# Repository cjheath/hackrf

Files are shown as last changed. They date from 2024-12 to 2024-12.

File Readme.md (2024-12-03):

# HackRF

This repository contains hardware designs and software for HackRF,
a low cost, open source Software Defined Radio platform.

HackRF One

(photo by fd0 from https://github.com/fd0/hackrf-one-pictures)

principal author: Michael Ossmann <mike@ossmann.com>

Information on HackRF and purchasing HackRF: https://greatscottgadgets.com/hackrf/

--------------------

# Documentation

Documentation for HackRF can be viewed on [Read the Docs](https://hackrf.readthedocs.io/en/latest/). The raw documentation files for HackRF are in the [docs folder](https://github.com/mossmann/hackrf/tree/master/docs) in this repository and can be built locally by installing [Sphinx Docs](https://www.sphinx-doc.org/en/master/usage/installation.html) and running `make html`. Documentation changes can be submitted through pull request and suggestions can be made as GitHub issues. 

To create a PDF of the HackRF documentation from the HackRF repository while on Ubuntu:
* run `sudo apt install latexmk texlive-latex-extra`
* navigate to hackrf/docs on command line
* run the command `make latex`
* run the command `make latexpdf`

--------------------

# Getting Help

Before asking for help with HackRF, check to see if your question is listed in the [FAQ](https://hackrf.readthedocs.io/en/latest/faq.html).

For assistance with HackRF general use or development, please look at the [issues on the GitHub project](https://github.com/greatscottgadgets/hackrf/issues). This is the preferred place to ask questions so that others may locate the answer to your question in the future.

We invite you to join our community discussions on [Discord](https://discord.gg/rsfMw3rsU8). Note that while technical support requests are welcome here, we do not have support staff on duty at all times. Be sure to also submit an issue on GitHub if you've found a bug or if you want to ensure that your request will be tracked and not overlooked.

If you wish to see past discussions and questions about HackRF, you may also view the [mailing list archives](https://pairlist9.pair.net/pipermail/hackrf-dev/).

GitHub issues on this repository that are labelled "technical support" by Great Scott Gadgets employees can expect a response time of two weeks. We currently do not have expected response times for other GitHub issues or pull requests for this repository.

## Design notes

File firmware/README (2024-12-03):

The primary firmware source code for USB HackRF devices is hackrf_usb.  Most of
the other directories contain firmware source code for test and development.
The common directory contains source code shared by multiple HackRF firmware
projects.  The cpld directory contains HDL source for the CPLD.

The firmware is set up for compilation with the GCC toolchain available here:

https://developer.arm.com/open-source/gnu-toolchain/gnu-rm/downloads

Required dependency:

https://github.com/mossmann/libopencm3

If you are using git, the preferred way to install libopencm3 is to use the
submodule:

$ cd ..
$ git submodule init
$ git submodule update

To build and install a standard firmware image for HackRF One:

$ cd hackrf_usb
$ mkdir build
$ cd build
$ cmake ..
$ make
$ hackrf_spiflash -w hackrf_usb.bin

If you have a Jawbreaker, add -DBOARD=JAWBREAKER to the cmake command.
If you have a rad1o, use -DBOARD=RAD1O instead.

If you get the "`arm-none-eabi-gcc` is not a full path and was not found in the PATH"
error during `cmake ..`, install the
[ARM GNU toolchain](https://developer.arm.com/Tools%20and%20Software/GNU%20Toolchain).
This toolchain is pre-packaged on many platforms and distributions, e.g. on Debian/Ubuntu
you can run `sudo apt-get install gcc-arm-none-eabi` to install it.

If you get the "ModuleNotFoundError: No module named 'yaml'" error during `make`,
run `pip install pyyaml` to install the Python yaml pip package.

It is possible to use a USB Device Firmware Upgrade (DFU) method to load
firmware into RAM.  This is normally only required to recover a device that has
had faulty firmware loaded, but it can also be useful for firmware developers.

For loading firmware into RAM with DFU you will need:

http://dfu-util.sourceforge.net/

To start up HackRF One in DFU mode, hold down the DFU button while powering it
on or while pressing and releasing the RESET button.  Release the DFU button
after the 3V3 LED illuminates.

A .dfu file is built by default when building firmware.  Alternatively you can
use a known good .dfu file from a release package.  Load the firmware into RAM
with:

$ dfu-util --device 1fc9:000c --alt 0 --download hackrf_usb.dfu

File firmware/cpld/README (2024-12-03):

The primary CPLD image is: sgpio_if/default.xsvf

This is a binary file built from HDL source in sgpio_if.  You do not need
Xilinx tools unless you want to make your own modifications.

CPLD images are automatically included in HackRF firmware.  You do not normally
need to update the bitstream stored in the CPLD's flash memory as it is
superseded by the image loaded into SRAM by the firmware.

If you want to update the bitstream in CPLD flash for some reason, first update
the firmware, libhackrf, and hackrf-tools.
Then:

$ hackrf_cpldjtag -x sgpio_if/default.xsvf

After a few seconds, three LEDs should start blinking.  This indicates that the
CPLD has been programmed successfully.  Reset the HackRF device by pressing the
RESET button or by unplugging it and plugging it back in.

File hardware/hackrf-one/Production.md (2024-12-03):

## Making files for production of HackRF One

### Check everything

In eeschema, run Inspect->Electrical Rules Checker

### BOM

In eeschema (schematic editor), select "Tools->Generate Bill of Materials".
Click Export. This creates the file doc/hardware/hackrf-one-gerbers/hackrf-one-bom.csv

### Assembly silk with references

In pcbnew (the PCB editor) select File->Plot....
* Ensure F.SilkS (front silk) layer is selected.
* Select "Use drill/place file origin".
* Deselect "Use Protel filename extensions".
* De-select "Generate Gerber job file".
* Select "Plot reference designators"
* Click "Plot". This puts files into doc/hardware/hackrf-one-gerbers.
* Rename doc/hardware/hackrf-one-gerbers/hackrf-one-F_Silkscreen.gto to doc/hardware/hackrf-one-gerbers/hackrf-one-Placement.gbr

### Gerber files

In pcbnew (the PCB editor) select "Plot...".
* Ensure all required layers are selected: C1F, C2, C3, C4B, F.Paste, F.SilkS, F.Mask, B.Mask, Edge.Cuts
* De-select "Plot references designators"
* Click "Plot".

This puts files into doc/hardware/hackrf-one-gerbers. Change to that directory.

### Drill file

From pcbnew->Plot, select "Generate Drill Files".
* Select "Excellon".
* Tick "Minimal header"
* Tick "PTH and NPTH in single file"
* Select Drill Origin "Drill/place file origin"
* Select Drill Units "Inches"
* Select Zeros Format "Suppress trailing zeros"
* Click "Generate Drill File"

This creates the file "doc/hardware/hackrf-one-gerbers/hackrf-one.drl"

* Click "Generate Map File"
* Click "Generate Report File" and Save

### Placement file

In pcbnew, select File->Fabrication Outputs->Component Placement (.pos) File
Select CSV, Inches, Single file per board.
Click "Generate Position File"
This makes the file doc/hardware/hackrf-one-gerbers/hackrf-one-all-pos.csv

Check the rotation of U3, the low-pass filter. Its footprint is 180 from how they come off the reel.

### Zip it up

cd into doc/hardware/hackrf-one-gerbers
zip -j ../hackrf-one-fabrication-draft-YYYY-NN-DD.zip ../README.production *

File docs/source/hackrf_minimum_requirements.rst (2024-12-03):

============================================
Minimum Host System Requirements for HackRF
============================================

HackRF requires you to supply 500 mA at 5 V DC to your HackRF via the USB port. If your host computer has difficulty meeting this requirement, you may need to use a powered USB hub.

There is no specific minimum CPU requirement for the host computer when using a HackRF, but SDR is generally a CPU-intensive application. If you have a slower CPU, you may be unable to run certain SDR software or you may only be able to operate at lower sample rates.

Most users will want to stream data to or from the HackRF at high speeds. This requires that the host computer supports Hi-Speed USB. Some Hi-Speed USB hosts are better than others, and you may have multiple host controllers on your computer. If you have difficulty operating your HackRF at high sample rates (10 Msps to 20 Msps), try using a different USB port on your computer. If possible, arrange things so that the HackRF is the only device on the bus.

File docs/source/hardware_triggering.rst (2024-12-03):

===================
Hardware Triggering
===================

HackRF One transmit and receive operations can be synchronized with another HackRF One or with other external equipment by using the trigger input and output on pin header P28. Triggering provides time synchronization with error of less than one sample period.

Clock Synchronization
~~~~~~~~~~~~~~~~~~~~~

When triggering one HackRF One from another, it is often desirable to first ensure that the two devices share a common frequency reference. This has an added benefit of grounding the HackRFs to each other, eliminating one of the wires required for triggering. See :ref:`External Clock Interface <external_clock_interface>` for instructions.

Either HackRF One may serve as the clock source for the other regardless of which is providing the trigger output.

Requirements
~~~~~~~~~~~~

To connect two HackRF Ones for triggering you will need:

    * a male-to-male jumper wire for 0.1" pin headers
    * an SMA cable for clock synchronization or a second jumper wire

.. _open_your_hackrf_one:

Open Your HackRF One
~~~~~~~~~~~~~~~~~~~~

If your HackRF Ones are not bare boards, you will need to open up their cases to access the pin headers on the HackRF Ones. Each HackRF One case has small plastic clips holding it together. These clips may be damaged when the case is opened, but typically the case can still be used after such damage. Please follow the instructions in `this video <https://www.youtube.com/watch?v=zuXJtpTSEJM>`__ by `Jared Boone <https://twitter.com/sharebrained>`__ to open your HackRF One cases.

Identify the Trigger Pins
~~~~~~~~~~~~~~~~~~~~~~~~~

HackRF One has four normally-populated pin headers, three of which are arranged in a 'C' shape. On the circuit board these are marked P28, P22, and P20. P28 is the header nearest to the center of the board. Locate pins 15 (trigger output) and 16 (trigger input) on header P28.

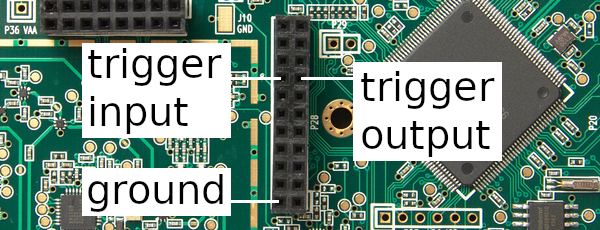
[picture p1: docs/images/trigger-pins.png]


Connect the Trigger Output to the Trigger Input
~~~~~~~~~~~~~~~~~~~~~~~~~~~~~~~~~~~~~~~~~~~~~~~

First ensure that the two devices share a common ground. This may be accomplished by connecting one's CLKIN to the other's CLKOUT as recommended above. Alternatively, connect a jumper wire from P28 pin 2 on one HackRF One to P28 pin 2 on the other HackRF One.

Next use a jumper wire to connect P28 pin 15 (trigger output) on one HackRF One to P28 pin 16 (trigger input) on the other HackRF One.

Usage
~~~~~

Use ``hackrf_info`` to discover the serial numbers of both HackRF Ones. Using the serial number of the HackRF One to be triggered, use ``hackrf_transfer -H`` to set up a triggered operation. For example:

* ``hackrf_transfer -H -d <serial number> -a 0 -l 32 -g 32 -r rx1.cs8``

The command will print "Waiting for trigger..." until a trigger signal is detected on the device's trigger input.

In another terminal, use the serial number of the triggering HackRF One to initiate an operation to take place at the same time as the triggered operation. For example:

* ``hackrf_transfer -d <serial number> -a 0 -l 32 -g 32 -r rx2.cs8``

Note that no special argument is required to activate the trigger output.

Both ``hackrf_transfer`` commands will start sampling RF signals at the same time, accurate to less than one sample period.

Additional Devices
~~~~~~~~~~~~~~~~~~

Multiple HackRF Ones may be triggered by a single HackRF One. Ensure that all the devices share a common ground and then connect one device's trigger output to the trigger inputs of the other devices (with jumpers connected via a breadboard, for example).

Equipment other than a HackRF One may be connected to a HackRF One's trigger input or output. The trigger signal is a 3.3 V pulse that triggers on the rising edge.

References
~~~~~~~~~~

HackRF's trigger mechanism was contributed by the authors of `Synchronisation of Low-Cost Open Source SDRs for Navigation Applications <http://spcomnav.uab.es/docs/conferences/Bartolucci_NAVITEC_2016.pdf>`__ which provides details about the implementation and background.

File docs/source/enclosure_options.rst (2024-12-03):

Enclosure Options
~~~~~~~~~~~~~~~~~

The commercial version of HackRF One from Great Scott Gadgets ships with an injection molded plastic enclosure, but it is designed to fit two optional enclosures:

    * Hammond 1455J1201: HackRF One fits this extruded aluminum enclosure and other similar models from Hammond Manufacturing. In order to use the enclosure's end plates, you will have to drill them. An end plate template can be found in the HackRF One KiCad layout.

    * Acrylic sandwich: You can also use a laser cut acrylic enclosure with HackRF One. This is a good option for access to the expansion headers. A design can be found in the HackRF One hardware directory. Use any laser cutting service or purchase from a `reseller <https://greatscottgadgets.com/hackrf/acrylic-case/>`__.

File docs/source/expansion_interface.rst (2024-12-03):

Expansion Interface
~~~~~~~~~~~~~~~~~~~

The HackRF One expansion interface consists of headers P9, P20, P22, and P28. These four headers are installed on the commercial HackRF One from Great Scott Gadgets.

P9 Baseband 
^^^^^^^^^^^

A direct analog interface to the high speed dual ADC and dual DAC.

.. list-table :: 
  :header-rows: 1
  :widths: 1 1 

  * - Pin
    - Function
  * - 1     
    - GND
  * - 2   
    - GND
  * - 3
    - GND
  * - 4   
    - RXBBQ-
  * - 5   
    - RXBBI-
  * - 6   
    - RXBBQ+
  * - 7   
    - RXBBI+
  * - 8   
    - GND
  * - 9   
    - GND
  * - 10  
    - TXBBI-
  * - 11  
    - TXBBQ+
  * - 12  
    - TXBBI+
  * - 13  
    - TXBBQ-
  * - 14  
    - GND
  * - 15  
    - GND
  * - 16  
    - GND

P20 GPIO
^^^^^^^^

Providing access to GPIO, ADC, RTC, and power.

.. list-table :: 
  :header-rows: 1
  :widths: 1 1 

  * - Pin 
    - Function
  * - 1   
    - VBAT
  * - 2   
    - RTC_ALARM
  * - 3   
    - VCC
  * - 4   
    - WAKEUP
  * - 5   
    - GPIO3_8
  * - 6   
    - GPIO3_0
  * - 7   
    - GPIO3_10
  * - 8   
    - GPIO3_11
  * - 9   
    - GPIO3_12
  * - 10  
    - GPIO3_13
  * - 11  
    - GPIO3_14
  * - 12  
    - GPIO3_15
  * - 13  
    - GND
  * - 14  
    - ADC0_6
  * - 15  
    - GND
  * - 16  
    - ADC0_2
  * - 17  
    - VBUSCTRL
  * - 18  
    - ADC0_5
  * - 19  
    - GND
  * - 20  
    - ADC0_0
  * - 21  
    - VBUS
  * - 22  
    - VIN

P22 I2S
^^^^^^^

I2S, SPI, I2C, UART, GPIO, and clocks.

.. list-table :: 
  :header-rows: 1
  :widths: 1 1 

  * - Pin     
    - Function
  * - 1   
    - CLKOUT
  * - 2   
    - CLKIN
  * - 3   
    - RESET
  * - 4   
    - GND
  * - 5   
    - I2C1_SCL
  * - 6   
    - I2C1_SDA
  * - 7   
    - SPIFI_MISO
  * - 8   
    - SPIFI_SCK
  * - 9   
    - SPIFI_MOSI
  * - 10  
    - GND
  * - 11  
    - VCC
  * - 12  
    - I2S0_RX_SCK
  * - 13  
    - I2S_RX_SDA
  * - 14  
    - I2S0_RX_MCLK
  * - 15  
    - I2S0_RX_WS
  * - 16  
    - I2S0_TX_SCK
  * - 17  
    - I2S0_TX_MCLK
  * - 18  
    - GND
  * - 19  
    - U0_RXD
  * - 20  
    - U0_TXD
  * - 21  
    - P2_9
  * - 22  
    - P2_13
  * - 23  
    - P2_8
  * - 24  
    - SDA
  * - 25  
    - CLK6
  * - 26  
    - SCL

P28 SD
^^^^^^

SDIO, GPIO, clocks, and CPLD.

.. list-table :: 
  :header-rows: 1
  :widths: 1 1 

  * - Pin     
    - Function
  * - 1   
    - VCC
  * - 2   
    - GND
  * - 3   
    - SD_CD
  * - 4   
    - SD_DAT3
  * - 5   
    - SD_DAT2
  * - 6   
    - SD_DAT1
  * - 7   
    - SD_DAT0
  * - 8   
    - SD_VOLT0
  * - 9   
    - SD_CMD
  * - 10  
    - SD_POW
  * - 11  
    - SD_CLK
  * - 12  
    - GND
  * - 13  
    - GCK2
  * - 14  
    - GCK1
  * - 15  
    - B1AUX14 (trigger output)
  * - 16  
    - B1AUX13 (trigger input)
  * - 17  
    - CPLD_TCK
  * - 18  
    - BANK2F3M2
  * - 19  
    - CPLD_TDI
  * - 20  
    - BANK2F3M6
  * - 21  
    - BANK2F3M12
  * - 22  
    - BANK2F3M4

Additional unpopulated headers and test points are available for test and development, but they may be incompatible with some enclosure or expansion options.

Refer to the schematics and component documentation for more information.

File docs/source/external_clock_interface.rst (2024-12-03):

===========================================
External Clock Interface (CLKIN and CLKOUT)
===========================================

.. _external_clock_interface:

HackRF One produces a 10 MHz clock signal on CLKOUT. The signal is a 3.3 V, 10 MHz square wave intended for a high impedance load.

The CLKIN port on HackRF One is a high impedance input that expects 3.3 V square wave at 10 MHz. Do not exceed 3.3 V or drop below 0 V on this input. Do not connect a clock signal at a frequency other than 10 MHz (unless you modify the firmware to support this). You may directly connect the CLKOUT port of one HackRF One to the CLKIN port of another HackRF One.

HackRF One uses CLKIN instead of the internal crystal when a clock signal is detected on CLKIN. The switch to or from CLKIN only happens when a transmit or receive operation begins.

To verify that a signal has been detected on CLKIN, use ``hackrf_clock -i``. The expected output with a clock detected is `CLKIN status: clock signal detected`. The expected output with no clock detected is `CLKIN status: no clock signal detected`.

To activate CLKOUT, use ``hackrf_clock -o 1``. To switch it off, use ``hackrf_clock -o 0``.

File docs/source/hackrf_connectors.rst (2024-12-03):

==========
Connectors
==========

The connectors on HackRF One are SMA. 

**Note:** SMA connectors and RP-SMA connectors are visually very similar. If you connect an RP-SMA antenna to HackRF One, it will seem to connect snugly but won't function at all because neither the male nor female side has a center pin. RP-SMA connectors are most common on 2.4 GHz antennas and are popular on Wi-Fi equipment. Adapters are available.

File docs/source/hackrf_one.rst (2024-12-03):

================================================
HackRF One
================================================

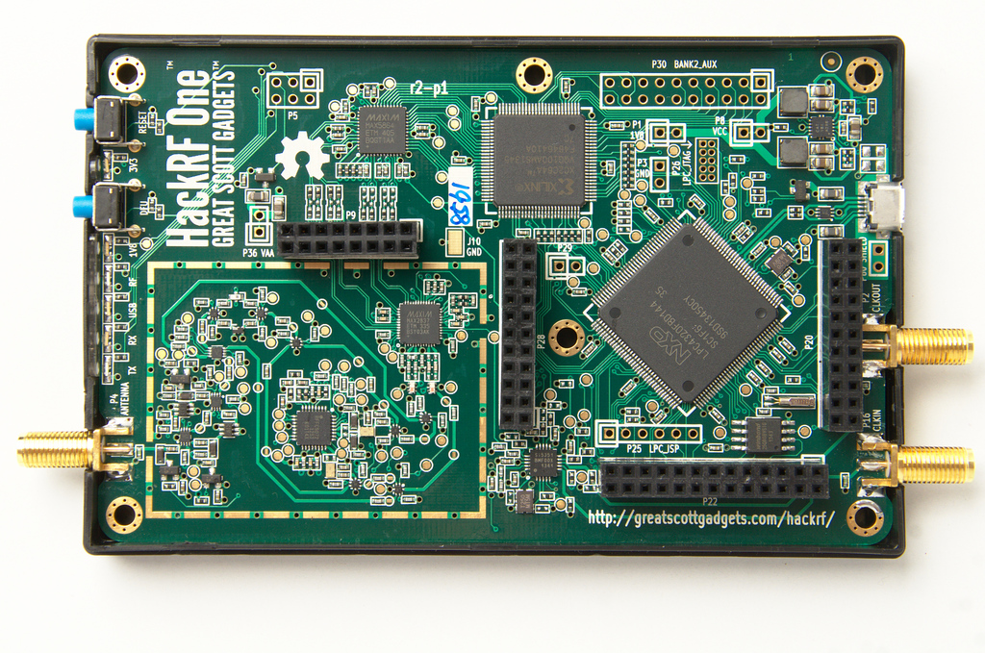
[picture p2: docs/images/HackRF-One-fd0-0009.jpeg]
HackRF One


HackRF One is the current hardware platform for the HackRF project. It is a Software Defined Radio peripheral capable of transmission or reception of radio signals from 1 MHz to 6 GHz. Designed to enable test and development of modern and next generation radio technologies, HackRF One is an open source hardware platform that can be used as a USB peripheral or programmed for stand-alone operation.

Features
~~~~~~~~

    * half-duplex transceiver
    * operating freq: 1 MHz to 6 GHz
    * supported sample rates: 2 Msps to 20 Msps (quadrature)
    * resolution: 8 bits
    * interface: High Speed USB (with USB Micro-B connector)
    * power supply: USB bus power
    * software-controlled antenna port power (max 50 mA at 3.0 to 3.3 V)
    * SMA female antenna connector (50 ohms)
    * SMA female clock input and output for synchronization
    * convenient buttons for programming
    * pin headers for expansion
    * portable
    * open source

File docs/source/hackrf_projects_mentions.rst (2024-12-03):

================================================
HackRF Community Projects and Mentions
================================================

Have you done something cool with HackRF or mentioned HackRF in one of your presentations? Let us know and we might post a link here!

* `HackRF vs. Tesla Model S <https://www.youtube.com/watch?v=575TcQJJWok>`__ (Sam Edwards)
* `Jawbreaker/VFD spectrum analyzer <http://www.sharebrained.com/2013/05/21/maker-faire-radio-spectrum-analyzer/>`__ (Jared Boone)
* `LEGO car <http://ossmann.blogspot.com/2013/06/hackrf-lego-car.html>`__ (Michael Ossmann)
* `wireless microphones <http://www.sharebrained.com/2013/06/15/wireless-microphones-and-hackrf/>`__ (Jared Boone)
* `Tesla Charging Port Opener <https://github.com/rgerganov/tesla-opener>`__ (Radoslav Gerganov)
* `Hacking my smart tooth brush <https://kuenzi.dev/toothbrush/>`__ (Cyrill Künzi)

Retired Projects
~~~~~~~~~~~~~~~~

* Automotive Remote Keyless Entry Systems (Mike Kershaw)
* Decoding Pocsag Pagers With The HackRF (BinaryRF)
* Sniffing GSM with HackRF (BinaryRF)

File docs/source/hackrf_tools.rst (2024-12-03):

============
HackRF Tools
============

Great Scott Gadgets provides some commandline tools for interacting with HackRF. 
    * **hackrf_info** Read device information from HackRF such as serial number and firmware version.

    * **hackrf_transfer** Send and receive signals using HackRF. Input/output files are 8-bit signed quadrature samples.

    * **hackrf_sweep**, a command-line spectrum analyzer.

    * **hackrf_clock** Read and write clock input and output configuration.

    * **hackrf_operacake** Configure Opera Cake antenna switch connected to HackRF.

    * **hackrf_spiflash** A tool to write new firmware to HackRF. See: :ref:`Updating Firmware <updating_firmware>`.

    * **hackrf_debug** Read and write registers and other low-level configuration for debugging.

hackrf_sweep
~~~~~~~~~~~~

Usage
^^^^^

.. code-block:: sh 

    [-h] # this help
    [-d serial_number] # Serial number of desired HackRF
    [-a amp_enable] # RX RF amplifier 1=Enable, 0=Disable
    [-f freq_min:freq_max] # minimum and maximum frequencies in MHz
    [-p antenna_enable] # Antenna port power, 1=Enable, 0=Disable
    [-l gain_db] # RX LNA (IF) gain, 0-40dB, 8dB steps
    [-g gain_db] # RX VGA (baseband) gain, 0-62dB, 2dB steps
    [-w bin_width] # FFT bin width (frequency resolution) in Hz, 2445-5000000
    [-1] # one shot mode
    [-N num_sweeps] # Number of sweeps to perform
    [-B] # binary output
    [-I] # binary inverse FFT output
    -r filename # output file

Output fields
^^^^^^^^^^^^^

``date, time, hz_low, hz_high, hz_bin_width, num_samples, dB, dB, ...``

Running ``hackrf_sweep -f 2400:2490`` gives the following example results:

.. list-table :: 
  :header-rows: 1
  :widths: 1 1 1 1 1 1 1 1 1 1 1

  * - Date  
    - Time  
    - Hz Low    
    - Hz High   
    - Hz bin width  
    - Num Samples   
    - dB    
    - dB    
    - dB    
    - dB    
    - dB
  * - 2019-01-03    
    - 11:57:34.967805   
    - 2400000000    
    - 2405000000    
    - 1000000.00    
    - 20    
    - -64.72    
    - -63.36    
    - -60.91    
    - -61.74    
    - -58.58
  * - 2019-01-03    
    - 11:57:34.967805   
    - 2410000000    
    - 2415000000    
    - 1000000.00    
    - 20    
    - -69.22    
    - -60.67    
    - -59.50    
    - -61.81    
    - -58.16
  * - 2019-01-03    
    - 11:57:34.967805   
    - 2405000000    
    - 2410000000    
    - 1000000.00    
    - 20    
    - -61.19    
    - -70.14    
    - -60.10    
    - -57.91    
    - -61.97
  * - 2019-01-03    
    - 11:57:34.967805   
    - 2415000000    
    - 2420000000    
    - 1000000.00    
    - 20    
    - -72.93    
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

Each sweep across the entire specified frequency range is given a single time stamp.

The fifth column tells you the width in Hz (1 MHz in this case) of each frequency bin, which you can set with ``-w``. The sixth column is the number of samples analyzed to produce that row of data.

Each of the remaining columns shows the power detected in each of several frequency bins. In this case there are five bins, the first from 2400 to 2401 MHz, the second from 2401 to 2402 MHz, and so forth.

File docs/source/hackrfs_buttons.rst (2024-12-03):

=======
Buttons
=======

The **RESET button** resets the microcontroller. This is a reboot that should result in a USB re-enumeration.

The **DFU button** invokes a USB DFU bootloader located in the microcontroller's ROM. This bootloader makes it possible to unbrick a HackRF One with damaged firmware because the ROM cannot be overwritten.

The DFU button only invokes the bootloader during reset. This means that it can be used for other functions by custom firmware.

To invoke DFU mode: Press and hold the DFU button. While holding the DFU button, reset the HackRF One either by pressing and releasing the RESET button or by powering on the HackRF One. Release the DFU button.

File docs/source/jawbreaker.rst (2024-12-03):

==========
Jawbreaker
==========

HackRF Jawbreaker is the beta test hardware platform for the HackRF project.

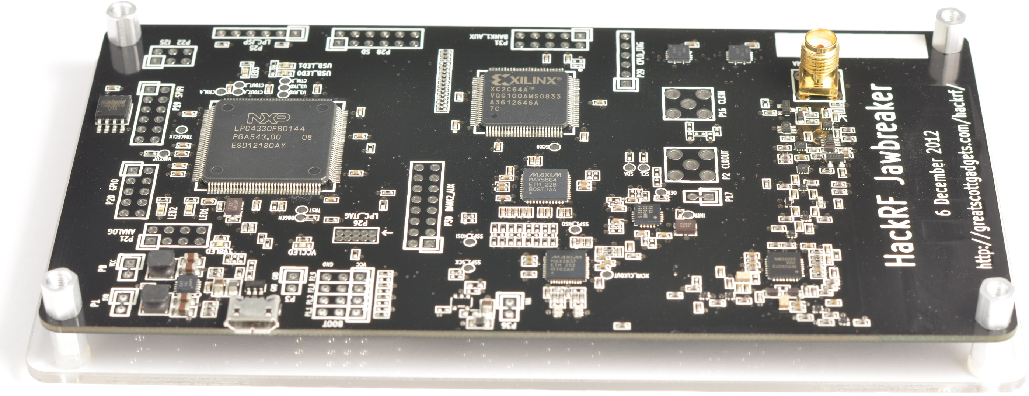
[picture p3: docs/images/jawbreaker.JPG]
Jawbreaker


(Jawbreaker picture provided by `fd0 <https://github.com/fd0>`__ with Creative Commons License CC BY 3.0.)

Features
~~~~~~~~

    * half-duplex transceiver
    * operating freq: 30 MHz to 6 GHz
    * supported sample rates: 8 Msps to 20 Msps (quadrature)
    * resolution: 8 bits
    * interface: High Speed USB (with USB Micro-B connector)
    * power supply: USB bus power
    * portable
    * open source

Hardware Documentation
~~~~~~~~~~~~~~~~~~~~~~

Schematic diagram, assembly diagram, and bill of materials can be found at `https://github.com/greatscottgadgets/hackrf/tree/master/hardware <https://github.com/greatscottgadgets/hackrf/tree/master/hardware>`__

Transmit Power
~~~~~~~~~~~~~~

The maximum TX power for Jawbreaker varies by operating frequency:

    * 30 MHz to 100 MHz: 5 dBm to 15 dBm, increasing as frequency decreases
    * 100 MHz to 2300 MHz: 0 dBm to 10 dBm, increasing as frequency decreases
    * 2170 MHz to 2740 MHz: 10 dBm to 15 dBm
    * 2700 MHz to 4000 MHz: -5 dBm to 5 dBm, increasing as frequency decreases
    * 4000 MHz to 6000 MHz: -15 dBm to 0 dBm, increasing as frequency decreases

Overall, the output power is enough to perform over-the-air experiments at close range or to drive an external amplifier. If you connect an external amplifier, you should also use an external bandpass filter for your operating frequency.

Before you transmit, know the laws for the region you are transmitting in. Jawbreaker has not been tested for compliance with regulations governing transmission of radio signals. You are responsible for using your Jawbreaker legally.

SMA, not RP-SMA
~~~~~~~~~~~~~~~

The connectors on Jawbreaker are SMA, not RP-SMA. SMA connectors and RP-SMA connectors look extremely similar, the difference is that SMA connectors have a center pin. RP-SMA connectors are common on 2.4 GHz antennas and are popular on Wi-Fi equipment. If you connect an RP-SMA antenna to Jawbreaker, it will seem to connect snugly but won't function at all because neither the male nor female side has a center pin. 

Recommended PCB and Antenna Changes
~~~~~~~~~~~~~~~~~~~~~~~~~~~~~~~~~~~

Jawbreaker has an SMA antenna connector and it also includes a built-in PCB antenna intended for operation near 900 MHz. The built-in PCB antenna isn't a very good antenna. A paperclip stuck into the SMA connector of the Jawbreaker is likely to be better. We recommend that you free your Jawbreaker to operate with better antennas by cutting the PCB trace to the PCB antenna with a knife. This enables the SMA connector to be used without interference from the PCB antenna.

The trace to be cut is between the two solder pads inside a box labeled R44. There is an arrow printed on the board that points to the R44 box. A video that demonstrates the antenna modification is on YouTube: `HackRF Antenna Modification <http://youtu.be/B2gwgNoqMxI>`__.

Due to a manufacturing error, there is solder on the pads in box R44 that you should try to remove before you cut the trace. R44 may appear as a single solder blob. If you have a soldering iron and solder wick/braid, use a soldering iron and fine solder wick to remove as much solder as you can from the two R44 pads. Then, use a pen knife to gently cut away the area between the two R44 pads. Make multiple, gentle cuts, instead of one or two forceful cuts. As you cut, you'll break through the black solder mask, then the copper trace between the pads, and stop when you reach fiberglass. Remove the copper trace completely, so just the two R44 pads remain. Use a multimeter or continuity tester to verify that the two R44 pads are no longer connected. If you don't have a soldering iron, you can cut through the copper trace and the solder blob all at once, but it requires a bit more effort. The only reason not to cut the PCB trace is if you want to try Jawbreaker but don't have any antenna with an SMA connector (or adapter).

If you want to restore the PCB antenna for some reason, you can install a 10 nF capacitor or a 0 ohm resistor on the R44 pads or you may be able to simply create a solder bridge.

Expansion Interface
~~~~~~~~~~~~~~~~~~~

LPC
^^^
Boot config
+++++++++++

Default boot configuration is SPIFI. Install headers and jumpers (and optionally resistors) to reconfigure.

.. list-table :: 
  :header-rows: 1
  :widths: 1 1 1 1 1

  * - Pin 	
    - P43 	
    - P32 	
    - P42 	
    - P27
  * - 1 	
    - VCC 	
    - VCC 	
    - VCC 	
    - VCC
  * - 2 	
    - P2_9 	
    - P2_8 	
    - P1_2 	
    - P1_1
  * - 3 	
    - GND 	
    - GND 	
    - GND 	
    - GND

The table below shows which pins to short per header for a given selection.

.. list-table :: 
  :header-rows: 1
  :widths: 1 1 1 1 1

  * - Selection 	
    - P43 	
    - P32 	
    - P42 	
    - P27
  * - USART0 	
    - 2-3 	
    - 2-3 	
    - 2-3 	
    - 2-3
  * - SPIFI 	
    - 2-3 	
    - 2-3 	
    - 2-3 	
    - 1-2
  * - USB0 	
    - 2-3 	
    - 1-2 	
    - 2-3 	
    - 1-2
  * - USSP0 	
    - 2-3 	
    - 1-2 	
    - 1-2 	
    - 1-2
  * - USART3 	
    - 1-2 	
    - 2-3 	
    - 2-3 	
    - 2-3

P19 SPIFI Intercept header
++++++++++++++++++++++++++

Traces may be cut to install header and jumpers or use off-board SPI flash.

.. list-table :: 
  :header-rows: 1
  :widths: 1 1

  * - Pin 	
    - Function
  * - 1 	
    - Flash DO
  * - 2 	
    - SPIFI_MISO
  * - 3 	
    - Flash DI
  * - 4 	
    - SPIFI_MOSI
  * - 5 	
    - Flash CLK
  * - 6 	
    - SPIFI_SCK
  * - 7 	
    - Flash CS
  * - 8 	
    - SPIFI_CS
  * - 9 	
    - Flash Hold
  * - 10 	
    - SPIFI_SIO3
  * - 11 	
    - Flash WP
  * - 12 	
    - SPIFI_SIO2

P20 GPIO
++++++++

.. list-table :: 
  :header-rows: 1
  :widths: 1 1

  * - Pin 	
    - Function
  * - 1 	
    - GPIO3_8
  * - 2 	
    - GPIO3_9
  * - 3 	
    - GPIO3_10
  * - 4 	
    - GPIO3_11
  * - 5 	
    - GPIO3_12
  * - 6 	
    - GPIO3_13
  * - 7 	
    - GPIO3_14
  * - 8 	
    - GPIO3_15
  * - 9 	
    - GND
  * - 10 	
    - GND

P21 Analog
++++++++++

.. list-table :: 
  :header-rows: 1
  :widths: 1 1

  * - Pin 	
    - Function
  * - 1 	
    - GND
  * - 2 	
    - ADC0_6
  * - 3 	
    - GND
  * - 4 	
    - ADC0_2
  * - 5 	
    - GND
  * - 6 	
    - ADC0_5
  * - 7 	
    - GND
  * - 8 	
    - ADC0_0

P22 I2S
+++++++

.. list-table :: 
  :header-rows: 1
  :widths: 1 1

  * - Pin 	
    - Function
  * - 1 	
    - VCC
  * - 2 	
    - I2S0_TX_SDA
  * - 3 	
    - I2S0_TX_WS
  * - 4 	
    - I2S0_TX_SCK
  * - 5 	
    - I2S0_TX_MCLK
  * - 6 	
    - GND

P25 LPC_ISP
+++++++++++

.. list-table :: 
  :header-rows: 1
  :widths: 1 1

  * - Pin 	
    - Function
  * - 1 	
    - GND
  * - 2 	
    - ISP
  * - 3 	
    - NC
  * - 4 	
    - U0_RXD
  * - 5 	
    - U0_TXD
  * - 6 	
    - RESET

P26 LPC_JTAG
++++++++++++

.. list-table :: 
  :header-rows: 1
  :widths: 1 1

  * - Pin 	
    - Function
  * - 1 	
    - VCC
  * - 2 	
    - TMS
  * - 3 	
    - GND
  * - 4 	
    - TCK
  * - 5 	
    - GND
  * - 6 	
    - TDO
  * - 7 	
    - NC
  * - 8 	
    - TDI
  * - 9 	
    - GND
  * - 10 	
    - RESET

P28 SD
++++++

.. list-table :: 
  :header-rows: 1
  :widths: 1 1

  * - Pin 	
    - Function
  * - 1 	
    - GND
  * - 2 	
    - VCC
  * - 3 	
    - SD_CD
  * - 4 	
    - SD_DAT3
  * - 5 	
    - SD_DAT2
  * - 6 	
    - SD_DAT1
  * - 7 	
    - SD_DAT0
  * - 8 	
    - SD_VOLT0
  * - 9 	
    - SD_CMD
  * - 10 	
    - SD_POW
  * - 11 	
    - SD_CLK
  * - 12 	
    - NC

CPLD
^^^^

P29 CPLD_JTAG
+++++++++++++

.. list-table :: 
  :header-rows: 1
  :widths: 1 1

  * - Pin 	
    - Function
  * - 1 	
    - CPLD_TMS
  * - 2 	
    - CPLD_TDI
  * - 3 	
    - CPLD_TDO
  * - 4 	
    - CPLD_TCK
  * - 5 	
    - GND
  * - 6 	
    - NCC

P30 BANK2_AUX
+++++++++++++

.. list-table :: 
  :header-rows: 1
  :widths: 1 1

  * - Pin 	
    - Function
  * - 1 	
    - B2AUX1
  * - 2 	
    - B2AUX2
  * - 3 	
    - B2AUX3
  * - 4 	
    - B2AUX4
  * - 5 	
    - B2AUX5
  * - 6 	
    - B2AUX6
  * - 7 	
    - B2AUX7
  * - 8 	
    - B2AUX8
  * - 9 	
    - B2AUX9
  * - 10 	
    - B2AUX10
  * - 11 	
    - B2AUX11
  * - 12 	
    - B2AUX12
  * - 13 	
    - B2AUX13
  * - 14 	
    - B2AUX14
  * - 15 	
    - B2AUX15
  * - 16 	
    - B2AUX16

P31 BANK1_AUX
+++++++++++++

.. list-table :: 
  :header-rows: 1
  :widths: 1 1

  * - Pin 	
    - Function
  * - 1 	
    - B1AUX9
  * - 2 	
    - B1AUX10
  * - 3 	
    - B1AUX11
  * - 4 	
    - B1AUX12
  * - 5 	
    - B1AUX13
  * - 6 	
    - B1AUX14
  * - 7 	
    - B1AUX15    
  * - 8 	
    - B1AUX16
  * - 9 	
    - GND
  * - 10 	
    - GND

External clock
^^^^^^^^^^^^^^

P2 CLKOUT
+++++++++

Install C165 and R92 as necessary to match output. For CMOS output, install 0 ohm resistor in place of C165; do not install R92.

.. list-table :: 
  :header-rows: 1
  :widths: 1 1

  * - Pin 	
    - Function
  * - 1 	
    - CLKOUT
  * - 2 	
    - GND
  * - 3 	
    - GND
  * - 4 	
    - GND
  * - 5 	
    - GND

P16 CLKIN
+++++++++

Install C118, C164, R45, R84 and R85 as necessary to match input.

For CMOS input, install 0 ohm resistors in place of C118 and C164; do not install R45, R84, or R85.

.. list-table :: 
  :header-rows: 1
  :widths: 1 1

  * - Pin 	
    - Function
  * - 1 	
    - CLKIN
  * - 2 	
    - GND
  * - 3 	
    - GND
  * - 4 	
    - GND
  * - 5 	
    - GND

P17 CLKIN_JMP
+++++++++++++

Cut P17 short (trace) to enable external clock input. If short is cut, a jumper should be used on P17 at all times when an external clock is not connected to P16.

.. list-table :: 
  :header-rows: 1
  :widths: 1 1

  * - Pin 	
    - Function
  * - 1 	
    - GND
  * - 2 	
    - CLKIN

More
^^^^

Additional headers are available. See the `board files <https://github.com/greatscottgadgets/hackrf/tree/master/hardware/jawbreaker>`__ for additional details.

Differences between Jawbreaker and HackRF One
~~~~~~~~~~~~~~~~~~~~~~~~~~~~~~~~~~~~~~~~~~~~~

Jawbreaker was the beta platform that preceded HackRF One. HackRF One incorporates the following changes and enhancements (at minimum):

    * Antenna port: No modification is necessary to use the SMA antenna port on HackRF One.
    * PCB antenna: Removed.
    * Size: HackRF One is smaller at 120 mm x 75 mm (PCB size).
    * Enclosure: The commercial version of HackRF One from Great Scott Gadgets ships with an injection molded plastic enclosure. HackRF One is also designed to fit other enclosure options.
    * Buttons: HackRF One has a RESET button and a DFU button for easy programming.
    * Clock input and output: Installed and functional without modification.
    * USB connector: HackRF One features a new USB connector and improved USB layout.
    * Expansion interface: More pins are available for expansion, and pin headers are installed on HackRF One.
    * Real-Time Clock: An RTC is installed on HackRF One.
    * LPC4320 microcontroller: Jawbreaker had an LPC4330.
    * RF shield footprint: An optional shield may be installed over HackRF One's RF section.
    * Antenna port power: HackRF One can supply up to 50 mA at 3.0 to 3.3 V DC on the antenna port for compatibility with powered antennas and other low power amplifiers.
    * Enhanced frequency range: The RF performance of HackRF One is better than Jawbreaker, particularly at the high and low ends of the operating frequency range. HackRF One can operate at 1 MHz or even lower.

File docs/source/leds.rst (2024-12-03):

====
LEDs
====

When HackRF One is plugged in to a USB host, four LEDs should turn on: 3V3, 1V8, RF, and USB. The 3V3 LED indicates that the primary internal power supply is working properly. The 1V8 and RF LEDs indicate that firmware is running and has switched on additional internal power supplies. The USB LED indicates that the HackRF One is communicating with the host over USB.

The RX and TX LEDs indicate that a receive or transmit operation is currently in progress.

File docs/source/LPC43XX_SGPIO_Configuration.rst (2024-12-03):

================================================
LPC43xx SGPIO Configuration
================================================

The LPC43xx SGPIO peripheral is used to move samples between USB and the ADC/DAC chip (MAX5864). The SGPIO is a peripheral that has a bunch of 32-bit shift registers. These shift registers can be configured to act as a parallel interface of different widths. For HackRF, we configure the SGPIO to transfer eight bits at a time. The SGPIO interface can also accept an external clock, which we use to synchronize transfers with the sample clock.

In the current HackRF design, there is a CPLD which manages the interface between the MAX5864 and the SGPIO interface. There are four SGPIO signals that control the SGPIO data transfer:

    * Clock: Determines when a value on the SGPIO data bus is transferred.
    * Direction: Determines whether the MAX5864 DA (ADC) data is driven onto the SGPIO lines, or if the SGPIO lines drive the data bus with data for the MAX5864 DD (DAC) signals.
    * Data Valid: Indicates a sample on the SGPIO data bus is valid data.
    * Transfer Enable: Allows SGPIO to synchronize with the I/Q data stream. The MAX5864 produces/consumes two values (quadrature/complex value) per sample period -- an I value and a Q value. These two values are multiplexed on the SGPIO lines. This signal suspends data valid until the I value should be transferred.

Why not use GPDMA to transfer samples through SGPIO?
~~~~~~~~~~~~~~~~~~~~~~~~~~~~~~~~~~~~~~~~~~~~~~~~~~~~

It would be great if we could, as that would free up lots of processor time. Unfortunately, the GPDMA scheme in the LPC43xx does not seem to support peripheral-to-memory and memory-to-peripheral transfers with the SGPIO peripheral.

You might observe that the SGPIO peripheral can generate requests from SGPIO14 and SGPIO15, using an arbitrary bit pattern in the slice shift register. The pattern in the slice determines the request interval. That's a good start. However, how do you specify which SGPIO shadow registers are read/written at each request, and in which order those registers are transferred with memory? It turns out you can't. In fact, it appears that an SGPIO request doesn't cause any transfer at all, if your source or destination is "peripheral". Instead, the SGPIO request is intended to perform a memory-to-memory transfer synchronized with SGPIO. But you're on your own as far as getting data to/from the SGPIO shadow registers. I believe this is why the SGPIO camera example in the user manual describes an SGPIO interrupt doing the SGPIO shadow register transfer, and the GPDMA doing moves from one block of RAM to another.

Perhaps if we transfer only one SGPIO shadow register, using memory-to-memory? Then we don't have to worry about the order of SGPIO registers, or which ones need to be transferred. It turns out that when you switch over to memory-to-memory transfers, you lose peripheral request generation. So the GPDMA will transfer as fast as possible -- far faster than words are produced/consumed by SGPIO.

I'd really love to be wrong about all this, but all my testing has indicated there's no workable solution to using GPDMA that's any better than using SGPIO interrupts to transfer samples. If you want some sample GPDMA code to experiment with, please contact Jared (sharebrained on #hackrf in Discord or IRC).

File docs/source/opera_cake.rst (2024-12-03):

==========
Opera Cake
==========

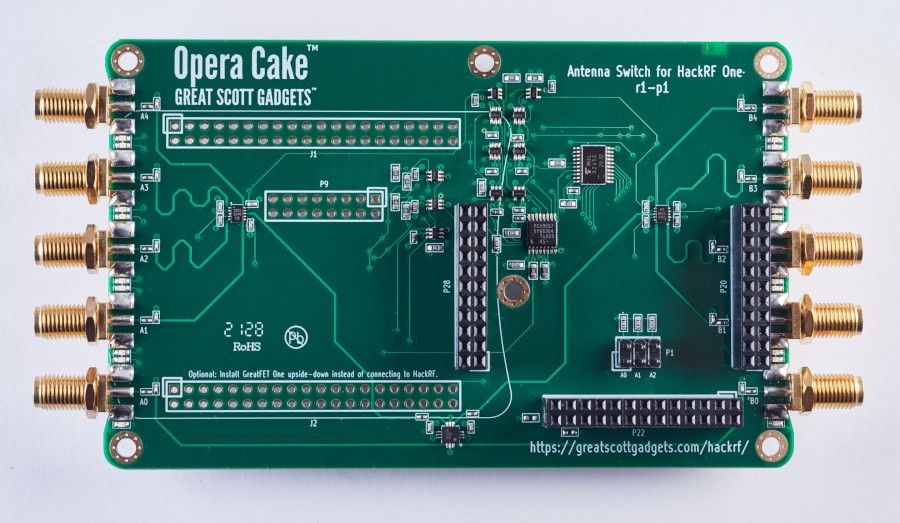
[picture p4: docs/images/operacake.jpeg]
Opera Cake


Opera Cake is an antenna switching add-on board for HackRF One. Consisting of two 1x4 switches, Opera Cake also has a cross-over switch that permits operation as a 1x8 switch. Up to eight Opera Cakes may be stacked onto a single HackRF One provided that each Opera Cake is configured with a different board address.

Opera Cake can be used as a 1x8 switch to connect your HackRF One to a variety of antennas at once, such as a long wire antenna for HF bands, a discone for VHF and UHF, a dipole for 2.4 GHz, and a dish for a satellite band. Once connected to your Opera Cake you can switch between all of your antennas in software instead of making physical hardware swaps.

When set up as a pair of 1x4 switches you could use Opera Cake as a switched filter bank. To do this, connect port A1 to B1, A2 to B2, A3 to B3, and A4 to B4 through physical SMA filters and cables of your choosing. This setup allows you to change your transmit or receive to be through the filter of your choosing without having to reconnect hardware every time you would like to use a different filter.

Opera Cake is configured with the ``hackrf_operacake`` command-line tool.

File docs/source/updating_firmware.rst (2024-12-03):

.. _updating_firmware:

================================================
Updating Firmware
================================================

HackRF devices ship with firmware on the SPI flash memory. The firmware can be updated with a USB cable and host computer.

These instructions allow you to upgrade the firmware in order to take advantage of new features or bug fixes.

Updating the SPI Flash Firmware
~~~~~~~~~~~~~~~~~~~~~~~~~~~~~~~

To update the firmware on a working HackRF One, use the hackrf_spiflash program:

.. code-block :: sh

	hackrf_spiflash -w hackrf_one_usb.bin

You can find the firmware binary (hackrf_one_usb.bin) in the firmware-bin directory of the latest `release package <https://github.com/greatscottgadgets/hackrf/releases/latest>`__ or you can compile your own from the `source <https://github.com/greatscottgadgets/hackrf/tree/master/firmware>`__. For Jawbreaker, use hackrf_jawbreaker_usb.bin. If you compile from source, the file will be called hackrf_usb.bin.

The hackrf_spiflash program is part of hackrf-tools.

When writing a firmware image to SPI flash, be sure to select firmware with a filename ending in ".bin".

After writing the firmware to SPI flash, you may need to reset the HackRF device by pressing the RESET button or by unplugging it and plugging it back in.

If you get an error that mentions HACKRF_ERROR_NOT_FOUND, it is often a permissions problem on your OS.

Only if Necessary: Recovering the SPI Flash Firmware
~~~~~~~~~~~~~~~~~~~~~~~~~~~~~~~~~~~~~~~~~~~~~~~~~~~~

If the firmware installed in SPI flash has been damaged or if you are programming a home-made HackRF for the first time, you will not be able to immediately use the hackrf_spiflash program as listed in the above procedure. Follow these steps instead:

    #. Follow the DFU Boot instructions to start the HackRF in DFU boot mode.
    #. Type ``dfu-util --device 1fc9:000c --alt 0 --download hackrf_one_usb.dfu`` to load firmware from a release package into RAM. If you have a Jawbreaker, use hackrf_jawbreaker_usb.dfu instead. Alternatively, use ``make -e BOARD=HACKRF_ONE RUN_FROM=RAM program`` to load the firmware into RAM and start it.
    #. Follow the SPI flash firmware update procedure above to write the ".bin" firmware image to SPI flash. 

Only if Necessary: DFU Boot
~~~~~~~~~~~~~~~~~~~~~~~~~~~

DFU boot mode is normally only needed if the firmware is not working properly or has never been installed.

The LPC4330 microcontroller on HackRF is capable of booting from several different code sources. By default, HackRF boots from SPI flash memory (SPIFI). It can also boot HackRF in DFU (USB) boot mode. In DFU boot mode, HackRF will enumerate over USB, wait for code to be delivered using the DFU (Device Firmware Update) standard over USB, and then execute that code from RAM. The SPIFI is normally unused and unaltered in DFU mode.

To start up HackRF One in DFU mode, hold down the DFU button while powering it on or while pressing and releasing the RESET button. Release the DFU button after the 3V3 LED illuminates. The 1V8 LED should remain off. At this point HackRF One is ready to receive firmware over USB.

To start up Jawbreaker in DFU mode, short two pins on one of the "BOOT" headers while power is first supplied. The pins that must be shorted are pins 1 and 2 of header P32 on Jawbreaker. Header P32 is labeled "P2_8" on most Jawbreakers but may be labeled "2" on prototype units. Pin 1 is labeled "VCC". Pin 2 is the center pin. After DFU boot, you should see VCCLED illuminate and note that 1V8LED does not illuminate. At this point Jawbreaker is ready to receive firmware over USB.

You should only use a firmware image with a filename ending in ".dfu" over DFU, not firmware ending in ".bin".

Obtaining DFU-Util
~~~~~~~~~~~~~~~~~~

On fresh installs of your OS, you may need obtain a copy of DFU-Util. For most Linux distributions it should be available as a package, for example on Debian/Ubuntu

.. code-block :: sh

	sudo apt-get install dfu-util

If you are using a platform without a dfu-util package, build instruction can be found `here on the dfu-util source forge build page <http://dfu-util.sourceforge.net/build.html>`__.

.. code-block :: sh

	cd ~
	sudo apt-get build-dep dfu-util
	sudo apt-get install libusb-1.0-0-dev
	git clone git://git.code.sf.net/p/dfu-util/dfu-util
	cd dfu-util
	./autogen.sh
	./configure
	make
	sudo make install

Now you will have the current version of DFU Util installed on your system.

Updating the CPLD
~~~~~~~~~~~~~~~~~

Older versions of HackRF firmware (prior to release 2021.03.1) require an additional step to program a bitstream into the CPLD.

To update the CPLD image, first update the SPI flash firmware, libhackrf, and hackrf-tools to the version you are installing. Then:

.. code-block :: sh

	hackrf_cpldjtag -x firmware/cpld/sgpio_if/default.xsvf

After a few seconds, three LEDs should start blinking. This indicates that the CPLD has been programmed successfully. Reset the HackRF device by pressing the RESET button or by unplugging it and plugging it back in.

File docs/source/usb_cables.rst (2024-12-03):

==========
USB Cables
==========

The USB cable you choose can make a big difference in what you see when using your HackRF and especially when using it around between 120 and 480 MHz where USB is doing all its work.

    #. Use a shielded USB cable. The best way to guarantee RF interference from USB is to use an unshielded cable. You can test that your cable is shielded by using a continuity tester to verify that the shield on one connector has continuity to the shield on the connector at the other end of the cable.

    #. Use a short USB cable. Trying anything larger than a 6ft cable may yield poor results. The longer the cable, the more loss you can expect and when making this post a 15ft cable was tried and the result was the HackRF would only power up half way.

    #. For best results, select a cable with a ferrite core. These cables are usually advertised to be noise reducing and are recognizable from the plastic block towards one end.

Screenshot before and after changing to a noise reducing cable (`view full size image <http://i.imgur.com/e64LASK.jpg>`__): 

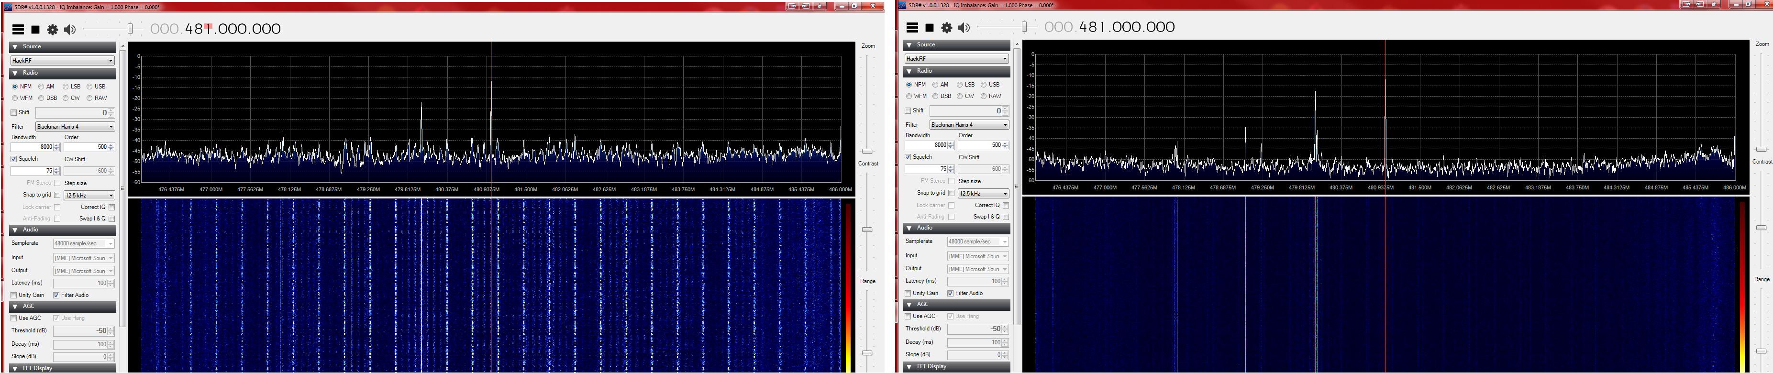
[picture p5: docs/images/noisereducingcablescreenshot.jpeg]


A shielded cable with ferrite core was used in the right-hand image.

The before and after images were both taken with the preamp on and the LNA and VGA both set to 24db.

Why isn't my HackRF One detectable after I plug it into my computer?
~~~~~~~~~~~~~~~~~~~~~~~~~~~~~~~~~~~~~~~~~~~~~~~~~~~~~~~~~~~~~~~~~~~~

If your HackRF One isn't immediately detectable it is very possible that your Micro USB cable is not meeting HackRF One's requirements. HackRF One requires quite a bit of supply current and solid USB 2.0 high speed communications to operate. It is common for HackRF One to reveal cables with deficiencies such as carrying power but not data, carrying data but not enough power, etc. Please try multiple cables to resolve this issue. More than once people have gotten their HackRF One to work after trying their fifth cable.

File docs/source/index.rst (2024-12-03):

==================================
Welcome to HackRF's documentation!
==================================

.. toctree::
   :maxdepth: 2
   :caption: User Documentation

   getting_help
   faq
   hackrf_projects_mentions

.. toctree::
   :maxdepth: 2
   :caption: HackRF One Hardware

   hackrf_one 
   hackrf_minimum_requirements
   list_of_hardware_revisions
   hardware_components 
   leds 
   hackrfs_buttons
   hackrf_connectors
   external_clock_interface
   expansion_interface
   hardware_triggering
   enclosure_options    
   usb_cables
   rf_shield_installation   

.. toctree::
   :maxdepth: 2
   :caption: Jawbreaker Hardware

   jawbreaker 

.. toctree::
   :maxdepth: 2
   :caption: Firmware

   updating_firmware
   firmware_development_setup
   LPC43XX_Debugging
   LPC43XX_SGPIO_Configuration

.. toctree::
   :maxdepth: 2
   :caption: Software

   installing_hackrf_software
   hackrf_tools
   software_support
   sampling_rate
   setting_gain
   virtual_machines

.. toctree::
   :maxdepth: 2
   :caption: Opera Cake Documentation

   opera_cake
   opera_cake_faq
   opera_cake_hardware
   opera_cake_board_addressing
   opera_cake_port_configuration
   opera_cake_modes_of_operation

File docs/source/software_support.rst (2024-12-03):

===========================================
Third-Party Software Compatible With HackRF
===========================================

Software That Has Direct Support For HackRF
~~~~~~~~~~~~~~~~~~~~~~~~~~~~~~~~~~~~~~~~~~~

* GQRX

    * `http://gqrx.dk/ <http://gqrx.dk/>`__

* GNU Radio

    * https://www.gnuradio.org/

* GNU Radio Mode-S/ADS-B

    * `https://github.com/bistromath/gr-air-modes <https://github.com/bistromath/gr-air-modes>`__

* QSpectrumAnalyzer

    * `https://github.com/xmikos/qspectrumanalyzer <https://github.com/xmikos/qspectrumanalyzer>`__

* SDR# 

    * `https://airspy.com/download/ <https://airspy.com/download/>`__
    * Windows OS only
    * Only nightly builds currently support HackRF One  

* SDR Console

    * https://www.sdr-radio.com/Console

* Spectrum Analyzer GUI for hackrf_sweep for Windows 

    * `https://github.com/pavsa/hackrf-spectrum-analyzer <https://github.com/pavsa/hackrf-spectrum-analyzer>`__

* Universal Radio Hacker (Windows/Linux) 

    * `https://github.com/jopohl/urh <https://github.com/jopohl/urh>`__

* Web-based APRS tracker 

    * `https://xakcop.com/aprs-sdr <https://xakcop.com/aprs-sdr/>`__

Software That Can Use Data From HackRF
~~~~~~~~~~~~~~~~~~~~~~~~~~~~~~~~~~~~~~
* Baudline 

    * `http://www.baudline.com/ <http://www.baudline.com/>`__ 
    * Can view/process HackRF data, e.g. hackrf_transfer

* Inspectrum 

    * `https://github.com/miek/inspectrum <https://github.com/miek/inspectrum>`__
    * Capture analysis tool with advanced features

* Matlab

    .. code-block :: sh

        fid = open('samples.bin',  'r');
        len = 1000; % 1000 samples
        y = fread(fid, 2*len, 'int8');
        y = y(1:2:end) + 1j*y(2:2:end);
        fclose(fid)

Troubleshooting Recommendations
~~~~~~~~~~~~~~~~~~~~~~~~~~~~~~~

Many of these tools require libhackrf and at times HackRF Tools. It may help you to have updated libhackrf and HackRF Tools when troubleshooting these applications. 

It is also strongly suggested, and usually required, that your HackRF Tools and HackRF firmware match.

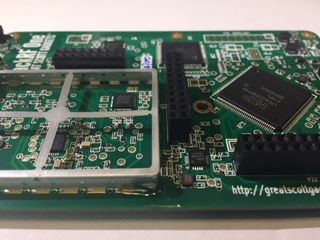
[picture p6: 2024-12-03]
docs/images/rf_shield_4.jpg

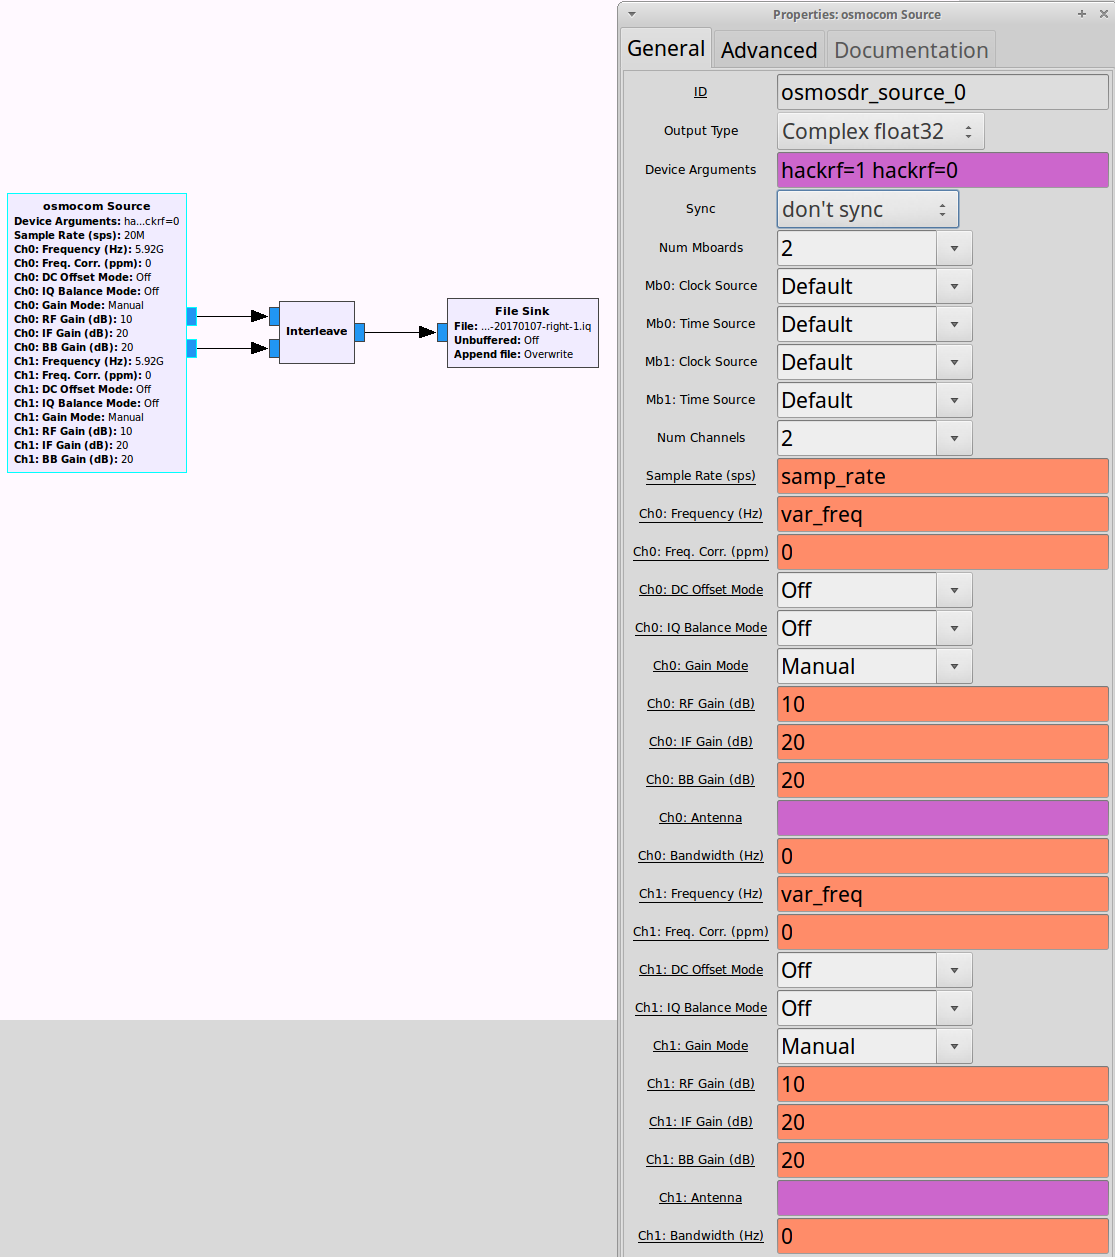
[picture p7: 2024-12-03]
docs/images/grc-hw-sync-streaming.png

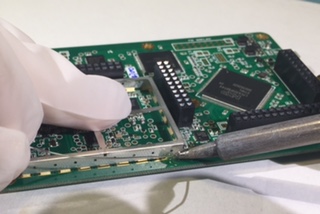
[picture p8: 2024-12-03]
docs/images/rf_shield_3.jpg

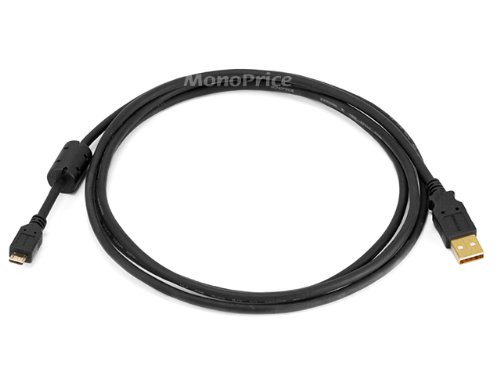
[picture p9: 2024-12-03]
docs/images/noisereducingcable.jpeg

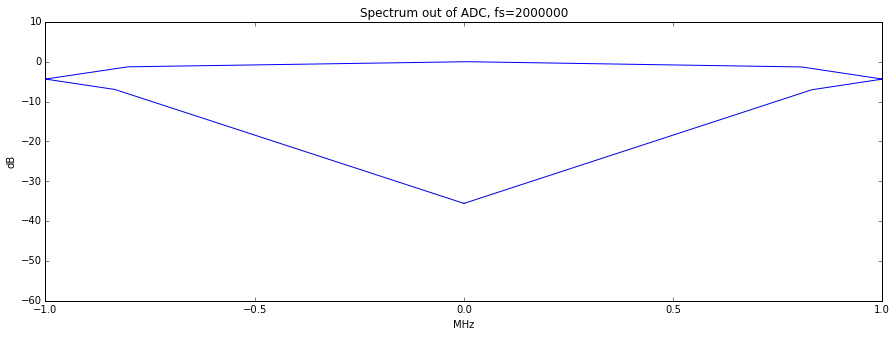
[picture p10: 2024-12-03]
docs/images/max2837-1m75bw-at-2m.png

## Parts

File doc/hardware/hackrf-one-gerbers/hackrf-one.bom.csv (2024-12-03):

DNP | Comment | Designator | Footprint | Qty | Description
 | 8p2 | C14 | hackrf:GSG-0402 | 1 | CAP CER 8.2PF 50V NP0 0402
 | 3.3nF | C114 | hackrf:GSG-0402 | 1 | CAP CER 3300PF 50V 10% X7R 0402
DNP | 47pF | C156 | hackrf:GSG-0402 | 1 | CAP CER 47PF 50V 5% NP0 0402
 | 1pF | C173 | hackrf:GSG-0402 | 1 | CAP CER 1PF 50V 5% NP0 0402
 | 33pF | C1,C3,C5,C7,C10,C16,C22,C24,C29,C30,C33,C34,C35,C36,C37,C38,C39,C40,C45,C47,C54,C55,C56,C57,C60,C63,C65,C66,C67,C115,C125 | hackrf:GSG-0402 | 31 | CAP CER 33PF 50V 5% NP0 0402
 | 3pF | C104,C111 | hackrf:GSG-0402 | 2 | CAP CER 3PF 50V NP0 0402
 | 10uF | C105,C126,C127,C143,C145,C146 | hackrf:GSG-0805 | 6 | CAP CER 10UF 10V 10% X5R 0805
 | 18pF | C118,C157,C158,C164 | hackrf:GSG-0402 | 4 | CAP CER 18PF 50V 5% NP0 0402
 | 330pF | C12,C13 | hackrf:GSG-0402 | 2 | CAP CER 330PF 50V 10% X7R 0402
 | 180pF | C15,C112 | hackrf:GSG-0402 | 2 | CAP CER 180PF 50V 5% NP0 0402
 | 1.8pF | C169,C170 | hackrf:GSG-0402 | 2 | CAP CER 1.8PF 25V C0G/NP0 0402
 | 10nF | C2,C4,C6,C87,C88,C89,C92,C93,C162,C163 | hackrf:GSG-0402 | 10 | CAP CER 10000PF 16V 10% X7R 0402
 | 47pF | C26,C27,C116 | hackrf:GSG-0402 | 3 | CAP CER 47PF 50V 5% NP0 0402
 | 100pF | C41,C42,C52,C70,C90,C160 | hackrf:GSG-0402 | 6 | CAP CER 100PF 50V 5% NP0 0402
 | 1uF | C53,C106,C161,C171 | hackrf:GSG-0402 | 4 | CAP CER 1UF 10V 10% X5R 0402
DNP | 100pF | C68,C69,C159,C165,C168 | hackrf:GSG-0402 | 5 | CAP CER 100PF 50V 5% NP0 0402
 | 2.2uF | C72,C74,C76,C78,C80,C82,C124 | hackrf:GSG-0402 | 7 | CAP CER 2.2UF 10V 20% X5R 0402
 | 22pF | C8,C21,C32,C43,C48,C51,C84,C85,C86,C94,C99,C102 | hackrf:GSG-0402 | 12 | CAP CER 22PF 50V 5% NP0 0402
 | 100nF | C9,C17,C18,C20,C23,C25,C28,C31,C44,C46,C49,C50,C58,C59,C61,C62,C64,C71,C73,C75,C77,C79,C81,C83,C91,C113,C117,C119,C120,C121,C122,C123,C128,C129,C130,C131,C132,C133,C134,C135,C136,C137,C138,C139,C140,C141,C142,C144,C147,C148,C149,C150,C151,C152,C153,C154,C166,C167,C172 | hackrf:GSG-0402 | 59 | CAP CER 0.1UF 10V 10% X5R 0402
DNP | 22pF | C95,C96,C101,C103,C107,C108,C109,C110 | hackrf:GSG-0402 | 8 | CAP CER 22PF 50V 5% NP0 0402
 | 330nF | C97,C98,C100 | hackrf:GSG-0402 | 3 | CAP CER 0.33UF 10V 10% X5R 0402
 | VAALED | D2 | gsg-modules:LTST-S220 | 1 | LED SUPR RED CLR RT ANG 0805
 | USBLED | D4 | gsg-modules:LTST-S220 | 1 | LED GREEN CLEAR RT ANG 0805
 | RXLED | D5 | gsg-modules:LTST-S220 | 1 | LED YELLOW CLEAR RT ANG 0805
 | TXLED | D6 | gsg-modules:LTST-S220 | 1 | LED SUPR RED CLR RT ANG 0805
 | VCCLED | D7 | gsg-modules:LTST-S220 | 1 | LED GREEN CLEAR RT ANG 0805
 | 1V8LED | D8 | gsg-modules:LTST-S220 | 1 | LED YELLOW CLEAR RT ANG 0805
 | D_Schottky | D10 | gsg-modules:DSN1006-2 | 1 | DIODE SCHOTTKY 40V 1A DSN1006-2
 | BAS70-04 | D1,D3 | Package_TO_SOT_SMD:SOT-23 | 2
 | CLA4611-085LF | D11,D12,D13 | gsg-modules:SkyworksLimiterDiode | 3 | Limiter Diode
 | FILTER | FB2 | hackrf:GSG-0805 | 1 | FERRITE CHIP 220 OHM 2000MA 0805
DNP | RF-SHIELD-FRAME | J2 | hackrf:GSG-SHIELD-BMI-S-230 | 1 | BOARD SHIELD 2INX1.5IN FRAME
DNP | RF-SHIELD-COVER | J3 | hackrf:GSG-NULL-MODULE | 1 | BOARD SHIELD 2INX1.5IN COVER
DNP | GND_CLIP | J10 | hackrf:GSG-TEST-POINT-S1751-46R | 1 | PC TEST POINT TIN SMD
 | Connector_USB_C_Receptacle_USB2.0 | J11 | gsg-modules:USB-C_SMD-TYPE-C-31-M-12 | 1
DNP | MOUNTING_HOLE | J4,J5,J6,J7,J8,J9 | hackrf:GSG-HOLE126MIL-COPPER | 6
 | 6.2nH | L7 | hackrf:GSG-0402 | 1 | INDUCTOR HIFREQ 6.2+/-0.3NH 0402
 | 0.56uH | L13 | hackrf:GSG-0603 | 1 | INDUCTOR 560nH ±5% 70mA 8.1Ω 0603
 | 3.3uH | L14 | hackrf:GSG-0603 | 1 | INDUCTR 3.3UH 290MA 20% 0603 SMD
 | ECMF02-4CMX8 | L15 | gsg-modules:QFN-8_L2.5-W1.2-P0.50-BL | 1
DNP | DNP | L1,L4,L6,L8,L9 | hackrf:GSG-0402 | 5
 | 4u7 | L10,L11 | hackrf:GSG-NRG4026 | 2 | INDUCTOR 4.7UH 1.6A 20% SMD
 | 10uH | L2,L3,L5,L12 | hackrf:GSG-0603 | 4 | INDUCTR 10UH 220MA 20% 0603 SMD
DNP | 1V8 | P1 | hackrf:GSG-HEADER-1x2 | 1
DNP | CLKOUT | P2 | gsg-modules:SMA-73251-2120 | 1 | CONN SMA JACK 50 OHM EDGE MNT W/JAM NUT & LOCK WASHER
 | ANTENNA | P4 | gsg-modules:SMA-73251-2120 | 1 | CONN SMA JACK 50 OHM EDGE MNT W/JAM NUT & LOCK WASHER
DNP | LEDS | P5 | hackrf:GSG-HEADER-2x3 | 1
DNP | GPO4 | P6 | hackrf:GSG-TESTPOINT-50MIL | 1
DNP | GPO2 | P7 | hackrf:GSG-TESTPOINT-50MIL | 1
DNP | VCC | P8 | hackrf:GSG-HEADER-1x2 | 1
 | BASEBAND | P9 | hackrf:GSG-HEADER-2x8 | 1 | CONN HEADER FMAL 16PS.1" DL GOLD
DNP | GPO1 | P13 | hackrf:GSG-TESTPOINT-50MIL | 1
DNP | XCVR_CLKOUT | P14 | hackrf:GSG-TESTPOINT-50MIL | 1
DNP | INTR | P15 | hackrf:GSG-TESTPOINT-50MIL | 1
DNP | CLKIN | P16 | gsg-modules:SMA-73251-2120 | 1 | CONN SMA JACK 50 OHM EDGE MNT W/JAM NUT & LOCK WASHER
DNP | GPO6 | P17 | hackrf:GSG-TESTPOINT-50MIL | 1
DNP | OEB | P18 | hackrf:GSG-TESTPOINT-50MIL | 1
DNP | GPO3 | P19 | hackrf:GSG-TESTPOINT-50MIL | 1
 | GPIO | P20 | hackrf:GSG-HEADER-2x11 | 1 | CONN HEADER FMAL 22PS.1" DL GOLD
DNP | REF_IN | P21 | hackrf:GSG-TESTPOINT-50MIL | 1
 | I2S | P22 | hackrf:GSG-HEADER-2x13 | 1 | CONN HEADER FMAL 26PS.1" DL GOLD
DNP | DBGEN | P23 | hackrf:GSG-TESTPOINT-50MIL | 1
DNP | TRST | P24 | hackrf:GSG-TESTPOINT-50MIL | 1
DNP | LPC_ISP | P25 | hackrf:GSG-HEADER-1x6 | 1
DNP | LPC_JTAG | P26 | hackrf:GSG-50MIL-HEADER-2x5-TH | 1 | CONN HEADER .050" 10PS DL PCB AU
DNP | MIXER_SDATA | P27 | hackrf:GSG-TESTPOINT-50MIL | 1
 | SD | P28 | hackrf:GSG-HEADER-2x11 | 1 | CONN HEADER FMAL 22PS.1" DL GOLD
DNP | CPLD_JTAG | P29 | hackrf:GSG-HEADER-1x2 | 1
DNP | BANK2_AUX | P30 | hackrf:GSG-HEADER-2x10 | 1
DNP | MIXER_SCLK | P31 | hackrf:GSG-TESTPOINT-50MIL | 1
DNP | MIXER_ENX | P32 | hackrf:GSG-TESTPOINT-50MIL | 1
DNP | MIXER_RESETX | P33 | hackrf:GSG-TESTPOINT-50MIL | 1
DNP | MIX_BYPASS | P34 | hackrf:GSG-TESTPOINT-50MIL | 1
DNP | !MIX_BYPASS | P35 | hackrf:GSG-TESTPOINT-50MIL | 1
DNP | VAA | P36 | hackrf:GSG-HEADER-1x2 | 1
DNP | SCL | P37 | hackrf:GSG-TESTPOINT-50MIL | 1
DNP | SDA | P38 | hackrf:GSG-TESTPOINT-50MIL | 1
DNP | SSP1_SCK | P39 | hackrf:GSG-TESTPOINT-50MIL | 1
DNP | SSP1_MOSI | P40 | hackrf:GSG-TESTPOINT-50MIL | 1
DNP | SSP1_MISO | P41 | hackrf:GSG-TESTPOINT-50MIL | 1
DNP | RX | P43 | hackrf:GSG-TESTPOINT-50MIL | 1
DNP | HP | P44 | hackrf:GSG-TESTPOINT-50MIL | 1
DNP | LP | P45 | hackrf:GSG-TESTPOINT-50MIL | 1
DNP | TX_MIX_BP | P46 | hackrf:GSG-TESTPOINT-50MIL | 1
DNP | RX_MIX_BP | P47 | hackrf:GSG-TESTPOINT-50MIL | 1
DNP | TX_AMP | P48 | hackrf:GSG-TESTPOINT-50MIL | 1
DNP | RX_AMP | P49 | hackrf:GSG-TESTPOINT-50MIL | 1
DNP | AMP_BYPASS | P50 | hackrf:GSG-TESTPOINT-50MIL | 1
DNP | !TX_AMP_PWR | P51 | hackrf:GSG-TESTPOINT-50MIL | 1
DNP | !RX_AMP_PWR | P52 | hackrf:GSG-TESTPOINT-50MIL | 1
DNP | CS_XCVR | P53 | hackrf:GSG-TESTPOINT-50MIL | 1
DNP | CS_AD | P54 | hackrf:GSG-TESTPOINT-50MIL | 1
DNP | TXENABLE | P55 | hackrf:GSG-TESTPOINT-50MIL | 1
DNP | RXENABLE | P56 | hackrf:GSG-TESTPOINT-50MIL | 1
DNP | XTAL2 | P57 | hackrf:GSG-TESTPOINT-50MIL | 1
DNP | GCK1 | P58 | hackrf:GSG-TESTPOINT-50MIL | 1
DNP | GCK2 | P59 | hackrf:GSG-TESTPOINT-50MIL | 1
DNP | SGPIO_CLK | P60 | hackrf:GSG-TESTPOINT-50MIL | 1
DNP | DA0 | P61 | hackrf:GSG-TESTPOINT-50MIL | 1
DNP | DA7 | P62 | hackrf:GSG-TESTPOINT-50MIL | 1
DNP | DD0 | P63 | hackrf:GSG-TESTPOINT-50MIL | 1
DNP | DD9 | P64 | hackrf:GSG-TESTPOINT-50MIL | 1
DNP | DA4 | P65 | hackrf:GSG-TESTPOINT-50MIL | 1
DNP | DD5 | P66 | hackrf:GSG-TESTPOINT-50MIL | 1
DNP | RSSI | P67 | hackrf:GSG-TESTPOINT-50MIL | 1
DNP | SPIFI_CS | P68 | hackrf:GSG-TESTPOINT-50MIL | 1
DNP | VREGMODE | P69 | hackrf:GSG-TESTPOINT-50MIL | 1
DNP | EN_1V8 | P70 | hackrf:GSG-TESTPOINT-50MIL | 1
DNP | P1_2 | P73 | hackrf:GSG-TESTPOINT-50MIL | 1
DNP | P1_1 | P74 | hackrf:GSG-TESTPOINT-50MIL | 1
DNP | SHIELD | P80 | hackrf:GSG-HEADER-NOMARK-1x2 | 1
DNP | SPIFI_SIO2 | P81 | hackrf:GSG-TESTPOINT-50MIL | 1
DNP | SPIFI_SIO3 | P82 | hackrf:GSG-TESTPOINT-50MIL | 1
DNP | GND | P3,P83,P84,P85,P86,P87,P88,P89,P90,P91,P92 | -- mixed values -- | 11
DNP | GP_CLKIN | P72,P75,P76,P77,P78,P79 | hackrf:GSG-TESTPOINT-50MIL | 6
 | AO3407A | Q3,Q4,Q5 | gsg-modules:SOT23GDS | 3 | MOSFET P-CH -30V -4.3A SOT23
 | 22k | R3 | hackrf:GSG-0402 | 1 | RES 22K OHM 1/10W 5% 0402 SMD
 | 51k | R4 | hackrf:GSG-0402 | 1 | RES TF 51K OHM 1% 0.0625W 0402
 | 100k | R12 | hackrf:GSG-0402 | 1 | RES 15.4K OHM 1% 1/16W 0402
 | 220k | R35 | hackrf:GSG-0402 | 1 | RES TF 1/16W 330K OHM 1% 0402
 | 6.8k | R45 | hackrf:GSG-0402 | 1 | RES 15.4K OHM 1% 1/16W 0402
 | 330k | R47 | hackrf:GSG-0402 | 1 | RES TF 1/16W 330K OHM 1% 0402
 | 715k | R56 | hackrf:GSG-0402 | 1 | RES TF 1/16W 715K OHM 1% 0402
 | 12k | R69 | hackrf:GSG-0402 | 1 | RES 12.0K OHM 1/16W 1% 0402 SMD
 | 470 | R1,R2,R72,R75 | hackrf:GSG-0402 | 4 | RES TF 1/16W 470 OHM 5% 0402
 | 4k7 | R14,R15,R16,R17 | hackrf:GSG-0402 | 4 | RES 4.7K OHM 1/16W 1% 0402
 | 1k8 | R18,R27,R28,R74 | hackrf:GSG-0402 | 4 | RES TF 1.8K OHM 5% 1/16W 0402
 | 39 | R19,R30,R31,R32,R33,R34,R77,R78,R79,R80,R81,R86,R87,R88,R89,R90,R91,R94,R96,R98,R99,R100 | hackrf:GSG-0402 | 22 | RES 39 OHM 1/16W 5% 0402 SMD
 | 0 | R20,R21,R22,R23,R57,R58,R62 | hackrf:GSG-0402 | 7 | RES 0.0 OHM 1/16W 0402 SMD
 | 5k1 | R24,R29 | hackrf:GSG-0402 | 2 | Resistor
 | 475 | R25,R26 | hackrf:GSG-0402 | 2 | RES TF 1/16W 470 OHM 5% 0402
 | 1.5k | R42,R43,R44 | hackrf:GSG-0402 | 3 | RES 1.5K OHM 1/10W 5% 0402 SMD
 | 162k | R46,R55 | hackrf:GSG-0402 | 2 | RES TF 1/16W 162K OHM 1% 0402
 | 10k | R5,R6,R7,R11,R36,R37,R39,R40,R41,R48,R49,R51,R52,R54,R59,R63,R64,R65,R66,R67,R68,R85,R93,R104,R105 | hackrf:GSG-0402 | 25 | RES 10K OHM 1/16W 5% 0402 SMD
 | 1k | R8,R9,R10,R13,R38,R73,R76 | hackrf:GSG-0402 | 7 | -- mixed values --
 | DFU | SW1 | hackrf:GSG-SWITCH-FSMRA | 1 | SWITCH TACTILE SPST-NO 0.05A 12V
 | RESET | SW2 | hackrf:GSG-SWITCH-FSMRA | 1 | SWITCH TACTILE SPST-NO 0.05A 12V
 | MIX_IN_BALUN | T1 | hackrf:GSG-B0310J50100AHF | 1 | Ultra Low Profile 0805 Balun 50 to 100 ohm Balanced
 | MIX_OUT_BALUN | T2 | hackrf:GSG-B0310J50100AHF | 1 | Ultra Low Profile 0805 Balun 50 to 100 ohm Balanced
 | RX_BALUN | T3 | hackrf:GSG-2500BL14M100 | 1 | BALUN CERAMIC CHIP WIMAX 2.5GHZ
Alternative part: Murata LDB182G4510G-120 | TX_BALUN | T4 | hackrf:GSG-2500BL14M100 | 1 | BALUN CERAMIC CHIP WIMAX 2.5GHZ
 | RX_LOWPASS_FILTER | U3 | hackrf:GSG-LP0603 | 1 | FILTER LOW PASS 1880MHZ 0603 SMD
 | RFFC5072 | U4 | hackrf:GSG-QFN32 | 1 | WIDEBAND SYNTHESIZER/VCO WITH INTEGRATED 6GHz MIXER
 | RX_HIGHPASS_FILTER | U8 | hackrf:GSG-HP-DEA | 1 | FILTER HIGHPASS WLAN&BLUETOOTH
 | MAX2837 | U17 | hackrf:GSG-QFN48-6 | 1 | IC TXRX 2.3GHZ-2.7GHZ 48TQFN
 | MAX5864 | U18 | hackrf:GSG-QFN48-7 | 1 | IC ANLG FRONT END 22MSPS 48-TQFN
 | SI5351C | U19 | hackrf:GSG-QFN20-4 | 1 | IC CLK GENERATOR 160MHZ 20QFN
 | W25Q80 | U20 | hackrf:GSG-SOIC8-208 | 1 | IC FLASH 8MBIT 8SOIC
 | TPS62410 | U21 | hackrf:GSG-S-PVSON-N10 | 1 | IC BUCK SYNC DUAL ADJ 0.8A 10SON
 | LPC4320FBD144 | U23 | hackrf:GSG-LQFP144 | 1 | IC MCU 32BIT 144LQFP
 | GSG-XC2C64A-7VQG100C | U24 | hackrf:GSG-VQ100 | 1 | IC CR-II CPLD 64MCELL 100-VQFP
 | SKY13453 | U1,U2,U5,U6,U7,U10,U11 | gsg-modules:SKY13453-385LF | 7
 | TRF37B73 | U13,U25 | Package_SON:WSON-8-1EP_2x2mm_P0.5mm_EP0.9x1.6mm | 2
 | SKY13317 | U9,U12,U14 | hackrf:GSG-SKY13317-373LF | 3 | 20 MHz-6.0 GHz pHEMT GaAs SP3T Switch
 | GSG-XTAL4PIN | X1 | hackrf:GSG-XTAL3.2x2.5mm | 1 | CRYSTAL 25.0000MHZ 10PF SMD
 | MCU_XTAL | X2 | hackrf:GSG-XTAL3.2x2.5mm | 1 | CRYSTAL 12.000 MHZ 12PF SMD
 | RTC_XTAL | X3 | hackrf:GSG-XTAL-AB26TRQ | 1 | CRYSTAL 32.768KHZ 12.5PF SMD

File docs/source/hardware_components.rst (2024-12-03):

================================================
Hardware Components
================================================

Major parts used in HackRF One:

* `MAX2837 2.3 to 2.7 GHz transceiver <https://www.analog.com/en/products/max2837.html>`__
    * `Datasheet <https://www.analog.com/media/en/technical-documentation/data-sheets/max2837.pdf>`__
* `MAX2839 2.3 to 2.7 GHz transceiver <https://www.analog.com/en/products/max2839.html>`__
    * `Datasheet <https://www.analog.com/media/en/technical-documentation/data-sheets/max2839.pdf>`__
    * substitution for MAX2837.
* `MAX5864 ADC/DAC <https://www.analog.com/en/products/max5864.html>`__
    * `Datasheet <https://www.analog.com/media/en/technical-documentation/data-sheets/MAX5864.pdf>`__
* `Si5351 clock generator <http://www.silabs.com/products/clocksoscillators/clock-generator/Pages/lvcmos-clocks-5-outputs.aspx>`__
    * `AN619: Manually Generating an Si5351 Register Map <http://www.silabs.com/Support%20Documents/TechnicalDocs/AN619.pdf>`__
    * `Datasheet <http://www.silabs.com/Support%20Documents/TechnicalDocs/Si5351.pdf>`__ - see AN619 for the complete register map.
    * `Other Documentation <http://www.silabs.com/products/clocksoscillators/clock-generators-and-buffers/Pages/clock+vcxo.aspx>`__ - includes application notes, user guides, and white papers.
* CoolRunner-II CPLD
* `LPC43xx ARM Cortex-M4 microcontroller <http://www.nxp.com/products/microcontrollers-and-processors/arm-processors/lpc-arm-cortex-m-mcus/lpc-dual-core-cortex-m0-m4f/lpc4300:MC_1403790133078>`__
    * `User Manual <http://www.nxp.com/documents/user_manual/UM10503.pdf>`__
    * `Datasheet <http://www.nxp.com/documents/data_sheet/LPC4350_30_20_10.pdf>`__
    * `Other Documentation (LPC4330FBD144) <http://www.nxp.com/products/microcontrollers/cortex_m4/lpc4300/LPC4330FBD144.html#documentation>`__ - includes errata and application notes.
    * `ARM-standard JTAG/SWD connector pinout <http://www.keil.com/support/man/docs/ulink2/ulink2_hw_connectors.htm>`__
    * `BSDL file for the LPC43xx (For boundary scan) <http://www.lpcware.com/system/files/LPC18xx_43xx%20BSDL%20files%2020121127_0.zip>`__
* `RFFC5072 mixer/synthesizer <http://www.rfmd.com/store/rffc5072-1.html>`__
    * `Datasheet <http://www.rfmd.com/CS/Documents/RFFC5071_2DS.pdf>`__
    * `Other Documentation <http://www.rfmd.com/store/rffc5072-1.html>`__ ; click "Technical Documents" - includes programming guides and application notes.
* `W25Q80BV 8M-bit Flash <https://www.winbond.com/resource-files/w25q80bv%20revk%2020151203.pdf>`__

Block Diagrams
~~~~~~~~~~~~~~

HackRF One r1-r8 Block Diagram
^^^^^^^^^^^^^^^^^^^^^^^^^^^^^^

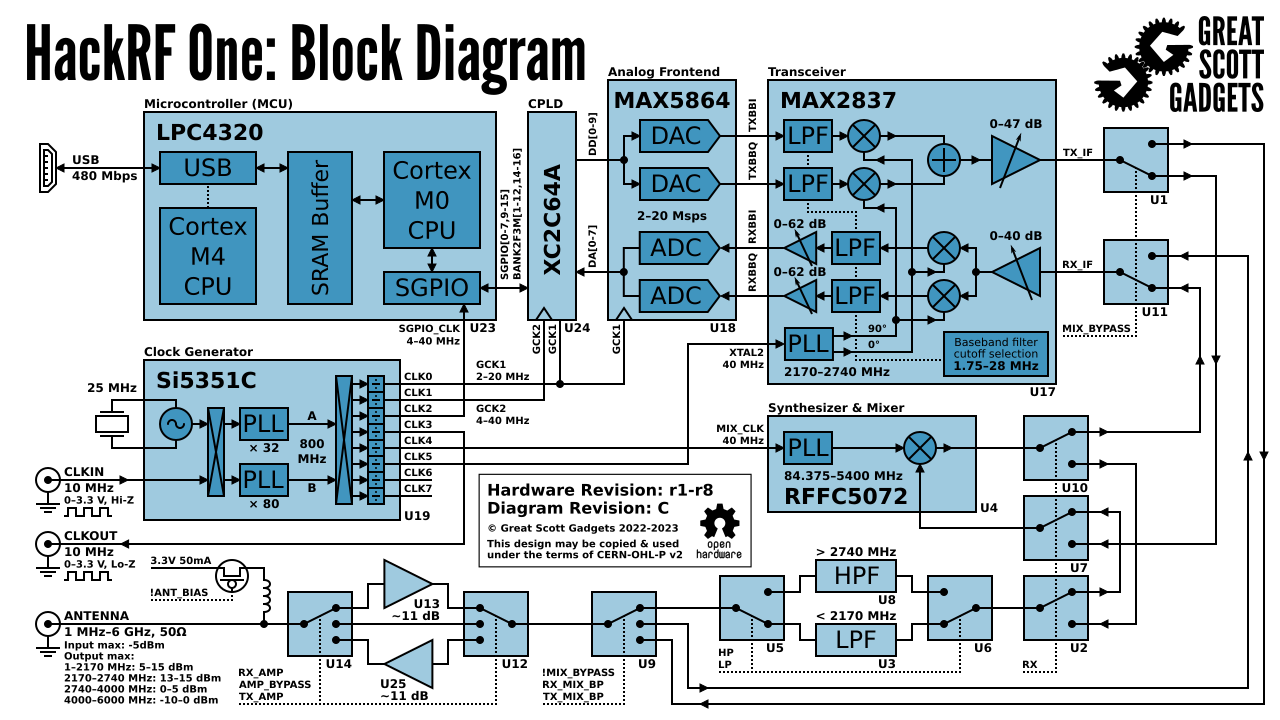
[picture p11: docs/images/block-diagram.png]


|

HackRF One r9 Block Diagram
^^^^^^^^^^^^^^^^^^^^^^^^^^^

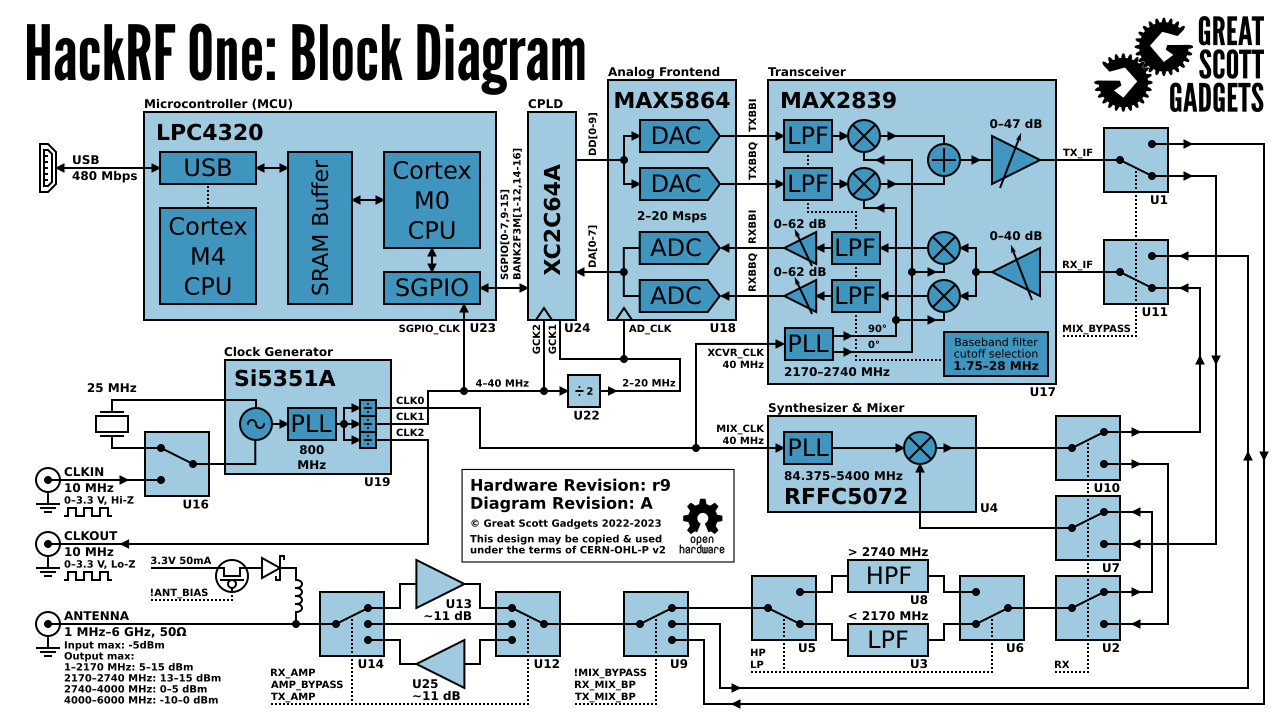
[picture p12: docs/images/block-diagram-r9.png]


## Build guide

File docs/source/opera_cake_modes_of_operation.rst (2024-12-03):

==================
Modes of Operation
==================

Opera Cake supports three modes of operation: ``manual``, ``frequency``, and ``time``. The operating mode can be set with the ``--mode`` or ``-m`` option, and the active operating mode is displayed with the ``--list`` or ``-l`` option.

Manual Mode
~~~~~~~~~~~

The default mode of operation is ``manual``. In manual mode, fixed port connections are configured with the ``-a`` and ``-b`` options as in the :ref:`port configuration examples <portconfiguration>`. If the operating mode has been changed, it can be changed back to manual mode with:

.. code-block:: sh

	hackrf_operacake -m manual

Frequency Mode
~~~~~~~~~~~~~~

In frequency mode, the A0 port connection switches automatically whenever the HackRF is tuned to a different frequency. This is useful when antennas for different frequency bands are connected to various ports.

The bands are specified in priority order. The final band specified will be used for frequencies not covered by the other bands specified.

To assign frequency bands to ports you must use the ``-f <port:min:max>`` option for each band, with the minimum and maximum frequencies specified in MHz. For example, to use port A1 for 100 MHz to 600 MHz, A3 for 600 MHz to 1200 MHz, and B2 for 0 MHz to 4 GHz:

.. code-block:: sh

	hackrf_operacake -m frequency -f A1:100:600 -f A3:600:1200 -f B2:0:4000

If tuning to precisely 600 MHz, A1 will be used as it is listed first. Tuning to any frequency over 4 GHz will use B2 as it is the last listed and therefore the default port.

Only the A0 port connection is specified in frequency mode. Whenever the A0 connection is switched, the B0 connection is also switched to the secondary port mirroring A0's secondary port. For example, when A0 switches to B2, B0 is switched to A2.

Once configured, an Opera Cake will remain in frequency mode until the mode is reconfigured or until the HackRF One is reset. You can pre-configure the Opera Cake in frequency mode, and the automatic switching will continue to work while using other software.

Although multiple Opera Cakes on a single HackRF One may be set to frequency mode at the same time, they share a single switching plan. This can be useful, for example, for a filter bank consisting of eight filters.

Time Mode
~~~~~~~~~

In time mode, the A0 port connection switches automatically over time, counted in units of the sample period. This is useful for experimentation with pseudo-doppler direction finding.

To cycle through four ports, one port every 1000 samples:

.. code-block:: none

	hackrf_operacake -m time -t A1:1000 -t A2:1000 -t A3:1000 -t A4:1000

When the duration on multiple ports is the same, the ``-w`` option can be used to set the default dwell time:

.. code-block:: none

	hackrf_operacake --mode time -w 1000 -t A1 -t A2 -t A3 -t A4

Only the A0 port connection is specified in time mode. Whenever the A0 connection is switched, the B0 connection is switched to the secondary port mirroring A0's secondary port. For example, when A0 switches to B2, B0 is switched to A2.

Once configured, an Opera Cake will remain in time mode until the mode is reconfigured or until the HackRF One is reset. You can pre-configure the Opera Cake in time mode, and the automatic switching will continue to work while using other software.

Although multiple Opera Cakes on a single HackRF One may be set to time mode at the same time, they share a single switching plan.

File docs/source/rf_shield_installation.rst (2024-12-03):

===============================================
RF Shield Installation Instructions
===============================================

Official Great Scott Gadgets HackRF Ones do not come from the factory with an RF shield installed around the radio section of the PCB. They do, however, have pads in place so that one may be installed if a user has a reason and an inclination to do so. The reason that they do not come preinstalled is that early testing revealed that the RF shield did little to improve the performance of the HackRF One. The recommended RF shield is the BMI-S-230-F-R (frame) with the BMI-S-230-C (shield). A two part RF shield is recommended because the shield section can be removed to allow access to the RF section of the HackRF One. This can be important if it becomes necessary to probe any part of the RF section, or to replace any parts of the RF section. However, even with a two part RF shield, it can be difficult to access the RF section of the HackRF One in certain situations. The following steps are a basic set of instructions for installing a RF shield on a HackRF One.

**CAUTION: Soldering a RF shield onto a HackRF One comes with a certain amount of risk. Beyond the inherent risks of soldering itself, this process may damage the HackRF One and no warranty is available to cover damage incurred from this process. If you do choose to install a RF shield on your HackRF One please proceed with caution.**

1. Remove the HackRF One from the injection molded plastic case. 

  **BE WARNED: Opening the plastic case of your HackRF One will most likely destroy the tabs that hold it together.**  

  Instructions for removing a HackRF One from its case can be found :ref:`here <open_your_hackrf_one>`.

2. Prepare the HackRF One PCB for soldering on the shield frame, by adding flux to the RF shield pads around the radio section on the PCB.

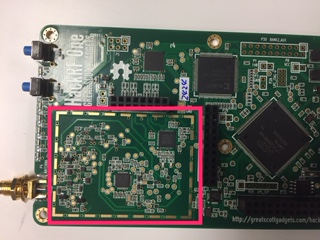
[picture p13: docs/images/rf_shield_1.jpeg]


3. Place the RF shield frame on the HackRF One, aligning it so that it makes contact with all of the pads around the RF section of the board.

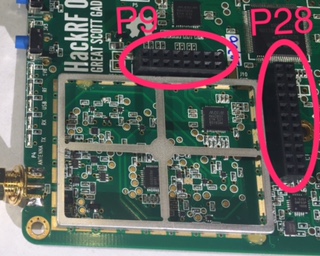
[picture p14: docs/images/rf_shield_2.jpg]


4. Solder the shield to one pad to anchor it to the H1. Visually inspect the frame to assure that it is still aligned properly.

+---------------------------------------+---------------------------------------+
| 
+---------------------------------------+---------------------------------------+

5. Connect the frame to another pad on the opposite side from the first connection. Again, check that the frame is still aligned properly.

+---------------------------------------+---------------------------------------+
| 
+---------------------------------------+---------------------------------------+

6. Connect at least one more pad, and then remove the pick and place bridge from the frame. *Removing the pick and place bridge is optional, but it is recommended.*

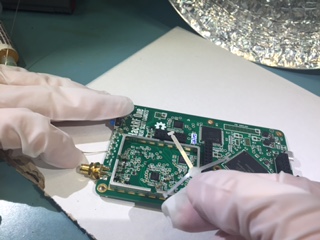
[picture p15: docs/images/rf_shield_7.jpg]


7. Continue soldering the rest of the pads to the frame.

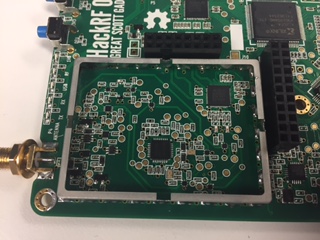
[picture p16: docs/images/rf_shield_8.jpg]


8. Clean the flux and soldering residue with the appropriate solvent for the type of flux used. Be sure to let the HackRF One dry completely before plugging it in to a power source.

9. Place the RF shield onto the frame and snap it into place.

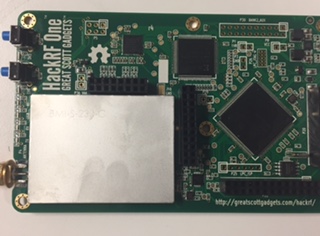
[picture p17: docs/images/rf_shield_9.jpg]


10. If desired, put the HackRF One back into the plastic case, if it is still able to click together.

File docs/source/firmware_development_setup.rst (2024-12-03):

================================================
Firmware Development Setup
================================================

Firmware build instructions are included in the repository under firmware/README:

`https://github.com/greatscottgadgets/hackrf/blob/master/firmware/README <https://github.com/greatscottgadgets/hackrf/blob/master/firmware/README>`__

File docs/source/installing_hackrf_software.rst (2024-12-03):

.. _operating_system_tips:

==========================
Installing HackRF Software
==========================

HackRF software includes HackRF Tools and libhackrf. HackRF Tools are the commandline utilities that let you interact with your HackRF. libhackrf is a low level library that enables software on your computer to operate with HackRF. 

Install Using Package Managers
~~~~~~~~~~~~~~~~~~~~~~~~~~~~~~

Unless developing or testing new features for HackRF, we highly recommend that most users use build systems or package managers provided for their operating system. **Our suggested operating system for use with HackRF is Ubuntu**.

FreeBSD
+++++++

You can use the binary package: ``# pkg install hackrf``

You can also build and install from ports:

.. code-block :: sh

	# cd /usr/ports/comms/hackrf
	# make install

Linux: Arch
+++++++++++

.. code-block :: sh

	pacman -S hackrf

Linux: Fedora / Red Hat
+++++++++++++++++++++++

``sudo dnf install hackrf -y``

Linux: Gentoo
+++++++++++++

.. code-block :: sh

	emerge -a net-wireless/hackrf-tools

Linux: Ubuntu / Debian
++++++++++++++++++++++

``sudo apt-get install hackrf``

OS X (10.5+): Homebrew
++++++++++++++++++++++

``brew install hackrf``

OS X (10.5+): MacPorts
++++++++++++++++++++++

``sudo port install hackrf``

Windows: Binaries
+++++++++++++++++

Binaries are provided as part of the PothosSDR project, they can be downloaded `here <http://downloads.myriadrf.org/builds/PothosSDR/?C=M;O=D>`__.

-----------

Installing From Source
~~~~~~~~~~~~~~~~~~~~~~

Linux / OS X / \*BSD: Building HackRF Software From Source
++++++++++++++++++++++++++++++++++++++++++++++++++++++++++

Acquire the source for the HackRF tools from either a `release archive <https://github.com/greatscottgadgets/hackrf/releases>`__ or git: ``git clone https://github.com/greatscottgadgets/hackrf.git``

Once you have the source downloaded, the host tools can be built as follows:

.. code-block :: sh

	cd hackrf/host
	mkdir build
	cd build
	cmake ..
	make
	sudo make install
	sudo ldconfig

If you have HackRF hardware, you may need to :ref:`update the firmware <updating_firmware>` to match the host tools versions.

Windows: Prerequisites for Cygwin, MinGW, or Visual Studio
++++++++++++++++++++++++++++++++++++++++++++++++++++++++++

    * cmake-2.8.12.1 or later from http://www.cmake.org/cmake/resources/software.html
    * libusbx-1.0.18 or later from http://sourceforge.net/projects/libusbx/files/latest/download?source=files
    * fftw-3.3.5 or later from http://www.fftw.org/install/windows.html
    * Install Windows driver for HackRF hardware or use Zadig see http://sourceforge.net/projects/libwdi/files/zadig
        * If you want to use Zadig select HackRF USB device and just install/replace it with WinUSB driver.

Note for Windows build: You shall always execute hackrf-tools from Windows command shell and not from Cygwin or MinGW shell because on Cygwin/MinGW Ctrl+C is not managed correctly and especially for hackrf_transfer the Ctrl+C (abort) will not stop correctly and will corrupt the file.

Windows: Installing HackRF Software via Cygwin
++++++++++++++++++++++++++++++++++++++++++++++

.. code-block :: sh

	mkdir host/build
	cd host/build
	cmake ../ -G "Unix Makefiles" -DCMAKE_LEGACY_CYGWIN_WIN32=1 -DLIBUSB_INCLUDE_DIR=/usr/local/include/libusb-1.0/
	make
	make install

Windows: Installing HackRF Software via MinGW
+++++++++++++++++++++++++++++++++++++++++++++

.. code-block :: sh

	mkdir host/build
	cd host/build
	cmake ../ -G "MSYS Makefiles" -DLIBUSB_INCLUDE_DIR=/usr/local/include/libusb-1.0/
	make
	make install

Windows: Installing HackRF Software via Visual Studio 2015 x64
++++++++++++++++++++++++++++++++++++++++++++++++++++++++++++++

Create library definition for MSVC to link to ``C:\fftw-3.3.5-dll64> lib /machine:x64 /def:libfftw3f-3.def``

.. code-block :: sh

	c:\hackrf\host\build> cmake ../ -G "Visual Studio 14 2015 Win64" \
	-DLIBUSB_INCLUDE_DIR=c:\libusb-1.0.21\libusb \
	-DLIBUSB_LIBRARIES=c:\libusb-1.0.21\MS64\dll\lib\libusb-1.0.lib \
	-DTHREADS_PTHREADS_INCLUDE_DIR=c:\pthreads-w32-2-9-1-release\Pre-built.2\include \
	-DTHREADS_PTHREADS_WIN32_LIBRARY=c:\pthreads-w32-2-9-1-release\Pre-built.2\lib\x64\pthreadVC2.lib \
	-DFFTW_INCLUDES=C:\fftw-3.3.5-dll64 \
	-DFFTW_LIBRARIES=C:\fftw-3.3.5-dll64\libfftw3f-3.lib

CMake will produce a solution file named ``HackRF.sln`` and a series of project files which can be built with msbuild as follows: ``c:\hackrf\host\build> msbuild HackRF.sln``

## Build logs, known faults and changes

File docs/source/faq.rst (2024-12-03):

.. _faq:

================================================
FAQ
================================================

What is the Transmit Power of HackRF?
~~~~~~~~~~~~~~~~~~~~~~~~~~~~~~~~~~~~~

HackRF One's absolute maximum TX power varies by operating frequency:

    * 1 MHz to 10 MHz: 5 dBm to 15 dBm, generally increasing as frequency increases (see this `blog post <https://greatscottgadgets.com/2015/05-15-hackrf-one-at-1-mhz/>`__)
    * 10 MHz to 2170 MHz: 5 dBm to 15 dBm, generally decreasing as frequency increases
    * 2170 MHz to 2740 MHz: 13 dBm to 15 dBm
    * 2740 MHz to 4000 MHz: 0 dBm to 5 dBm, decreasing as frequency increases
    * 4000 MHz to 6000 MHz: -10 dBm to 0 dBm, generally decreasing as frequency increases

Through most of the frequency range up to 4 GHz, the maximum TX power is between 0 and 10 dBm. The frequency range with best performance is 2170 MHz to 2740 MHz.

Overall, the output power is enough to perform over-the-air experiments at close range or to drive an external amplifier. If you connect an external amplifier, you should also use an external bandpass filter for your operating frequency.

Before you transmit, know your laws. HackRF One has not been tested for compliance with regulations governing transmission of radio signals. You are responsible for using your HackRF One legally.

----

What is the Receive Power of HackRF?
~~~~~~~~~~~~~~~~~~~~~~~~~~~~~~~~~~~~

The maximum RX power of HackRF One is -5 dBm. Exceeding -5 dBm can result in permanent damage!

In theory, HackRF One can safely accept up to 10 dBm with the front-end RX amplifier disabled. However, a simple software or user error could enable the amplifier, resulting in permanent damage. It is better to use an external attenuator than to risk damage.

----

What is the minimum signal power level that can be detected by HackRF?
~~~~~~~~~~~~~~~~~~~~~~~~~~~~~~~~~~~~~~~~~~~~~~~~~~~~~~~~~~~~~~~~~~~~~~

This isn't a question that can be answered for a general purpose SDR platform such as HackRF. Any answer would be very specific to a particular application. For example, an answerable question might be: What is the minimum power level in dBm of modulation M at frequency F that can be detected by HackRF One with software S under configuration C at a bit error rate of no more than E%? Changing any of those variables (M, F, S, C, or E) would change the answer to the question. Even a seemingly minor software update might result in a significantly different answer. To learn the exact answer for a specific application, you would have to measure it yourself.

HackRF's concrete specifications include operating frequency range, maximum sample rate, and dynamic range in bits. These specifications can be used to roughly determine the suitability of HackRF for a given application. Testing is required to finely measure performance in an application. Performance can typically be enhanced significantly by selecting an appropriate antenna, external amplifier, and/or external filter for the application.

----

Is HackRF full-duplex?
~~~~~~~~~~~~~~~~~~~~~~

HackRF One is a half-duplex transceiver. This means that it can transmit or receive but not both at the same time.

----

Why isn't HackRF One full-duplex?
~~~~~~~~~~~~~~~~~~~~~~~~~~~~~~~~~

HackRF One is designed to support the widest possible range of SDR applications in a single, low cost, portable device. Many applications do not require full-duplex operation. Full-duplex support would have made HackRF larger and more expensive, and it would have required an external power supply. Since full-duplex needs can be met by simply using a second HackRF One, it made sense to keep the device small, portable, and low cost for everyone who does not require full-duplex operation.

----

How could the HackRF One design be changed to make it full-duplex?
~~~~~~~~~~~~~~~~~~~~~~~~~~~~~~~~~~~~~~~~~~~~~~~~~~~~~~~~~~~~~~~~~~

The HackRF One hardware design is actually full-duplex (at lower sample rates) from the USB connection through the ADC/DAC. The RF section is the only part of the design that cannot support full-duplex operation. The easiest way to make HackRF One full-duplex would be to create an add-on board that duplicates the RF section and also provides an external power input (from a wall wart, for example) for the additional power required. This would also require software effort; the firmware, CPLD, libhackrf, and other host software would all need work to support full-duplex operation.

If you were to try to redesign the RF section on HackRF One to support full-duplex, the main thing to focus on would be the MAX2837 (intermediate frequency transceiver). This part is half-duplex, so you would either need two of them or you would have to redesign the RF section to use something other than the MAX2837, likely resulting in a radically different design. If you used two MAX2837s you might be able to use one RFFC5071 instead of two RFFC5072s.

----

.. _bigspike:

What is the big spike in the center of my received spectrum?
~~~~~~~~~~~~~~~~~~~~~~~~~~~~~~~~~~~~~~~~~~~~~~~~~~~~~~~~~~~~

If you see a large spike in the center of your FFT display regardless of the frequenecy you are tuned to, you are seeing a DC offset (or component or bias). The term "DC" comes from "Direct Current" in electronics. It is the unchanging aspect of a signal as opposed to the "alternating" part of the signal (AC) that changes over time. Take, for example, the signal represented by the digital sequence:

.. code-block:: sh

	-2, -1, 1, 6, 8, 9, 8, 6, 1, -1, -2, -1, 1, 6, 8, 9, 8, 6, 1, -1, -2, -1, 1, 6, 8, 9, 8, 6, 1, -1

This periodic signal contains a strong sinusoidal component spanning from -2 to 9. If you were to plot the spectrum of this signal, you would see one spike at the frequency of this sinusoid and a second spike at 0 Hz (DC). If the signal spanned from values -2 to 2 (centered around zero), there would be no DC offset. Since it is centered around 3.5 (the number midway between -2 and 9), there is a DC component.

Samples produced by HackRF are measurements of radio waveforms, but the measurement method is prone to a DC bias introduced by HackRF. It's an artifact of the measurement system, not an indication of a received radio signal. DC offset is not unique to HackRF; it is common to all quadrature sampling systems.

There was a bug in the HackRF firmware (through release 2013.06.1) that made the DC offset worse than it should have been. In the worst cases, certain Jawbreakers experienced a DC offset that drifted to a great extreme over several seconds of operation. This bug has been fixed. The fix reduces DC offset but does not do away with it entirely. It is something you have to live with when using any quadrature sampling system like HackRF.

A high DC offset is also one of a few symptoms that can be caused by a software version mismatch. A common problem is that people run an old version of gr-osmosdr with newer firmware.

----

How do I deal with the big spike in the middle of my spectrum?
~~~~~~~~~~~~~~~~~~~~~~~~~~~~~~~~~~~~~~~~~~~~~~~~~~~~~~~~~~~~~~

Start by reading :ref:`our FAQ Response on the DC Spike <bigspike>`. After that, there are a few options:

    #. Ignore it. For many applications it isn't a problem. You'll learn to ignore it.

    #. Avoid it. The best way to handle DC offset for most applications is to use offset tuning; instead of tuning to your exact frequency of interest, tune to a nearby frequency so that the entire signal you are interested in is shifted away from 0 Hz but still within the received bandwidth. If your algorithm works best with your signal centered at 0 Hz (many do), you can shift the frequency in the digital domain, moving your signal of interest to 0 Hz and your DC offset away from 0 Hz. HackRF's high maximum sampling rate can be a big help as it allows you to use offset tuning even for relatively wideband signals.

    #. Correct it. There are various ways of removing the DC offset in software. However, these techniques may degrade parts of the signal that are close to 0 Hz. It may look better, but that doesn't necessarily mean that it is better from the standpoint of a demodulator algorithm, for example. Still, correcting the DC offset is often a good choice.

---

What gain controls are provided by HackRF?
~~~~~~~~~~~~~~~~~~~~~~~~~~~~~~~~~~~~~~~~~~

HackRF (both Jawbreaker and One) provides three different analog gain controls on RX and two on TX.

The three RX gain controls are at these stages:

- RF ("amp", 0 or ~11 dB)
- IF ("lna", 0 to 40 dB in 8 dB steps)
- baseband ("vga", 0 to 62 dB in 2 dB steps)
 
The two TX gain controls are at these stages:

- RF (0 or ~11 dB)
- IF (0 to 47 dB in 1 dB steps)

Note: in some documents, the RF gain was erroneously quoted to be 14 dB. The confusion was based on the fact that the MGA-81563 amplifier is advertised as a "14 dBm" amplifier, but that specifies its output power, not its amplification. See `Martin Ling's comment on issue #1059 <https://github.com/greatscottgadgets/hackrf/issues/1059#issuecomment-1060038293>`__ for some details!

----

Why is the RF gain setting restricted to two values?
~~~~~~~~~~~~~~~~~~~~~~~~~~~~~~~~~~~~~~~~~~~~~~~~~~~~

HackRF has two RF amplifiers close to the antenna port, one for TX and one for RX. These amplifiers have two settings: on or off. In the off state, the amps are completely bypassed. They nominally provide around 11 dB of gain when on, but the actual amount of gain varies by frequency. In general, expect less gain at higher frequencies. For fine control of gain, use the IF and/or baseband gain options.

----

Why are the LEDs on HackRF different colours?
~~~~~~~~~~~~~~~~~~~~~~~~~~~~~~~~~~~~~~~~~~~~~

Each LED is a single color. There are no multi-colored LEDs on HackRF One. Adjacent LEDs are different colors in order to make them easier to distinguish from one another. The colors do not mean anything.

----

Where can I purchase HackRF?
~~~~~~~~~~~~~~~~~~~~~~~~~~~~

HackRF is designed and manufactured by Great Scott Gadgets. We do not sell low volumes of HackRFs to people individually; instead we have agreements with specific resellers. Please see our reseller list on the Great Scott Gadgets website for availability: `http://greatscottgadgets.com/hackrf/ <http://greatscottgadgets.com/hackrf/>`__. 

HackRF is open source hardware, so you can also build your own.

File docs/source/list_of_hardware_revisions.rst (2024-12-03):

================================================
Hardware Revisions
================================================

HackRF One hardware revisions exist mainly to deal with changes in component availability. Each of the revisions meet the same performance specifications that are measured in the factory. 

List of Hardware Revisions
~~~~~~~~~~~~~~~~~~~~~~~~~~

HackRF One r1–r4
^^^^^^^^^^^^^^^^

The first revision of HackRF One shipped by Great Scott Gadgets starting in 2014 was labeled r1. Subsequent manufacturing runs incremented the revision number up to r4 without modification to the hardware design. Manufacturing years: 2014–2020

HackRF One r5
^^^^^^^^^^^^^

This experimental revision has not been manufactured.

HackRF One r6
^^^^^^^^^^^^^

SKY13350 RF switches were replaced by SKY13453. Although the SKY13453 uses simplified control logic, it did not require a firmware modification. Hardware revision detection pin straps were added. Manufacturing year: 2020

HackRF One r7
^^^^^^^^^^^^^

SKY13453 RF switches were reverted to SKY13350. USB VBUS detection resistor values were updated. Manufacturing year: 2021

HackRF One r8
^^^^^^^^^^^^^

SKY13350 RF switches were replaced by SKY13453. Manufacturing years: 2021–2022

HackRF One r9
^^^^^^^^^^^^^

MAX2837 was replaced by MAX2839. Si5351C was replaced by Si5351A with additional clock distribution. A series diode was added to the antenna port power supply. Manufacturing year: 2023

HackRF One r10
^^^^^^^^^^^^^^

This revision is based on r8, reverting most of the changes made in r9. A series diode was added to the antenna port power supply. Manufacturing year: 2024

Hardware Revision Identification
~~~~~~~~~~~~~~~~~~~~~~~~~~~~~~~~

HackRF Ones manufactured by Great Scott Gadgets have the revision number printed on the PCB top silkscreen layer near the MAX5864 (U18).

Starting with HackRF One r6, hardware revisions are detected by firmware and reported by ``hackrf_info``.

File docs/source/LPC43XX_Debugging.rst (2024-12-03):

================================================
LPC43xx Debugging
================================================

Various debugger options for the LPC43xx exist.

Black Magic Probe
~~~~~~~~~~~~~~~~~

`https://github.com/blacksphere/blackmagic <https://github.com/blacksphere/blackmagic>`__

An example of using gdb with the Black Magic Probe:

.. code-block :: sh

	arm-none-eabi-gdb -n blinky.elf
	target extended-remote /dev/ttyACM0
	monitor swdp_scan
	attach 1
	set {int}0x40043100 = 0x10000000
	load
	cont

It is possible to attach to the M0 instead of the M4 if you use jtag_scan instead of swdp_scan, but the Black Magic Probe had some bugs when trying to work with the M0 the last time I tried it.  

LPC-Link
~~~~~~~~

(included with LPCXpresso boards)

TitanMKD has had some success. See the tutorial in hackrf/doc/LPCXPresso_Flash_Debug_Tutorial.pdf or .odt (PDF and OpenOffice document) Doc Link [https://github.com/mossmann/hackrf/tree/master/doc)

ST-LINK/V2
~~~~~~~~~~

Hardware Configuration
^^^^^^^^^^^^^^^^^^^^^^

Start with an STM32F4-Discovery board. Remove the jumpers from CN3. Connect the target's SWD interface to CN2 "SWD" connector.

Software Configuration
^^^^^^^^^^^^^^^^^^^^^^

I'm using libusb-1.0.9.

Install OpenOCD-0.6.0 dev
+++++++++++++++++++++++++

.. code-block:: sh

	# Cloned at hash a21affa42906f55311ec047782a427fcbcb98994
	git clone git://openocd.git.sourceforge.net/gitroot/openocd/openocd
	cd openocd
	./bootstrap
	./configure --enable-stlink --enable-buspirate --enable-jlink --enable-maintainer-mode
	make
	sudo make install

OpenOCD configuration files
+++++++++++++++++++++++++++

openocd.cfg

.. code-block:: sh

	#debug_level 3
	source [find interface/stlink-v2.cfg]
	source ./lpc4350.cfg

lpc4350.cfg

.. code-block :: sh

	set _CHIPNAME lpc4350
	set _M0_CPUTAPID 0x4ba00477
	set _M4_SWDTAPID 0x2ba01477
	set _M0_TAPID 0x0BA01477
	set _TRANSPORT stlink_swd

	transport select $_TRANSPORT

	stlink newtap $_CHIPNAME m4 -expected-id $_M4_SWDTAPID
	stlink newtap $_CHIPNAME m0 -expected-id $_M0_TAPID

	target create $_CHIPNAME.m4 stm32_stlink -chain-position $_CHIPNAME.m4
	#target create $_CHIPNAME.m0 stm32_stlink -chain-position $_CHIPNAME.m0

target.xml, nabbed from an OpenOCD mailing list thread, to fix a communication problem between GDB and newer OpenOCD builds.

.. code-block:: sh

	<?xml version="1.0"?>
	<!DOCTYPE target SYSTEM "gdb-target.dtd">
	<target>
	  <feature name="org.gnu.gdb.arm.core">
	    <reg name="r0" bitsize="32" type="uint32"/>
	    <reg name="r1" bitsize="32" type="uint32"/>
	    <reg name="r2" bitsize="32" type="uint32"/>
	    <reg name="r3" bitsize="32" type="uint32"/>
	    <reg name="r4" bitsize="32" type="uint32"/>
	    <reg name="r5" bitsize="32" type="uint32"/>
	    <reg name="r6" bitsize="32" type="uint32"/>
	    <reg name="r7" bitsize="32" type="uint32"/>
	    <reg name="r8" bitsize="32" type="uint32"/>
	    <reg name="r9" bitsize="32" type="uint32"/>
	    <reg name="r10" bitsize="32" type="uint32"/>
	    <reg name="r11" bitsize="32" type="uint32"/>
	    <reg name="r12" bitsize="32" type="uint32"/>
	    <reg name="sp" bitsize="32" type="data_ptr"/>
	    <reg name="lr" bitsize="32"/>
	    <reg name="pc" bitsize="32" type="code_ptr"/>
	    <reg name="cpsr" bitsize="32" regnum="25"/>
	  </feature>
	  <feature name="org.gnu.gdb.arm.fpa">
	    <reg name="f0" bitsize="96" type="arm_fpa_ext" regnum="16"/>
	    <reg name="f1" bitsize="96" type="arm_fpa_ext"/>
	    <reg name="f2" bitsize="96" type="arm_fpa_ext"/>
	    <reg name="f3" bitsize="96" type="arm_fpa_ext"/>
	    <reg name="f4" bitsize="96" type="arm_fpa_ext"/>
	    <reg name="f5" bitsize="96" type="arm_fpa_ext"/>
	    <reg name="f6" bitsize="96" type="arm_fpa_ext"/>
	    <reg name="f7" bitsize="96" type="arm_fpa_ext"/>
	    <reg name="fps" bitsize="32"/>
	  </feature>
	</target>

Run ARM GDB
~~~~~~~~~~~

Soon, I should dump this stuff into a .gdbinit file.

.. code-block:: sh

	arm-none-eabi-gdb -n
	target extended-remote localhost:3333
	set tdesc filename target.xml
	monitor reset init
	monitor mww 0x40043100 0x10000000
	monitor mdw 0x40043100   # Verify 0x0 shadow register is set properly.
	file lpc4350-test.axf    # This is an ELF file.
	load                     # Place image into RAM.
	monitor reset init
	break main               # Set a breakpoint.
	continue                 # Run to breakpoint.
	continue                 # To continue from the breakpoint.
	step                     # Step-execute the next source line.
	stepi                    # Step-execute the next processor instruction.
	info reg                 # Show processor registers.

More GDB tips for the GDB-unfamiliar:

.. code-block:: sh

	# Write the variable "buffer" (an array) to file "buffer.u8".
	dump binary value buffer.u8 buffer

	# Display the first 32 values in buffer whenever you halt
	# execution.
	display/32xh buffer

	# Print the contents of a range of registers (in this case the
	# CGU peripheral, starting at 0x40050014, for 46 words):
	x/46 0x40050014

And still more, for debugging ARM Cortex-M4 Hard Faults:

.. code-block :: sh

	# Assuming you have a hard-fault handler wired in:
	display/8xw args

	# Examine fault-related registers:

	# Configurable Fault Status Register (CFSR) contains:
	# CFSR[15:8]: BusFault Status Register (BFSR)
	#   "Shows the status of bus errors resulting from instruction
	#   prefetches and data accesses."
	#   BFSR[7]: BFARVALID: BFSR contents valid.
	#   BFSR[5]: LSPERR: fault during FP lazy state preservation.
	#   BFSR[4]: STKERR: derived bus fault on exception entry.
	#   BFSR[3]: UNSTKERR: derived bus fault on exception return.
	#   BFSR[2]: IMPRECISERR: imprecise data access error.
	#   BFSR[1]: PRECISERR: precise data access error, faulting
	#            address in BFAR.
	#   BFSR[0]: IBUSERR: bus fault on instruction prefetch. Occurs
	#            only if instruction is issued.
	display/xw 0xE000ED28

	# BusFault Address Register (BFAR)
	# "Shows the address associated with a precise data access fault."
	# "This is the location addressed by an attempted data access that
	# was faulted. The BFSR shows the reason for the fault and whether
	# BFAR_ADDRESS is valid..."
	# "For unaligned access faults, the value returned is the address
	# requested by the instruction. This might not be the address that
	# faulted."
	display/xw 0xE000ED38

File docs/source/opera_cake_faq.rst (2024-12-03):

=====================================
Frequently Asked Questions
=====================================

Why the name 'Opera Cake'?
~~~~~~~~~~~~~~~~~~~~~~~~~~

Internally at Great Scott Gadgets, HackRF related boards are code named with a candy or confection name. The Opera Cake code name was fun enough that we didn't change from it when we released the project.

When was Opera Cake first for sale?
~~~~~~~~~~~~~~~~~~~~~~~~~~~~~~~~~~~

Great Scott Gadgets first released Opera Cake for sale in 2022. The open source project for Opera Cake has been available since 2016 from Great Scott Gadgets.

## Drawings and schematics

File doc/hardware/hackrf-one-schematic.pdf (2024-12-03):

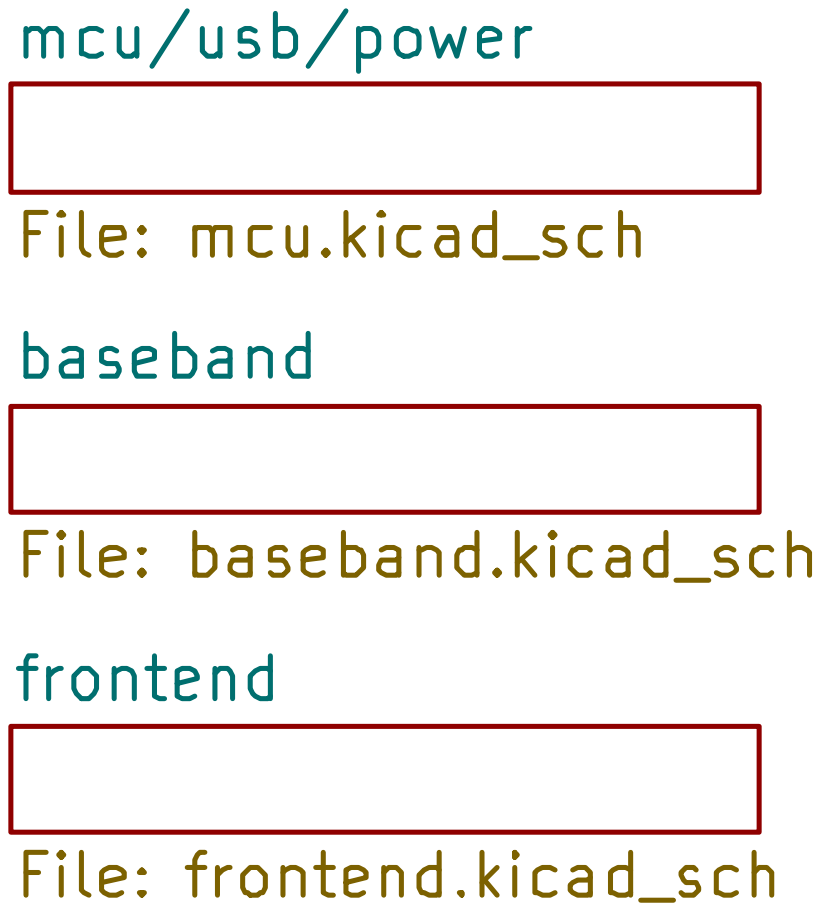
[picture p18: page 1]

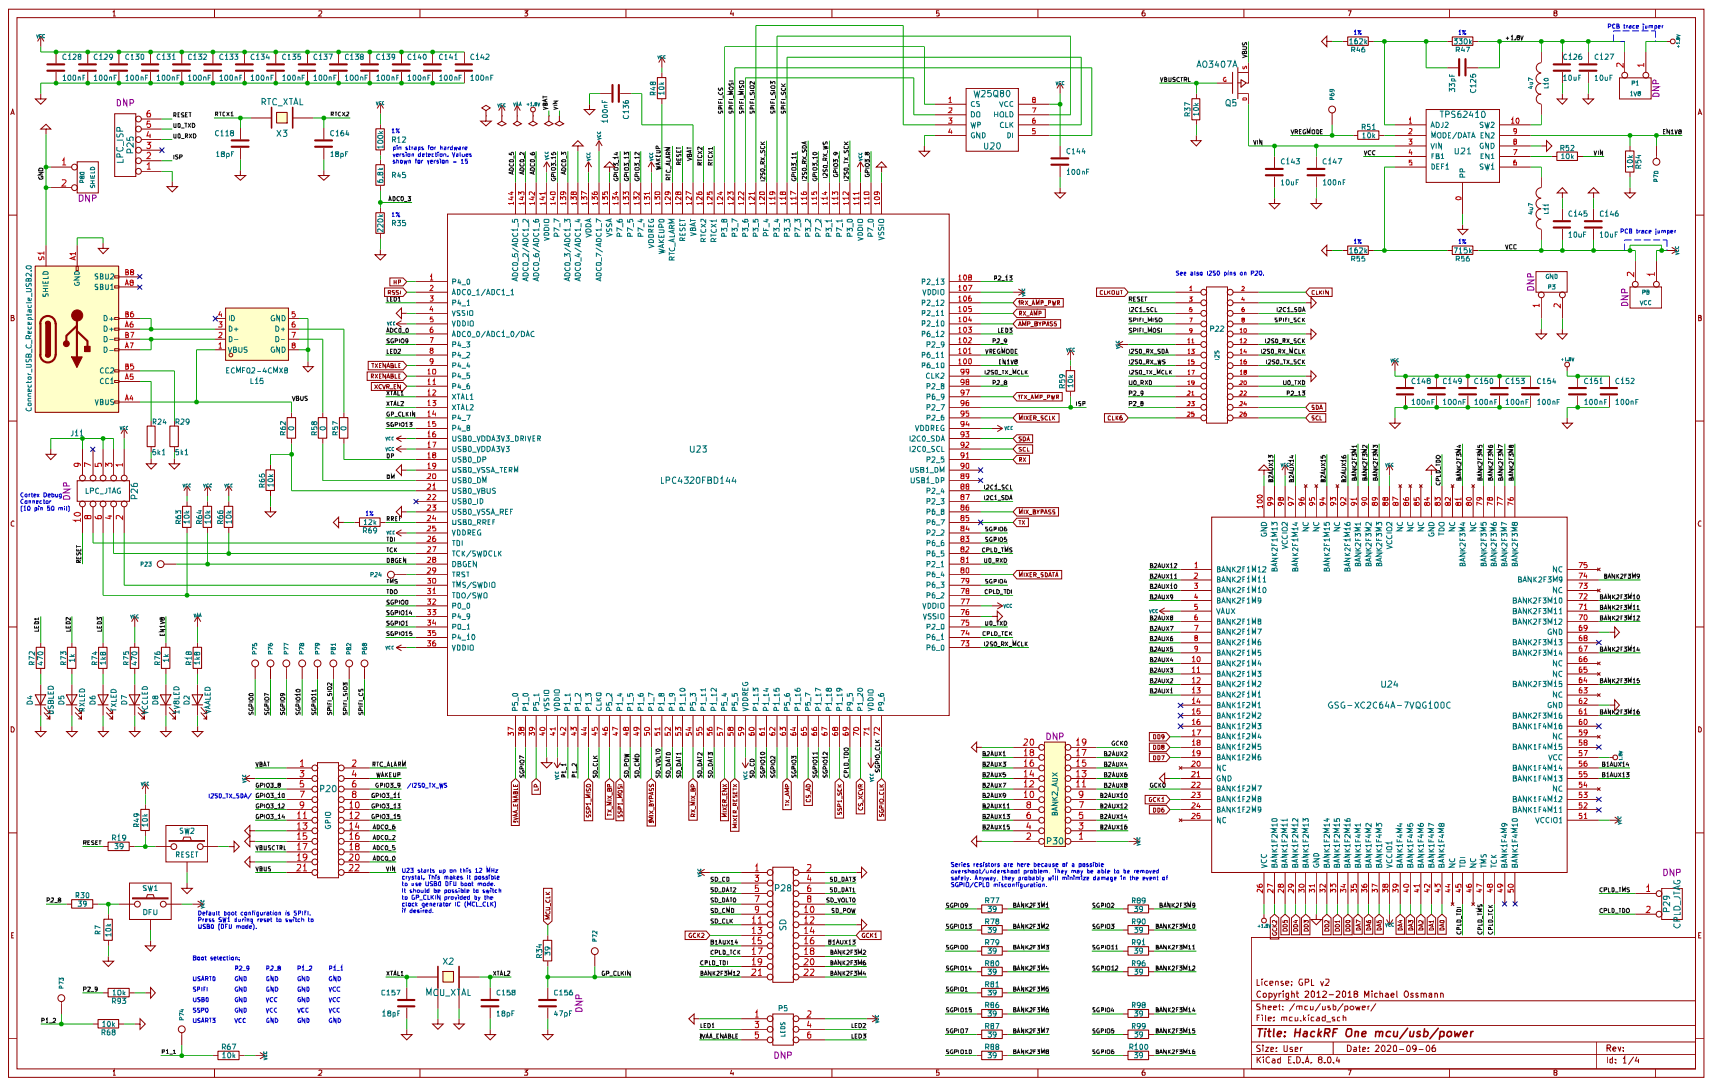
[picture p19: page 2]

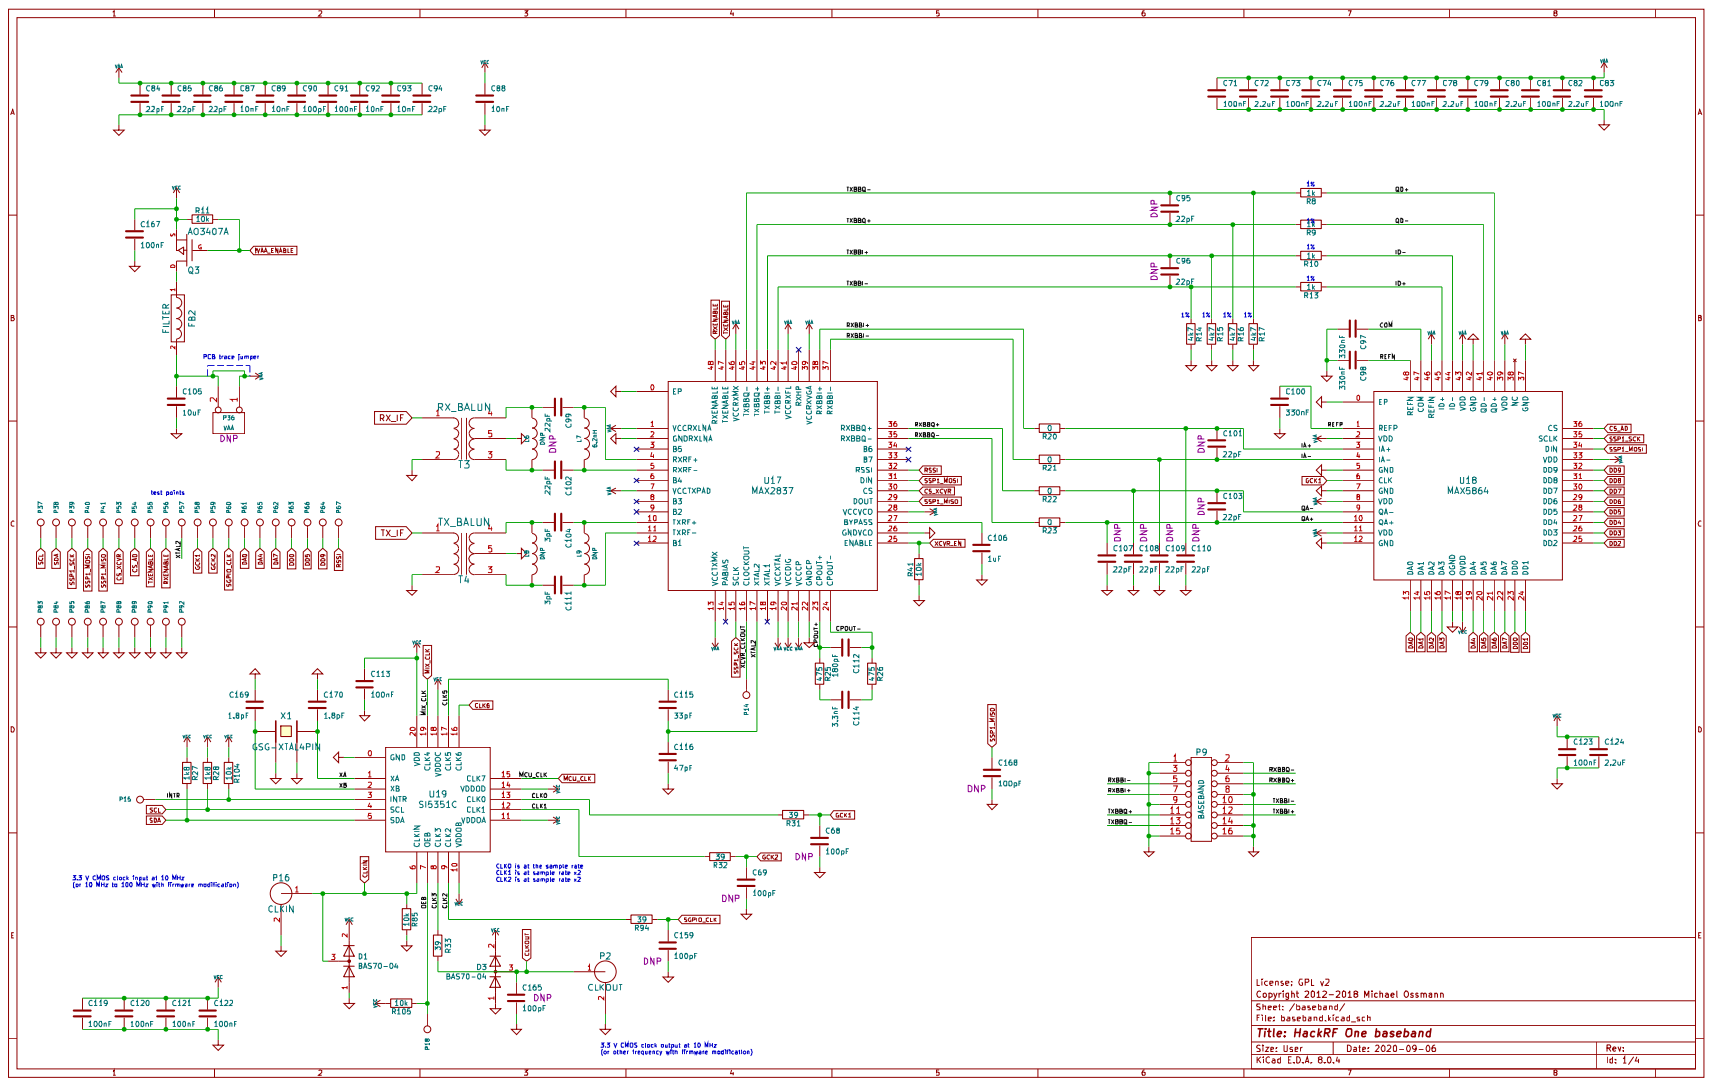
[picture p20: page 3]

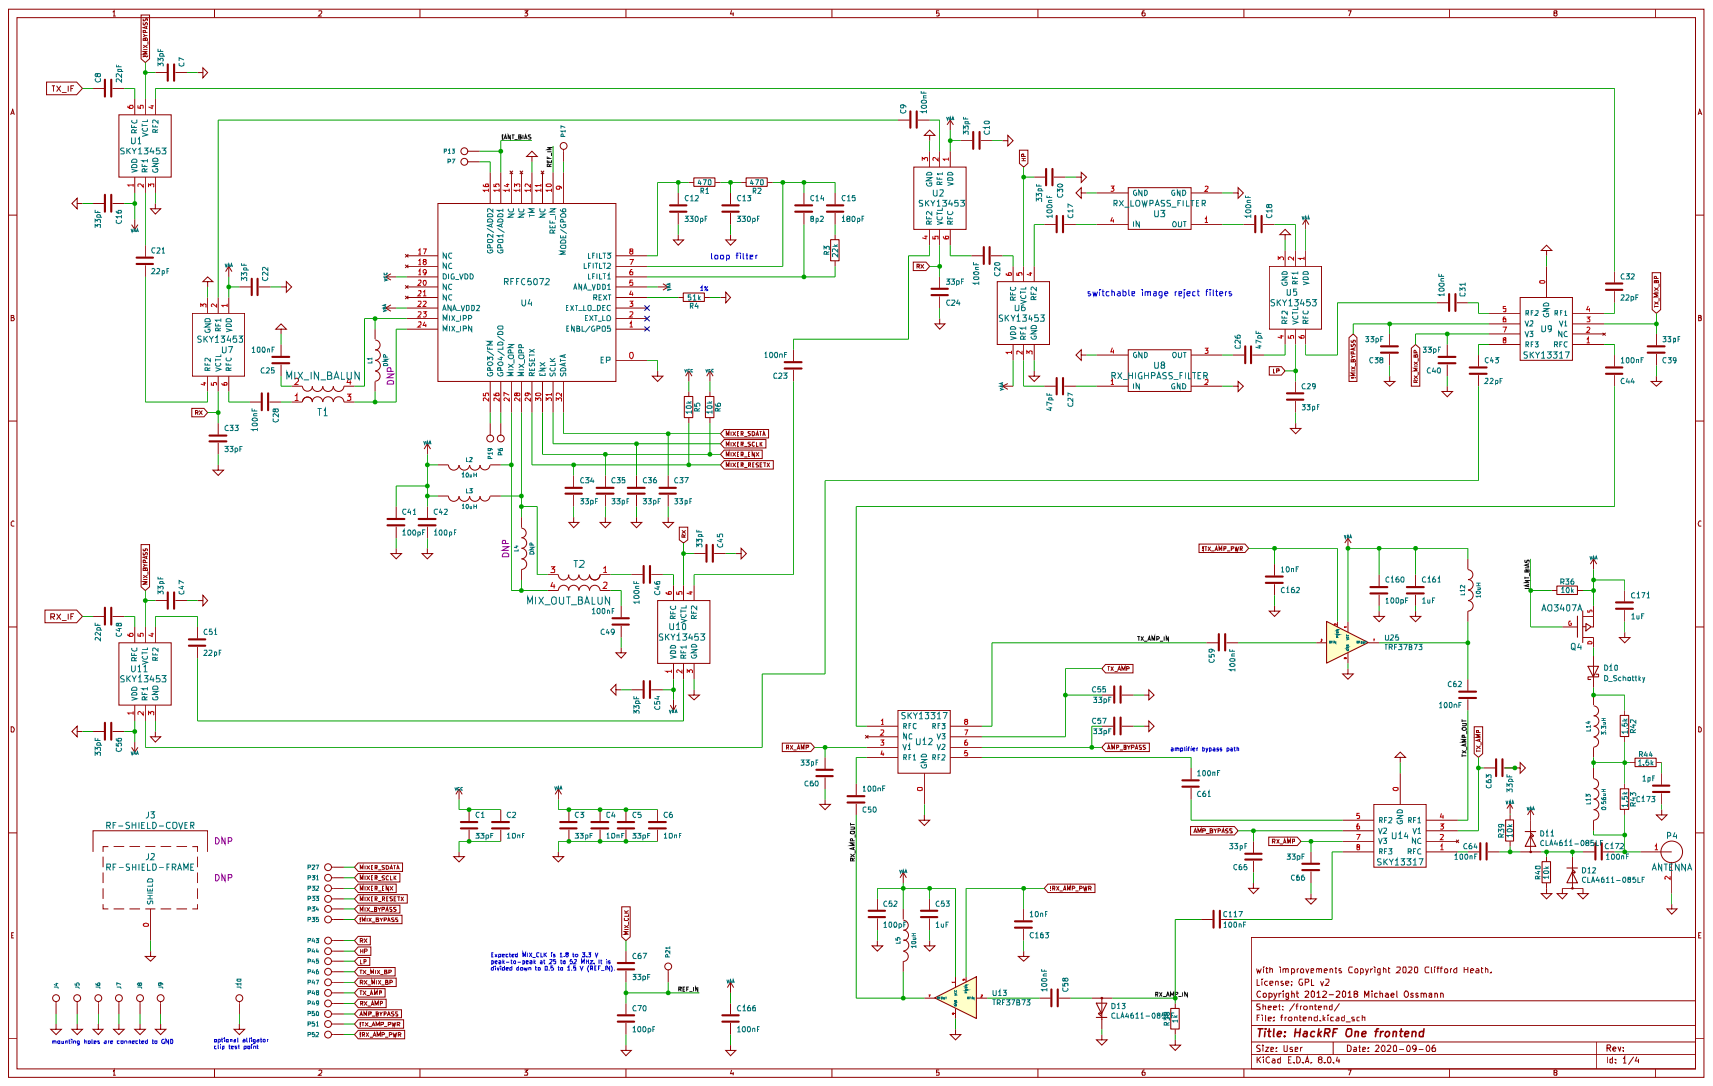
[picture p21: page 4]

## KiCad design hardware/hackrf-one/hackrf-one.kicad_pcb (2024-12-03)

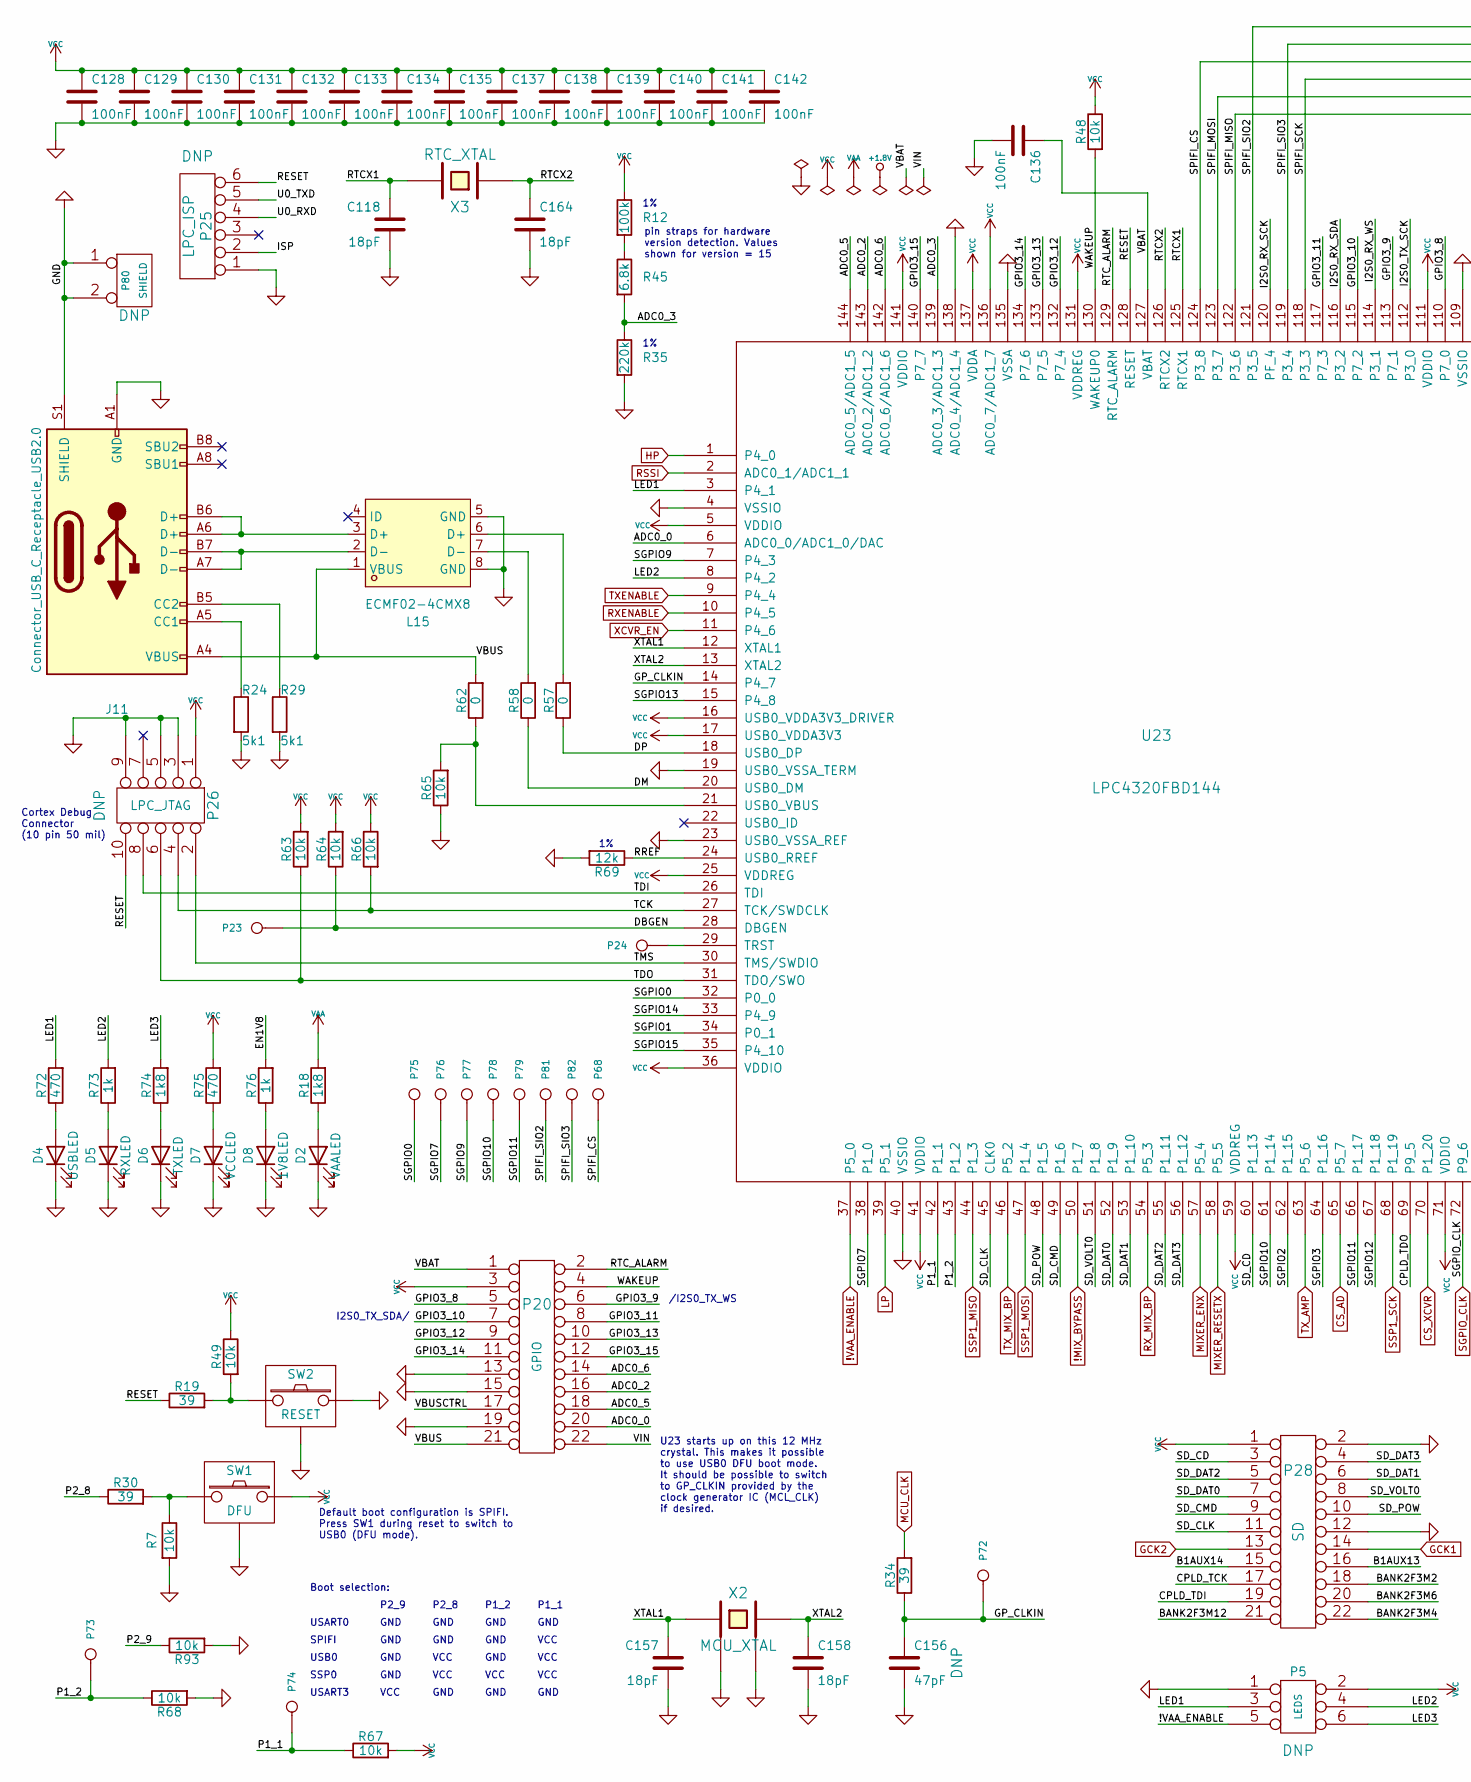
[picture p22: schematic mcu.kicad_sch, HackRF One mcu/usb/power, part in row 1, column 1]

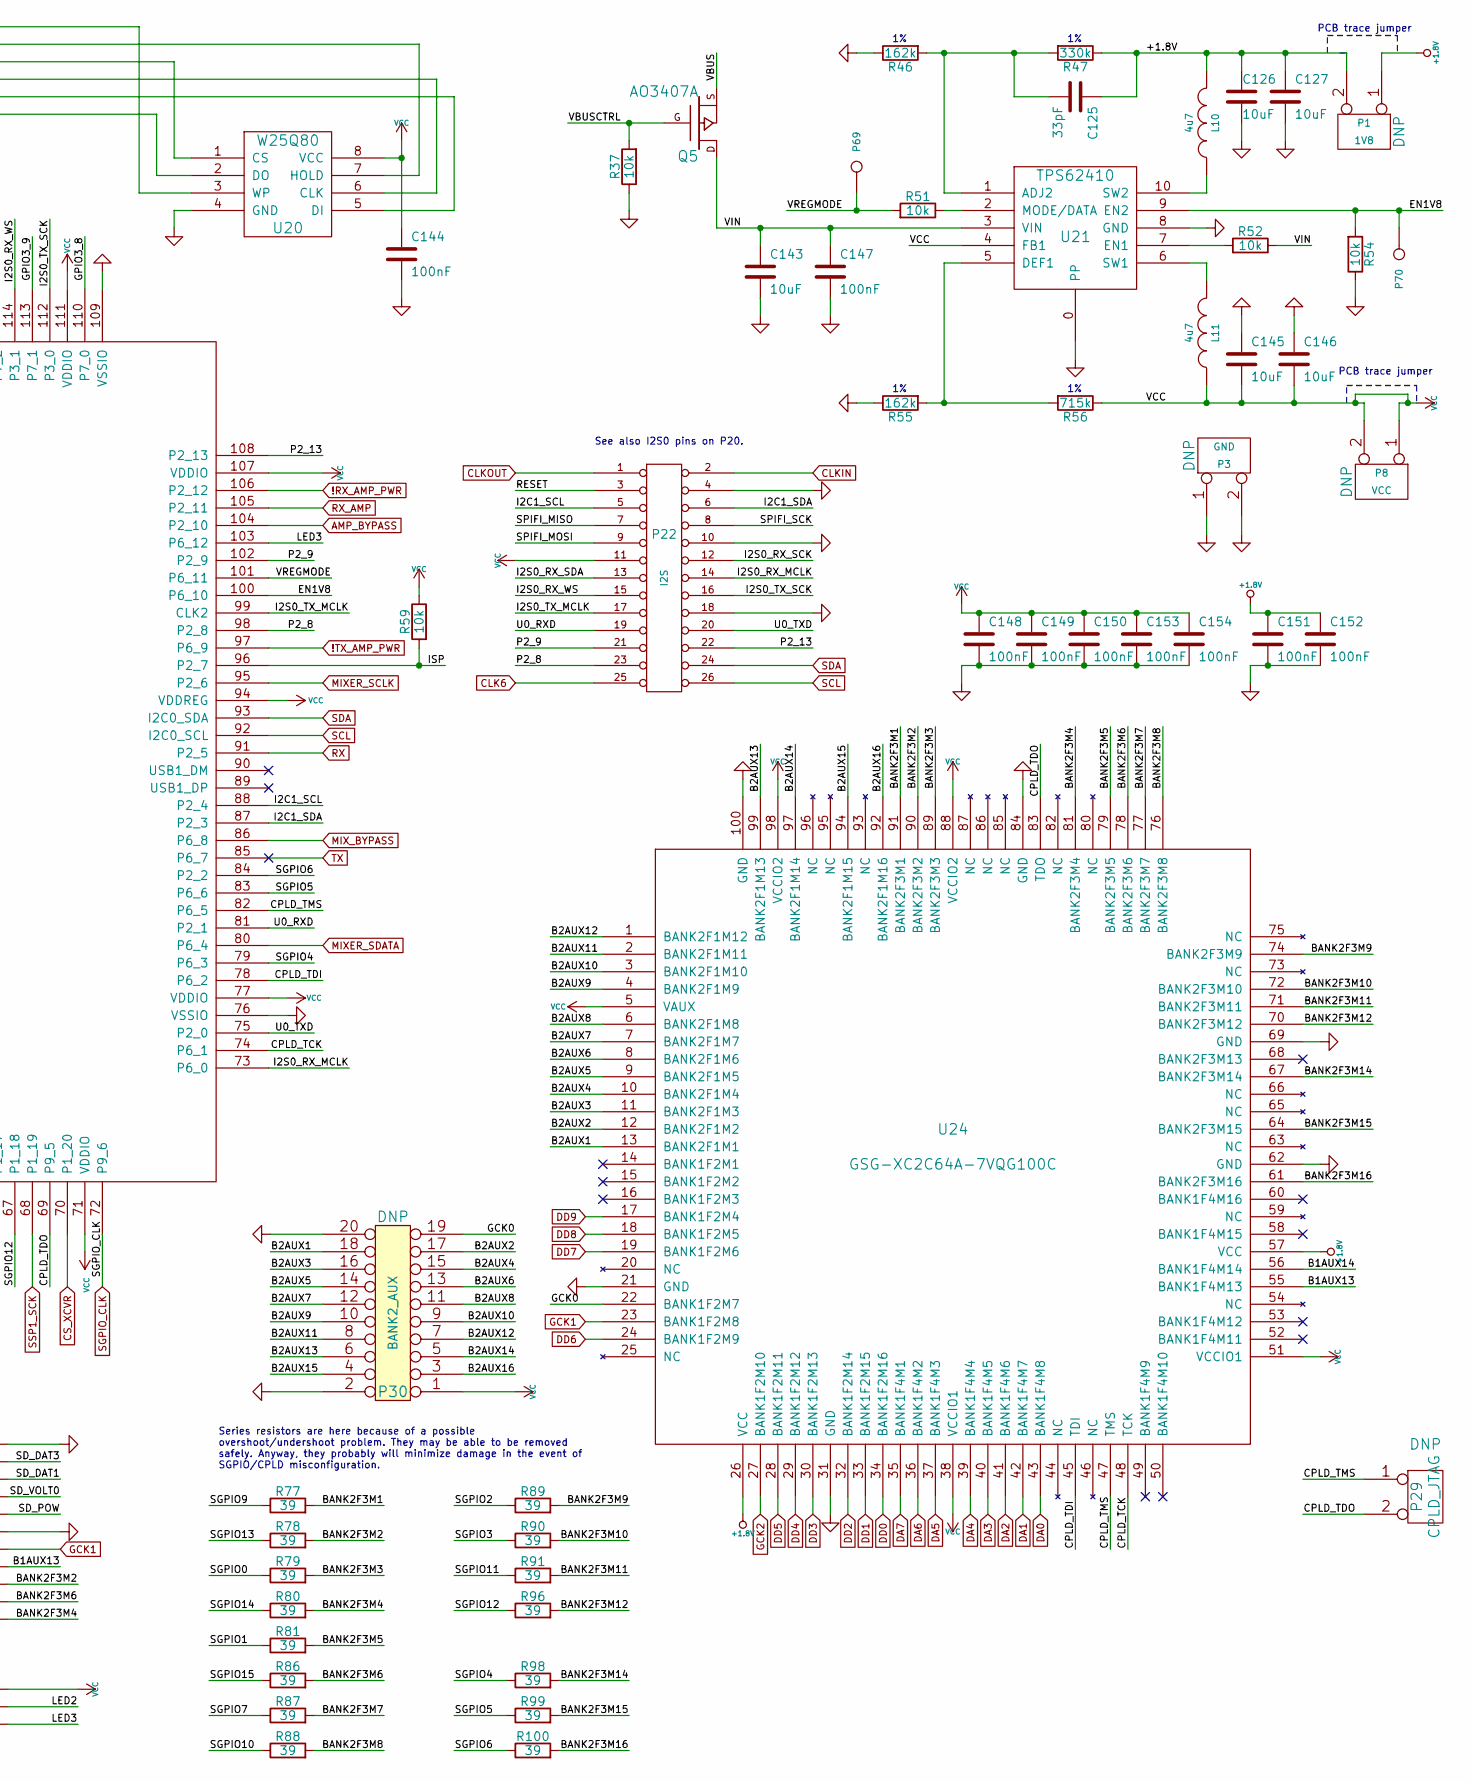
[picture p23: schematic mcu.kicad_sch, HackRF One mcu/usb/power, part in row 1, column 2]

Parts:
C118, C157, C158, C164: 18pF; GSG-0402; Part Number GRM1555C1H180JA01D
C125: 33pF; GSG-0402; Part Number GRM1555C1H330JA01D
C126, C127, C143, C145, C146: 10uF; GSG-0805; Part Number GRM21BR61A106KE19L
C128, C129, C130, C131, C132, C133, C134, C135, C136, C137, C138, C139, C140, C141, C142, C144, C147, C148, C149, C150, C151, C152, C153, C154: 100nF; GSG-0402; Part Number GRM155R61A104KA01D
C156: 47pF; GSG-0402; Part Number GRM1555C1H470JA01D
D2: VAALED; LTST-S220; Part Number LTST-S220KRKT
D4: USBLED; LTST-S220; Part Number LTST-S220KGKT
D5: RXLED; LTST-S220; Part Number LTST-S220KSKT
D6: TXLED; LTST-S220; Part Number LTST-S220KRKT
D7: VCCLED; LTST-S220; Part Number LTST-S220KGKT
D8: 1V8LED; LTST-S220; Part Number LTST-S220KSKT
J11: Connector_USB_C_Receptacle_USB2.0; USB-C_SMD-TYPE-C-31-M-12
L10, L11: 4u7; GSG-NRG4026; Part Number NRG4026T4R7M
L15: ECMF02-4CMX8; QFN-8_L2.5-W1.2-P0.50-BL; LCSC Part C717678
P1: 1V8; GSG-HEADER-1x2
P3: GND; GSG-HEADER-NOMARK-1x2
P5: LEDS; GSG-HEADER-2x3
P8: VCC; GSG-HEADER-1x2
P20: GPIO; GSG-HEADER-2x11; Part Number PPPC112LFBN-RC
P22: I2S; GSG-HEADER-2x13; Part Number PPPC132LFBN-RC
P23: DBGEN; GSG-TESTPOINT-50MIL
P24: TRST; GSG-TESTPOINT-50MIL
P25: LPC_ISP; GSG-HEADER-1x6
P26: LPC_JTAG; GSG-50MIL-HEADER-2x5-TH; Part Number GRPB052VWVN-RC
P28: SD; GSG-HEADER-2x11; Part Number PPPC112LFBN-RC
P29: CPLD_JTAG; GSG-HEADER-1x2
P30: BANK2_AUX; GSG-HEADER-2x10
P68: SPIFI_CS; GSG-TESTPOINT-50MIL
P69: VREGMODE; GSG-TESTPOINT-50MIL
P70: EN_1V8; GSG-TESTPOINT-50MIL
P72, P75, P76, P77, P78, P79: GP_CLKIN; GSG-TESTPOINT-50MIL
P73: P1_2; GSG-TESTPOINT-50MIL
P74: P1_1; GSG-TESTPOINT-50MIL
P80: SHIELD; GSG-HEADER-NOMARK-1x2
P81: SPIFI_SIO2; GSG-TESTPOINT-50MIL
P82: SPIFI_SIO3; GSG-TESTPOINT-50MIL
Q5: AO3407A; SOT23GDS; Part Number AO3407A
R7, R37, R48, R49, R51, R52, R54, R59, R63, R64, R65, R66, R67, R68, R93: 10k; GSG-0402; Part Number RMCF0402JT10K0
R12: 100k; GSG-0402; Part Number RC0402FR-0715K4L
R18, R74: 1k8; GSG-0402; Part Number RMCF0402JT1K80
R19, R30, R34, R77, R78, R79, R80, R81, R86, R87, R88, R89, R90, R91, R96, R98, R99, R100: 39; GSG-0402; Part Number RMCF0402JT39R0
R24, R29: 5k1; GSG-0402
R35: 220k; GSG-0402; Part Number RMCF0402FT330K
R45: 6.8k; GSG-0402; Part Number RC0402FR-0715K4L
R46, R55: 162k; GSG-0402; Part Number RMCF0402FT162K
R47: 330k; GSG-0402; Part Number RMCF0402FT330K
R56: 715k; GSG-0402; Part Number RMCF0402FT715K
R57, R58, R62: 0; GSG-0402; Part Number RMCF0402ZT0R00
R69: 12k; GSG-0402; Part Number MCR01MRTF1202
R72, R75: 470; GSG-0402; Part Number RMCF0402JT470R
R73, R76: 1k; GSG-0402; Part Number RMCF0402FT1K00
SW1: DFU; GSG-SWITCH-FSMRA; Part Number FSMRA3JH
SW2: RESET; GSG-SWITCH-FSMRA; Part Number FSMRA3JH
U20: W25Q80; GSG-SOIC8-208; Part Number W25Q80DVSSIG
U21: TPS62410; GSG-S-PVSON-N10; Part Number TPS62410DRCR
U23: LPC4320FBD144; GSG-LQFP144; Part Number LPC4320FBD144,551
U24: GSG-XC2C64A-7VQG100C; GSG-VQ100; Part Number XC2C64A-7VQG100C
X2: MCU_XTAL; GSG-XTAL3.2x2.5mm; Part Number 7V-12.000MAAE-T
X3: RTC_XTAL; GSG-XTAL-AB26TRQ; Part Number AB26TRQ-32.768KHZ-T

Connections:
!MIX_BYPASS: U23.50 (P1_7); also elsewhere on the board
!RX_AMP_PWR: U23.106 (P2_12); also elsewhere on the board
!TX_AMP_PWR: U23.97 (P6_9); also elsewhere on the board
!VAA_ENABLE: P5.5, U23.37 (P5_0); also elsewhere on the board
+1.8V: C125.1, C126.1, C127.1, C151.1, C152.1, L10.2, P1.1, P1.2 (PM), R47.1, U24.26 (VCC), U24.57 (VCC)
/mcu/usb/power/ADC0_0: P20.20, U23.6 (ADC0_0/ADC1_0/DAC)
/mcu/usb/power/ADC0_2: P20.16, U23.143 (ADC0_2/ADC1_2)
/mcu/usb/power/ADC0_3: R35.1, R45.2, U23.139 (ADC0_3/ADC1_3)
/mcu/usb/power/ADC0_5: P20.18, U23.144 (ADC0_5/ADC1_5)
/mcu/usb/power/ADC0_6: P20.14, U23.142 (ADC0_6/ADC1_6)
/mcu/usb/power/B1AUX13: P28.16, U24.55 (BANK1F4M13)
/mcu/usb/power/B1AUX14: P28.15, U24.56 (BANK1F4M14)
/mcu/usb/power/B2AUX1: P30.18, U24.13 (BANK2F1M1)
/mcu/usb/power/B2AUX2: P30.17, U24.12 (BANK2F1M2)
/mcu/usb/power/B2AUX3: P30.16, U24.11 (BANK2F1M3)
/mcu/usb/power/B2AUX4: P30.15, U24.10 (BANK2F1M4)
/mcu/usb/power/B2AUX5: P30.14, U24.9 (BANK2F1M5)
/mcu/usb/power/B2AUX6: P30.13, U24.8 (BANK2F1M6)
/mcu/usb/power/B2AUX7: P30.12, U24.7 (BANK2F1M7)
/mcu/usb/power/B2AUX8: P30.11, U24.6 (BANK2F1M8)
/mcu/usb/power/B2AUX9: P30.10, U24.4 (BANK2F1M9)
/mcu/usb/power/B2AUX10: P30.9, U24.3 (BANK2F1M10)
/mcu/usb/power/B2AUX11: P30.8, U24.2 (BANK2F1M11)
/mcu/usb/power/B2AUX12: P30.7, U24.1 (BANK2F1M12)
/mcu/usb/power/B2AUX13: P30.6, U24.99 (BANK2F1M13)
/mcu/usb/power/B2AUX14: P30.5, U24.97 (BANK2F1M14)
/mcu/usb/power/B2AUX15: P30.4, U24.94 (BANK2F1M15)
/mcu/usb/power/B2AUX16: P30.3, U24.92 (BANK2F1M16)
/mcu/usb/power/BANK2F3M1: R77.2, U24.91 (BANK2F3M1)
/mcu/usb/power/BANK2F3M2: P28.18, R78.2, U24.90 (BANK2F3M2)
/mcu/usb/power/BANK2F3M3: R79.2, U24.89 (BANK2F3M3)
/mcu/usb/power/BANK2F3M4: P28.22, R80.2, U24.81 (BANK2F3M4)
/mcu/usb/power/BANK2F3M5: R81.2, U24.79 (BANK2F3M5)
/mcu/usb/power/BANK2F3M6: P28.20, R86.2, U24.78 (BANK2F3M6)
/mcu/usb/power/BANK2F3M7: R87.2, U24.77 (BANK2F3M7)
/mcu/usb/power/BANK2F3M8: R88.2, U24.76 (BANK2F3M8)
/mcu/usb/power/BANK2F3M9: R89.2, U24.74 (BANK2F3M9)
/mcu/usb/power/BANK2F3M10: R90.2, U24.72 (BANK2F3M10)
/mcu/usb/power/BANK2F3M11: R91.2, U24.71 (BANK2F3M11)
/mcu/usb/power/BANK2F3M12: P28.21, R96.2, U24.70 (BANK2F3M12)
/mcu/usb/power/BANK2F3M14: R98.2, U24.67 (BANK2F3M14)
/mcu/usb/power/BANK2F3M15: R99.2, U24.64 (BANK2F3M15)
/mcu/usb/power/BANK2F3M16: R100.2, U24.61 (BANK2F3M16)
/mcu/usb/power/CPLD_TCK: P28.17, U23.74 (P6_1), U24.48 (TCK)
/mcu/usb/power/CPLD_TDI: P28.19, U23.78 (P6_2), U24.45 (TDI)
/mcu/usb/power/CPLD_TDO: P29.2 (PM), U23.69 (P9_5), U24.83 (TDO)
/mcu/usb/power/CPLD_TMS: P29.1, U23.82 (P6_5), U24.47 (TMS)
/mcu/usb/power/DBGEN: P23.1, R64.1, U23.28 (DBGEN)
/mcu/usb/power/DM: R58.1, U23.20 (USB0_DM)
/mcu/usb/power/DP: R57.1, U23.18 (USB0_DP)
/mcu/usb/power/EN1V8: P70.1, R54.2, R76.2, U21.9 (EN2), U23.100 (P6_10)
/mcu/usb/power/GCK0: P30.19, U24.22 (BANK1F2M7)
/mcu/usb/power/GPIO3_8: P20.5, U23.110 (P7_0)
/mcu/usb/power/GPIO3_9: P20.6, U23.113 (P7_1)
/mcu/usb/power/GPIO3_10: P20.7, U23.115 (P7_2)
/mcu/usb/power/GPIO3_11: P20.8, U23.117 (P7_3)
/mcu/usb/power/GPIO3_12: P20.9, U23.132 (P7_4)
/mcu/usb/power/GPIO3_13: P20.10, U23.133 (P7_5)
/mcu/usb/power/GPIO3_14: P20.11, U23.134 (P7_6)
/mcu/usb/power/GPIO3_15: P20.12, U23.140 (P7_7)
/mcu/usb/power/GP_CLKIN: C156.1, P72.1, R34.1, U23.14 (P4_7)
/mcu/usb/power/I2C1_SCL: P22.5, U23.88 (P2_4)
/mcu/usb/power/I2C1_SDA: P22.6, U23.87 (P2_3)
/mcu/usb/power/I2S0_RX_MCLK: P22.14, U23.73 (P6_0)
/mcu/usb/power/I2S0_RX_SCK: P22.12, U23.120 (PF_4)
/mcu/usb/power/I2S0_RX_SDA: P22.13, U23.116 (P3_2)
/mcu/usb/power/I2S0_RX_WS: P22.15, U23.114 (P3_1)
/mcu/usb/power/I2S0_TX_MCLK: P22.17, U23.99 (CLK2)
/mcu/usb/power/I2S0_TX_SCK: P22.16, U23.112 (P3_0)
/mcu/usb/power/ISP: P25.2, R59.2, U23.96 (P2_7)
/mcu/usb/power/LED1: P5.3, R72.2, U23.3 (P4_1)
/mcu/usb/power/LED2: P5.4, R73.2, U23.8 (P4_2)
/mcu/usb/power/LED3: P5.6, R74.2, U23.103 (P6_12)
/mcu/usb/power/P1_1: P74.1, R67.1, U23.42 (P1_1)
/mcu/usb/power/P1_2: P73.1, R68.1, U23.43 (P1_2)
/mcu/usb/power/P2_8: P22.23, R30.1, U23.98 (P2_8)
/mcu/usb/power/P2_9: P22.21, R93.1, U23.102 (P2_9)
/mcu/usb/power/P2_13: P22.22, U23.108 (P2_13)
/mcu/usb/power/RESET: P22.3, P25.6, P26.10, R19.1, U23.128 (RESET)
/mcu/usb/power/RREF: R69.1, U23.24 (USB0_RREF)
/mcu/usb/power/RTCX1: C118.1, U23.125 (RTCX1), X3.2
/mcu/usb/power/RTCX2: C164.1, U23.126 (RTCX2), X3.1
/mcu/usb/power/RTC_ALARM: P20.2, U23.129 (RTC_ALARM)
/mcu/usb/power/SD_CD: P28.3, U23.60 (P1_13)
/mcu/usb/power/SD_CLK: P28.11, U23.45 (CLK0)
/mcu/usb/power/SD_CMD: P28.9, U23.49 (P1_6)
/mcu/usb/power/SD_DAT0: P28.7, U23.52 (P1_9)
/mcu/usb/power/SD_DAT1: P28.6, U23.53 (P1_10)
/mcu/usb/power/SD_DAT2: P28.5, U23.55 (P1_11)
/mcu/usb/power/SD_DAT3: P28.4, U23.56 (P1_12)
/mcu/usb/power/SD_POW: P28.10, U23.48 (P1_5)
/mcu/usb/power/SD_VOLT0: P28.8, U23.51 (P1_8)
/mcu/usb/power/SGPIO0: P75.1, R79.1, U23.32 (P0_0)
/mcu/usb/power/SGPIO1: R81.1, U23.34 (P0_1)
/mcu/usb/power/SGPIO2: R89.1, U23.62 (P1_15)
/mcu/usb/power/SGPIO3: R90.1, U23.64 (P1_16)
/mcu/usb/power/SGPIO4: R98.1, U23.79 (P6_3)
/mcu/usb/power/SGPIO5: R99.1, U23.83 (P6_6)
/mcu/usb/power/SGPIO6: R100.1, U23.84 (P2_2)
/mcu/usb/power/SGPIO7: P76.1, R87.1, U23.38 (P1_0)
/mcu/usb/power/SGPIO9: P77.1, R77.1, U23.7 (P4_3)
/mcu/usb/power/SGPIO10: P78.1, R88.1, U23.61 (P1_14)
/mcu/usb/power/SGPIO11: P79.1, R91.1, U23.66 (P1_17)
/mcu/usb/power/SGPIO12: R96.1, U23.67 (P1_18)
/mcu/usb/power/SGPIO13: R78.1, U23.15 (P4_8)
/mcu/usb/power/SGPIO14: R80.1, U23.33 (P4_9)
/mcu/usb/power/SGPIO15: R86.1, U23.35 (P4_10)
/mcu/usb/power/SPIFI_CS: P68.1, U20.1 (CS), U23.124 (P3_8)
/mcu/usb/power/SPIFI_MISO: P22.7, U20.2 (DO), U23.122 (P3_6)
/mcu/usb/power/SPIFI_MOSI: P22.9, U20.5 (DI), U23.123 (P3_7)
/mcu/usb/power/SPIFI_SCK: P22.8, U20.6 (CLK), U23.118 (P3_3)
/mcu/usb/power/SPIFI_SIO2: P81.1, U20.3 (WP), U23.121 (P3_5)
/mcu/usb/power/SPIFI_SIO3: P82.1, U20.7 (HOLD), U23.119 (P3_4)
/mcu/usb/power/TCK: P26.4, R66.2, U23.27 (TCK/SWDCLK)
/mcu/usb/power/TDI: P26.8, U23.26 (TDI)
/mcu/usb/power/TDO: P26.6, R63.1, U23.31 (TDO/SWO)
/mcu/usb/power/TMS: P26.2, U23.30 (TMS/SWDIO)
/mcu/usb/power/U0_RXD: P22.19, P25.4, U23.81 (P2_1)
/mcu/usb/power/U0_TXD: P22.20, P25.5, U23.75 (P2_0)
/mcu/usb/power/VBAT: C136.1, P20.1, U23.127 (VBAT)
/mcu/usb/power/VBUS: J11.A4 (VBUS), J11.A9 (VBUS), J11.B4 (VBUS), J11.B9 (VBUS), L15.1 (VBUS), P20.21, Q5.S, R62.2
/mcu/usb/power/VBUSCTRL: P20.17, Q5.G, R37.2
/mcu/usb/power/VIN: C143.1, C147.1, P20.22, Q5.D, R52.1, U21.3 (VIN)
/mcu/usb/power/VREGMODE: P69.1, R51.2, U23.101 (P6_11)
/mcu/usb/power/WAKEUP: P20.4, R48.2, U23.130 (WAKEUP0)
/mcu/usb/power/XTAL1: C157.1, U23.12 (XTAL1), X2.1
/mcu/usb/power/XTAL2: C158.1, U23.13 (XTAL2), X2.3
AMP_BYPASS: U23.104 (P2_10); also elsewhere on the board
CLK6: P22.25 (P24); also elsewhere on the board
CLKIN: P22.2; also elsewhere on the board
CLKOUT: P22.1; also elsewhere on the board
CS_AD: U23.65 (P5_7); also elsewhere on the board
CS_XCVR: U23.70 (P1_20); also elsewhere on the board
DA0: U24.43 (BANK1F4M8); also elsewhere on the board
DA1: U24.42 (BANK1F4M7); also elsewhere on the board
DA2: U24.41 (BANK1F4M6); also elsewhere on the board
DA3: U24.40 (BANK1F4M5); also elsewhere on the board
DA4: U24.39 (BANK1F4M4); also elsewhere on the board
DA5: U24.37 (BANK1F4M3); also elsewhere on the board
DA6: U24.36 (BANK1F4M2); also elsewhere on the board
DA7: U24.35 (BANK1F4M1); also elsewhere on the board
DD0: U24.34 (BANK1F2M16); also elsewhere on the board
DD1: U24.33 (BANK1F2M15); also elsewhere on the board
DD2: U24.32 (BANK1F2M14); also elsewhere on the board
DD3: U24.30 (BANK1F2M13); also elsewhere on the board
DD4: U24.29 (BANK1F2M12); also elsewhere on the board
DD5: U24.28 (BANK1F2M11); also elsewhere on the board
DD6: U24.24 (BANK1F2M9); also elsewhere on the board
DD7: U24.19 (BANK1F2M6); also elsewhere on the board
DD8: U24.18 (BANK1F2M5); also elsewhere on the board
DD9: U24.17 (BANK1F2M4); also elsewhere on the board
GCK1: P28.14, U24.23 (BANK1F2M8); also elsewhere on the board
GCK2: P28.13, U24.27 (BANK1F2M10); also elsewhere on the board
GND: C118.2, C126.2, C127.2, C128.2, C129.2, C130.2, C131.2, C132.2, C133.2, C134.2, C135.2, C136.2, C137.2, C138.2, C139.2, C140.2, C141.2, C142.2, C143.2, C144.2, C145.1, C146.1, C147.2, C148.2, C149.2, C150.2, C151.2, C152.2, C153.2, C154.2, C156.2, C157.2, C158.2, C164.2, D2.1 (K), D4.1 (K), D5.1 (K), D6.1 (K), D7.1 (K), D8.1 (K), J11.A1 (GND), J11.A12 (GND), J11.B1 (GND), J11.B12 (GND), J11.S1 (SHIELD), L15.5 (GND), L15.8 (GND), P3.1, P3.2 (PM), P5.1, P20.13, P20.15, P20.19, P22.4, P22.10, P22.18, P25.1, P26.3, P26.5, P26.9, P28.2, P28.12, P30.2, P30.20, P80.1, P80.2 (PM), R7.2, R24.2, R29.2, R35.2, R37.1, R46.1, R54.1, R55.1, R65.1, R68.2, R69.2, R93.2, SW1.0 (SHIELD), SW2.0 (SHIELD), SW2.1, U20.4 (GND), U21.0 (PP), U21.8 (GND), U23.4 (VSSIO), U23.19 (USB0_VSSA_TERM), U23.23 (USB0_VSSA_REF), U23.40 (VSSIO), U23.76 (VSSIO), U23.109 (VSSIO), U23.135 (VSSA), U23.138 (ADC0_4/ADC1_4), U24.21 (GND), U24.31 (GND), U24.62 (GND), U24.69 (GND), U24.84 (GND), U24.100 (GND), X2.2, X2.4; also elsewhere on the board
HP: U23.1 (P4_0); also elsewhere on the board
LP: U23.39 (P5_1); also elsewhere on the board
MCU_CLK: R34.2; also elsewhere on the board
MIXER_ENX: U23.57 (P5_4); also elsewhere on the board
MIXER_RESETX: U23.58 (P5_5); also elsewhere on the board
MIXER_SCLK: U23.95 (P2_6); also elsewhere on the board
MIXER_SDATA: U23.80 (P6_4); also elsewhere on the board
MIX_BYPASS: U23.86 (P6_8); also elsewhere on the board
unnamed: D2.2 (A), R18.1
unnamed: D4.2 (A), R72.1
unnamed: D5.2 (A), R73.1
unnamed: D6.2 (A), R74.1
unnamed: D7.2 (A), R75.1
unnamed: D8.2 (A), R76.1
unnamed: J11.A5 (CC1), R24.1
unnamed: J11.B5 (CC2), R29.1
unnamed: J11.A6 (D+), J11.B6 (D+), L15.3 (D+)
unnamed: J11.A7 (D-), J11.B7 (D-), L15.2 (D-)
unnamed: L15.6 (D+), R57.2
unnamed: L15.7 (D-), R58.2
unnamed: R12.2, R45.1
unnamed: R19.2, R49.2, SW2.2
unnamed: R7.1, R30.2, SW1.2
unnamed: C125.2, R46.2, R47.2, U21.1 (ADJ2)
unnamed: R55.2, R56.2, U21.5 (DEF1)
unnamed: R52.2, U21.7 (EN1)
unnamed: R51.1, U21.2 (MODE/DATA)
unnamed: L11.2, U21.6 (SW1)
unnamed: L10.1, U21.10 (SW2)
unnamed: P24.1, U23.29 (TRST)
unnamed: R62.1, R65.2, U23.21 (USB0_VBUS)
RSSI: U23.2 (ADC0_1/ADC1_1); also elsewhere on the board
RX: U23.91 (P2_5); also elsewhere on the board
RXENABLE: U23.10 (P4_5); also elsewhere on the board
RX_AMP: U23.105 (P2_11); also elsewhere on the board
RX_MIX_BP: U23.54 (P5_3); also elsewhere on the board
SCL: P22.26 (P22), U23.92 (I2C0_SCL); also elsewhere on the board
SDA: P22.24 (P20), U23.93 (I2C0_SDA); also elsewhere on the board
SGPIO_CLK: U23.72 (P9_6); also elsewhere on the board
SSP1_MISO: U23.44 (P1_3); also elsewhere on the board
SSP1_MOSI: U23.47 (P1_4); also elsewhere on the board
SSP1_SCK: U23.68 (P1_19); also elsewhere on the board
TX: U23.85 (P6_7)
TXENABLE: U23.9 (P4_4); also elsewhere on the board
TX_AMP: U23.63 (P5_6); also elsewhere on the board
TX_MIX_BP: U23.46 (P5_2); also elsewhere on the board
VAA: R18.2; also elsewhere on the board
VCC: C128.1, C129.1, C130.1, C131.1, C132.1, C133.1, C134.1, C135.1, C137.1, C138.1, C139.1, C140.1, C141.1, C142.1, C144.1, C145.2, C146.2, C148.1, C149.1, C150.1, C153.1, C154.1, L11.1, P5.2, P8.1, P8.2 (PM), P20.3, P22.11, P26.1, P28.1, P30.1, R12.1, R48.1, R49.1, R56.1, R59.1, R63.2, R64.2, R66.1, R67.2, R75.2, SW1.1, U20.8 (VCC), U21.4 (FB1), U23.5 (VDDIO), U23.16 (USB0_VDDA3V3_DRIVER), U23.17 (USB0_VDDA3V3), U23.25 (VDDREG), U23.36 (VDDIO), U23.41 (VDDIO), U23.59 (VDDREG), U23.71 (VDDIO), U23.77 (VDDIO), U23.94 (VDDREG), U23.107 (VDDIO), U23.111 (VDDIO), U23.131 (VDDREG), U23.136 (ADC0_7/ADC1_7), U23.137 (VDDA), U23.141 (VDDIO), U24.5 (VAUX), U24.38 (VCCIO1), U24.51 (VCCIO1), U24.88 (VCCIO2), U24.98 (VCCIO2); also elsewhere on the board
XCVR_EN: U23.11 (P4_6); also elsewhere on the board

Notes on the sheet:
I2S0_TX_SDA/
GND
VCC
U23 starts up on this 12 MHz crystal. This makes it possible to use USB0 DFU boot mode. It should be possible to switch to GP_CLKIN provided by the clock generator IC (MCL_CLK) if desired.
See also I2S0 pins on P20.
Series resistors are here because of a possible overshoot/undershoot problem. They may be able to be removed safely. Anyway, they probably will minimize damage in the event of SGPIO/CPLD misconfiguration.
P2_9
Default boot configuration is SPIFI. Press SW1 during reset to switch to USB0 (DFU mode).
/I2S0_TX_WS
Cortex Debug Connector (10 pin 50 mil)
P1_2
PCB trace jumper
P1_1
USART0
SPIFI
pin straps for hardware version detection. Values shown for version = 15
P2_8
USB0
SSP0
USART3
Boot selection:

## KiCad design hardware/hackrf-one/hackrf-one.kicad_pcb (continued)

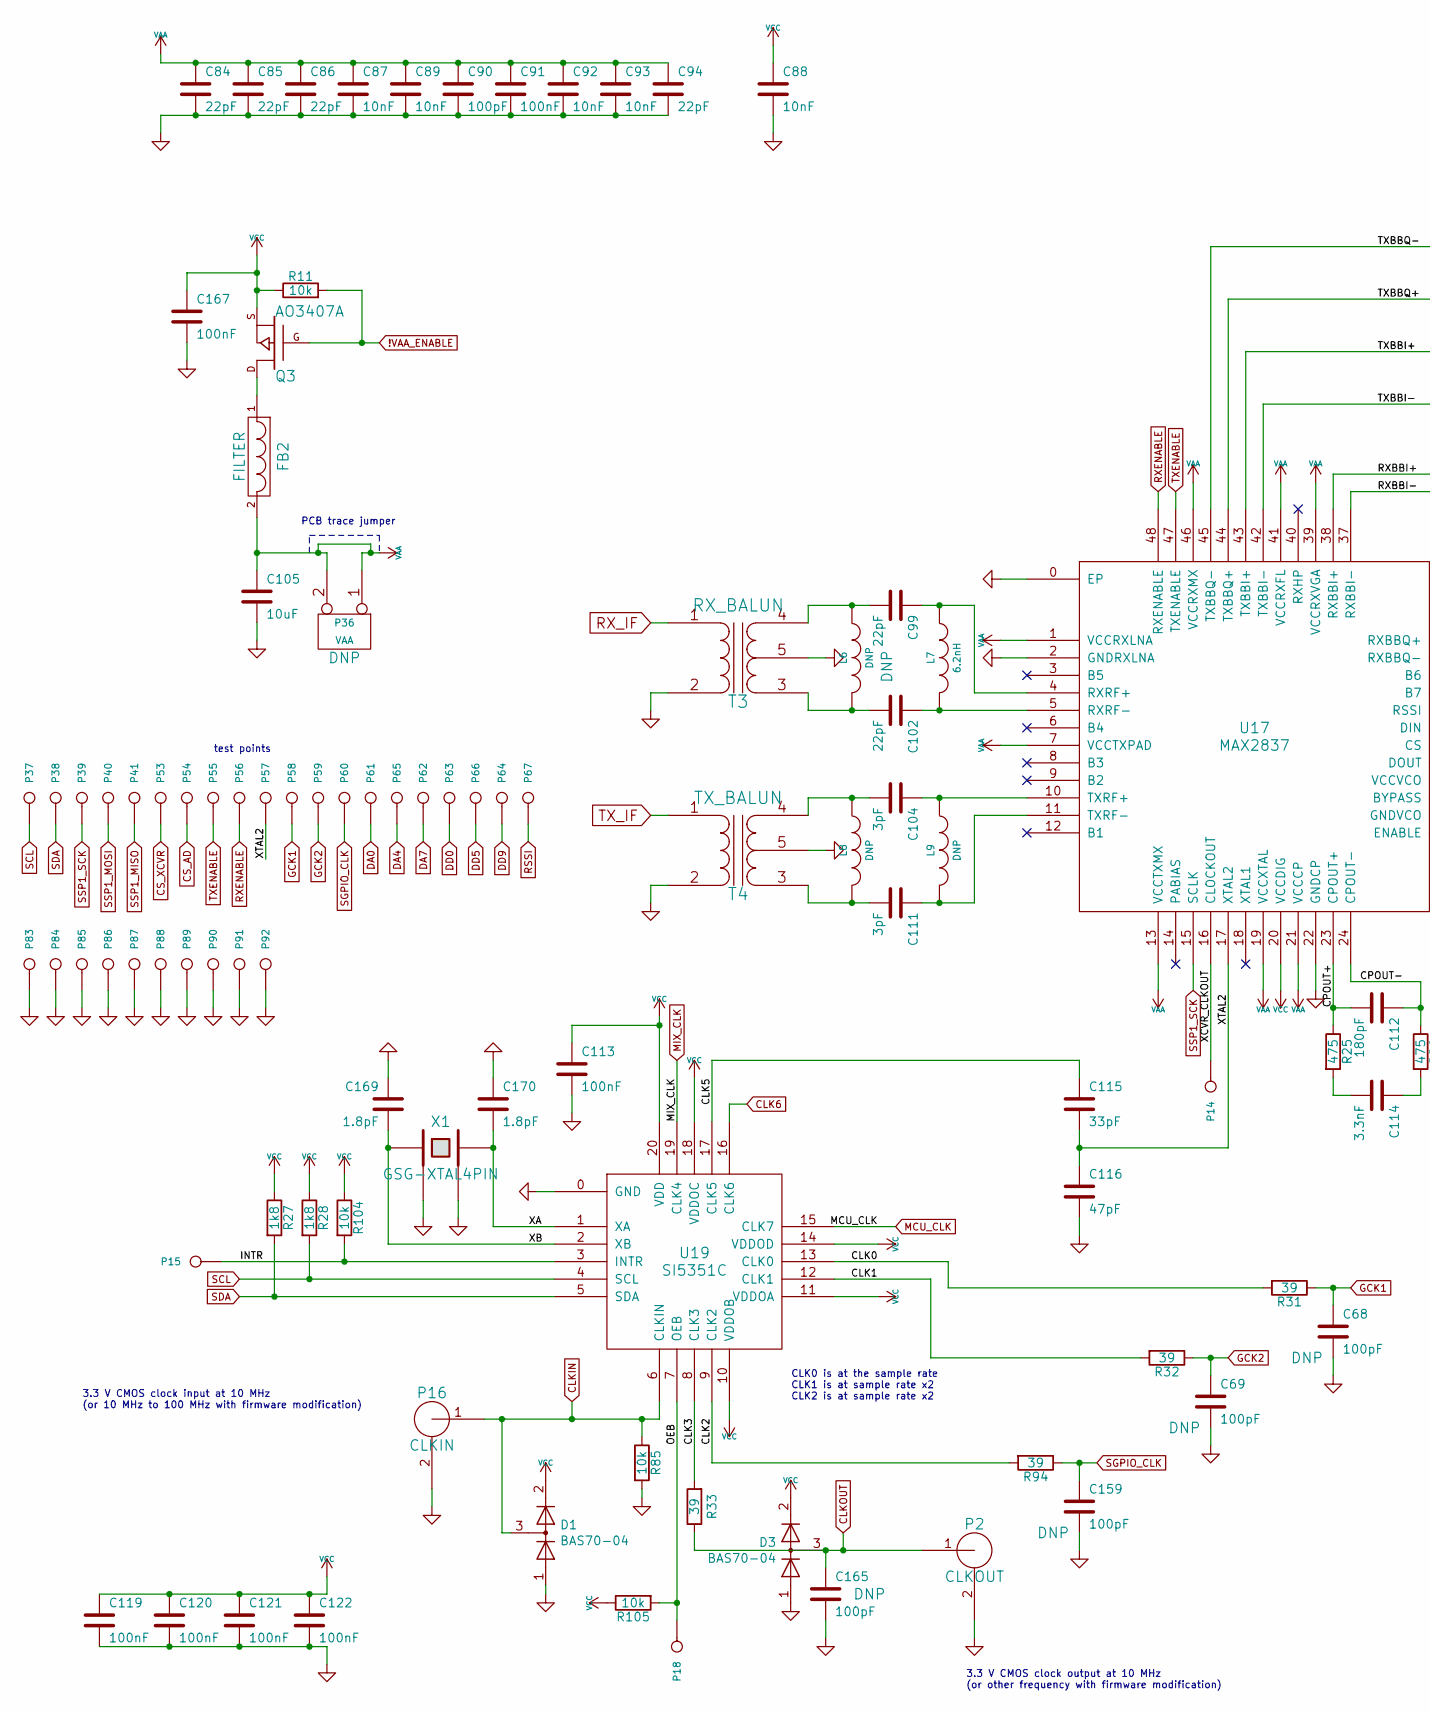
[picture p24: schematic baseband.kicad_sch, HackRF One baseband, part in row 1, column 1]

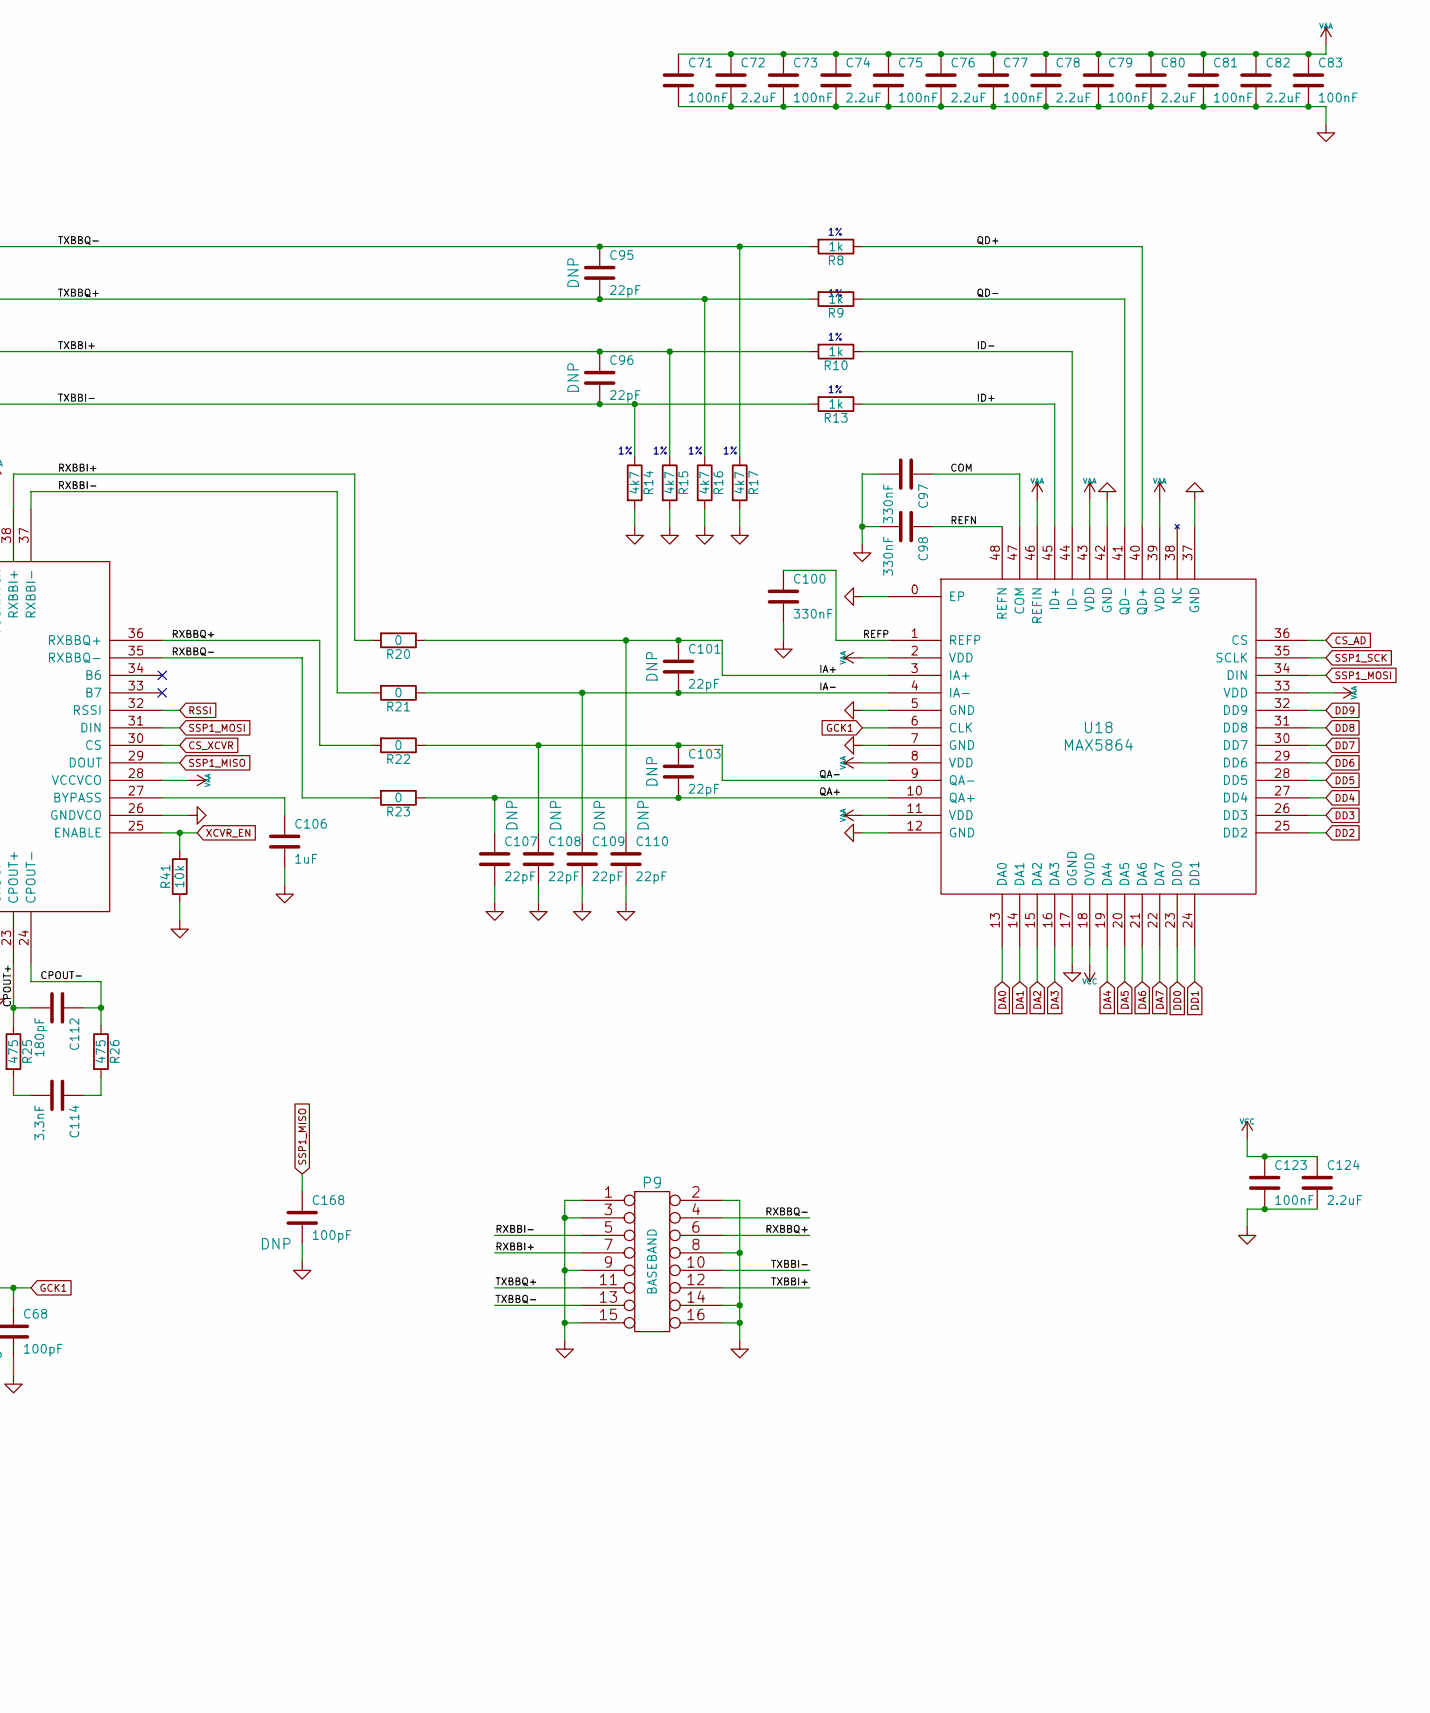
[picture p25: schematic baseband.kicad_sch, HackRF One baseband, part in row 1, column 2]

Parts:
C68, C69, C90, C159, C165, C168: 100pF; GSG-0402; Part Number GRM1555C1H101JA01D
C71, C73, C75, C77, C79, C81, C83, C91, C113, C119, C120, C121, C122, C123, C167: 100nF; GSG-0402; Part Number GRM155R61A104KA01D
C72, C74, C76, C78, C80, C82, C124: 2.2uF; GSG-0402; Part Number LMK105BJ225MV-F
C84, C85, C86, C94, C95, C96, C99, C101, C102, C103, C107, C108, C109, C110: 22pF; GSG-0402; Part Number GRM1555C1H220JA01D
C87, C88, C89, C92, C93: 10nF; GSG-0402; Part Number GRM155R71C103KA01D
C97, C98, C100: 330nF; GSG-0402; Part Number GRM155R61A334KE15D
C104, C111: 3pF; GSG-0402; Part Number GRM1555C1H3R0CA01D
C105: 10uF; GSG-0805; Part Number GRM21BR61A106KE19L
C106: 1uF; GSG-0402; Part Number LMK105BJ105KV-F
C112: 180pF; GSG-0402; Part Number GRM1555C1H181JA01D
C114: 3.3nF; GSG-0402; Part Number GRM155R71H332KA01D
C115: 33pF; GSG-0402; Part Number GRM1555C1H330JA01D
C116: 47pF; GSG-0402; Part Number GRM1555C1H470JA01D
C169, C170: 1.8pF; GSG-0402; Part Number GRM1555C1E1R8BA01D
D1, D3: BAS70-04; SOT-23
FB2: FILTER; GSG-0805; Part Number BLM21PG221SN1D
L6, L8, L9: DNP; GSG-0402
L7: 6.2nH; GSG-0402; Part Number HK10056N2S-T
P2: CLKOUT; SMA-73251-2120; Part Number 73251-2121
P9: BASEBAND; GSG-HEADER-2x8; Part Number PPPC082LFBN-RC
P14: XCVR_CLKOUT; GSG-TESTPOINT-50MIL
P15: INTR; GSG-TESTPOINT-50MIL
P16: CLKIN; SMA-73251-2120; Part Number 73251-2121
P18: OEB; GSG-TESTPOINT-50MIL
P36: VAA; GSG-HEADER-1x2
P37: SCL; GSG-TESTPOINT-50MIL
P38: SDA; GSG-TESTPOINT-50MIL
P39: SSP1_SCK; GSG-TESTPOINT-50MIL
P40: SSP1_MOSI; GSG-TESTPOINT-50MIL
P41: SSP1_MISO; GSG-TESTPOINT-50MIL
P53: CS_XCVR; GSG-TESTPOINT-50MIL
P54: CS_AD; GSG-TESTPOINT-50MIL
P55: TXENABLE; GSG-TESTPOINT-50MIL
P56: RXENABLE; GSG-TESTPOINT-50MIL
P57: XTAL2; GSG-TESTPOINT-50MIL
P58: GCK1; GSG-TESTPOINT-50MIL
P59: GCK2; GSG-TESTPOINT-50MIL
P60: SGPIO_CLK; GSG-TESTPOINT-50MIL
P61: DA0; GSG-TESTPOINT-50MIL
P62: DA7; GSG-TESTPOINT-50MIL
P63: DD0; GSG-TESTPOINT-50MIL
P64: DD9; GSG-TESTPOINT-50MIL
P65: DA4; GSG-TESTPOINT-50MIL
P66: DD5; GSG-TESTPOINT-50MIL
P67: RSSI; GSG-TESTPOINT-50MIL
P83, P84, P85, P86, P87, P88, P89, P90, P91, P92: GND; GSG-TESTPOINT-50MIL
Q3: AO3407A; SOT23GDS; Part Number AO3407A
R8, R9, R10, R13: 1k; GSG-0402; Part Number RMCF0402FT1K00
R11, R41, R85, R104, R105: 10k; GSG-0402; Part Number RMCF0402JT10K0
R14, R15, R16, R17: 4k7; GSG-0402; Part Number RMCF0402FT4K70
R20, R21, R22, R23: 0; GSG-0402; Part Number RMCF0402ZT0R00
R25, R26: 475; GSG-0402; Part Number RMCF0402JT470R
R27, R28: 1k8; GSG-0402; Part Number RMCF0402JT1K80
R31, R32, R33, R94: 39; GSG-0402; Part Number RMCF0402JT39R0
T3: RX_BALUN; GSG-2500BL14M100; Part Number 2500BL14M100T
T4: TX_BALUN; GSG-2500BL14M100; Part Number 2500BL14M100T
U17: MAX2837; GSG-QFN48-6; Part Number MAX2837ETM+
U18: MAX5864; GSG-QFN48-7; Part Number MAX5864ETM+
U19: SI5351C; GSG-QFN20-4; Part Number SI5351C-B-GM
X1: GSG-XTAL4PIN; GSG-XTAL3.2x2.5mm; Part Number ABM8-25.000MHZ-10-D1G-T

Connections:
!VAA_ENABLE: Q3.G, R11.2; also elsewhere on the board
/baseband/CLK0: R31.2, U19.13 (CLK0)
/baseband/CLK1: R32.2, U19.12 (CLK1)
/baseband/CLK2: R94.2, U19.9 (CLK2)
/baseband/CLK3: R33.2, U19.8 (CLK3)
/baseband/CLK5: C115.1, U19.17 (CLK5)
/baseband/COM: C97.1, U18.47 (COM)
/baseband/CPOUT+: C112.2, R25.1, U17.23 (CPOUT+)
/baseband/CPOUT-: C112.1, R26.1, U17.24 (CPOUT-)
/baseband/IA+: C101.1, C110.1, R20.1, U18.3 (IA+)
/baseband/IA-: C101.2, C109.1, R21.1, U18.4 (IA-)
/baseband/ID+: R13.1, U18.45 (ID+)
/baseband/ID-: R10.1, U18.44 (ID-)
/baseband/INTR: P15.1, R104.2, U19.3 (INTR)
/baseband/OEB: P18.1, R105.2, U19.7 (OEB)
/baseband/QA+: C103.2, C107.1, R23.1, U18.10 (QA+)
/baseband/QA-: C103.1, C108.1, R22.1, U18.9 (QA-)
/baseband/QD+: R8.1, U18.40 (QD+)
/baseband/QD-: R9.1, U18.41 (QD-)
/baseband/REFN: C98.1, U18.48 (REFN)
/baseband/REFP: C100.1, U18.1 (REFP)
/baseband/RXBBI+: P9.7, R20.2, U17.38 (RXBBI+)
/baseband/RXBBI-: P9.5, R21.2, U17.37 (RXBBI-)
/baseband/RXBBQ+: P9.6, R22.2, U17.36 (RXBBQ+)
/baseband/RXBBQ-: P9.4, R23.2, U17.35 (RXBBQ-)
/baseband/TXBBI+: C96.1, P9.12, R10.2, R15.1, U17.43 (TXBBI+)
/baseband/TXBBI-: C96.2, P9.10, R13.2, R14.1, U17.42 (TXBBI-)
/baseband/TXBBQ+: C95.2, P9.11, R9.2, R16.1, U17.44 (TXBBQ+)
/baseband/TXBBQ-: C95.1, P9.13, R8.2, R17.1, U17.45 (TXBBQ-)
/baseband/XA: C170.2, U19.1 (XA), X1.3
/baseband/XB: C169.2, U19.2 (XB), X1.1
/baseband/XCVR_CLKOUT: P14.1, U17.16 (CLOCKOUT)
/baseband/XTAL2: C115.2, C116.1, P57.1, U17.17 (XTAL2)
CLK6: U19.16 (CLK6); also elsewhere on the board
CLKIN: D1.3 (K), P16.1 (RF), R85.1, U19.6 (CLKIN); also elsewhere on the board
CLKOUT: C165.1, D3.3 (K), P2.1 (RF), R33.1; also elsewhere on the board
CS_AD: P54.1, U18.36 (CS); also elsewhere on the board
CS_XCVR: P53.1, U17.30 (CS); also elsewhere on the board
DA0: P61.1, U18.13 (DA0); also elsewhere on the board
DA1: U18.14 (DA1); also elsewhere on the board
DA2: U18.15 (DA2); also elsewhere on the board
DA3: U18.16 (DA3); also elsewhere on the board
DA4: P65.1, U18.19 (DA4); also elsewhere on the board
DA5: U18.20 (DA5); also elsewhere on the board
DA6: U18.21 (DA6); also elsewhere on the board
DA7: P62.1, U18.22 (DA7); also elsewhere on the board
DD0: P63.1, U18.23 (DD0); also elsewhere on the board
DD1: U18.24 (DD1); also elsewhere on the board
DD2: U18.25 (DD2); also elsewhere on the board
DD3: U18.26 (DD3); also elsewhere on the board
DD4: U18.27 (DD4); also elsewhere on the board
DD5: P66.1, U18.28 (DD5); also elsewhere on the board
DD6: U18.29 (DD6); also elsewhere on the board
DD7: U18.30 (DD7); also elsewhere on the board
DD8: U18.31 (DD8); also elsewhere on the board
DD9: P64.1, U18.32 (DD9); also elsewhere on the board
GCK1: C68.1, P58.1, R31.1, U18.6 (CLK); also elsewhere on the board
GCK2: C69.1, P59.1, R32.1; also elsewhere on the board
GND: C68.2, C69.2, C71.2, C72.2, C73.2, C74.2, C75.2, C76.2, C77.2, C78.2, C79.2, C80.2, C81.2, C82.2, C83.2, C84.2, C85.2, C86.2, C87.2, C88.2, C89.2, C90.2, C91.2, C92.2, C93.2, C94.2, C97.2, C98.2, C100.2, C105.2, C106.2, C107.2, C108.2, C109.2, C110.2, C113.2, C116.2, C119.2, C120.2, C121.2, C122.2, C123.2, C124.2, C159.2, C165.2, C167.2, C168.2, C169.1, C170.1, D1.1 (K), D3.1 (K), P2.2 (GND), P9.1, P9.2, P9.3, P9.8, P9.9, P9.14, P9.15, P9.16, P16.2 (GND), P83.1, P84.1, P85.1, P86.1, P87.1, P88.1, P89.1, P90.1, P91.1, P92.1, R14.2, R15.2, R16.2, R17.2, R41.1, R85.2, T3.2 (S2), T3.5 (PM), T4.2 (S2), T4.5 (PM), U17.0 (EP), U17.2 (GNDRXLNA), U17.22 (GNDCP), U17.26 (GNDVCO), U18.0 (EP), U18.5 (GND), U18.7 (GND), U18.12 (GND), U18.17 (OGND), U18.37 (GND), U18.42 (GND), U19.0 (GND), X1.2, X1.4; also elsewhere on the board
MCU_CLK: U19.15 (CLK7); also elsewhere on the board
MIX_CLK: U19.19 (CLK4); also elsewhere on the board
unnamed: C114.1, R26.2
unnamed: C114.2, R25.2
unnamed: FB2.1, Q3.D
unnamed: C102.2, L6.2, T3.3 (PR1)
unnamed: C99.2, L6.1, T3.4 (PR2)
unnamed: C111.2, L8.2, T4.3 (PR1)
unnamed: C104.2, L8.1, T4.4 (PR2)
unnamed: C106.1, U17.27 (BYPASS)
unnamed: C99.1, L7.1, U17.4 (RXRF+)
unnamed: C102.1, L7.2, U17.5 (RXRF-)
unnamed: C104.1, L9.1, U17.10 (TXRF+)
unnamed: C111.1, L9.2, U17.11 (TXRF-)
RSSI: P67.1, U17.32 (RSSI); also elsewhere on the board
RXENABLE: P56.1, U17.48 (RXENABLE); also elsewhere on the board
RX_IF: T3.1 (S1); also elsewhere on the board
SCL: P37.1, R28.2, U19.4 (SCL); also elsewhere on the board
SDA: P38.1, R27.2, U19.5 (SDA); also elsewhere on the board
SGPIO_CLK: C159.1, P60.1, R94.1; also elsewhere on the board
SSP1_MISO: C168.1, P41.1, U17.29 (DOUT); also elsewhere on the board
SSP1_MOSI: P40.1, U17.31 (DIN), U18.34 (DIN); also elsewhere on the board
SSP1_SCK: P39.1, U17.15 (SCLK), U18.35 (SCLK); also elsewhere on the board
TXENABLE: P55.1, U17.47 (TXENABLE); also elsewhere on the board
TX_IF: T4.1 (S1); also elsewhere on the board
VAA: C71.1, C72.1, C73.1, C74.1, C75.1, C76.1, C77.1, C78.1, C79.1, C80.1, C81.1, C82.1, C83.1, C84.1, C85.1, C86.1, C87.1, C89.1, C90.1, C91.1, C92.1, C93.1, C94.1, C105.1, FB2.2, P36.1, P36.2 (PM), U17.1 (VCCRXLNA), U17.7 (VCCTXPAD), U17.13 (VCCTXMX), U17.19 (VCCXTAL), U17.21 (VCCCP), U17.28 (VCCVCO), U17.39 (VCCRXVGA), U17.41 (VCCRXFL), U17.46 (VCCRXMX), U18.2 (VDD), U18.8 (VDD), U18.11 (VDD), U18.33 (VDD), U18.39 (VDD), U18.43 (VDD), U18.46 (REFIN); also elsewhere on the board
VCC: C88.1, C113.1, C119.1, C120.1, C121.1, C122.1, C123.1, C124.1, C167.1, D1.2 (A), D3.2 (A), Q3.S, R11.1, R27.1, R28.1, R104.1, R105.1, U17.20 (VCCDIG), U18.18 (OVDD), U19.10 (VDDOB), U19.11 (VDDOA), U19.14 (VDDOD), U19.18 (VDDOC), U19.20 (VDD); also elsewhere on the board
XCVR_EN: R41.2, U17.25 (ENABLE); also elsewhere on the board

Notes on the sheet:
test points
3.3 V CMOS clock input at 10 MHz (or 10 MHz to 100 MHz with firmware modification)
3.3 V CMOS clock output at 10 MHz (or other frequency with firmware modification)
PCB trace jumper
CLK0 is at the sample rate CLK1 is at sample rate x2 CLK2 is at sample rate x2

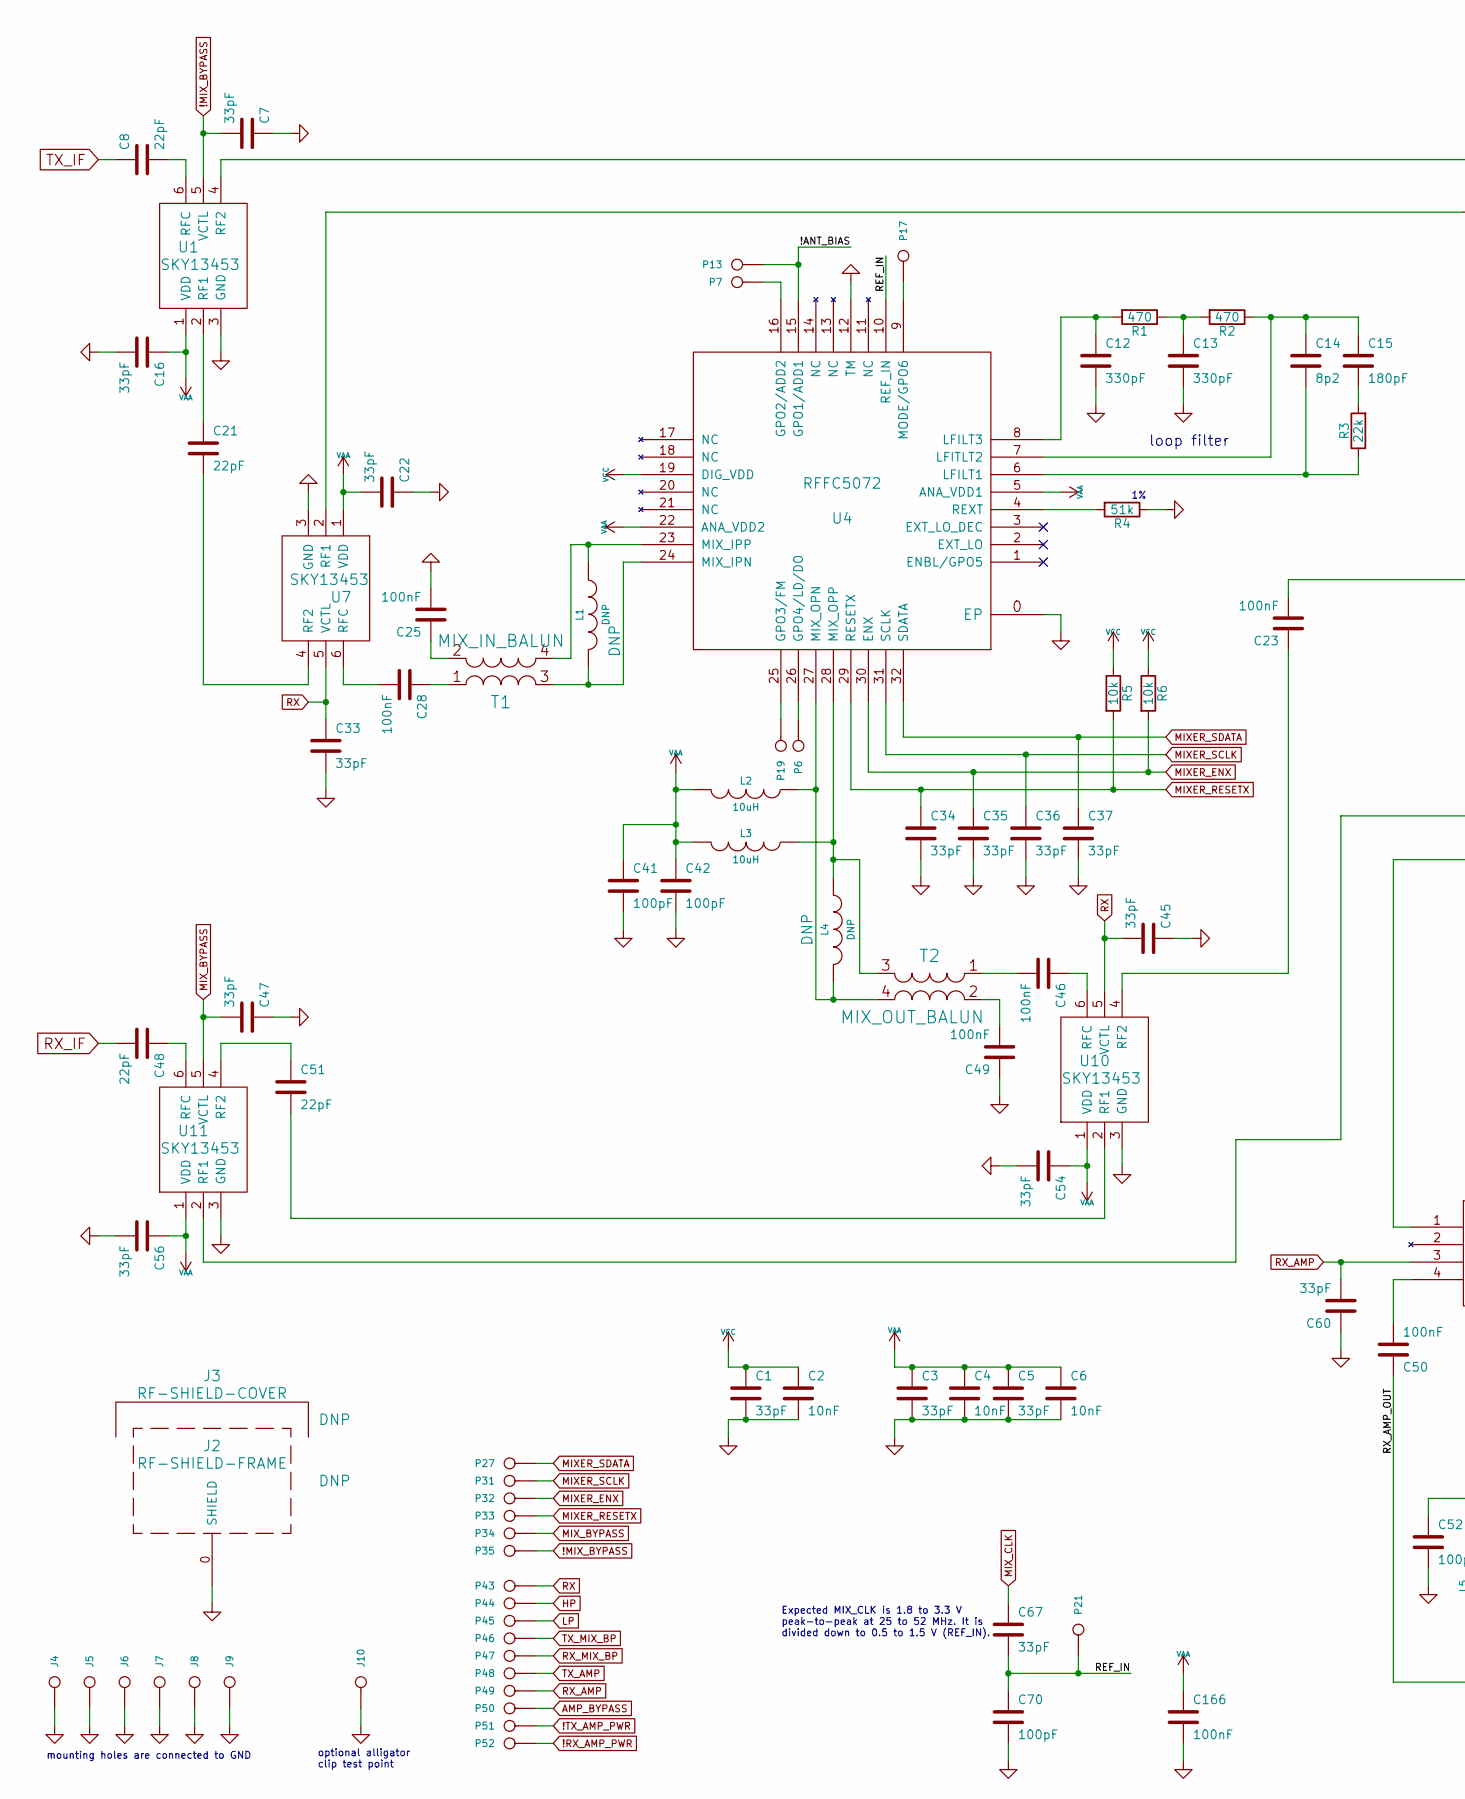
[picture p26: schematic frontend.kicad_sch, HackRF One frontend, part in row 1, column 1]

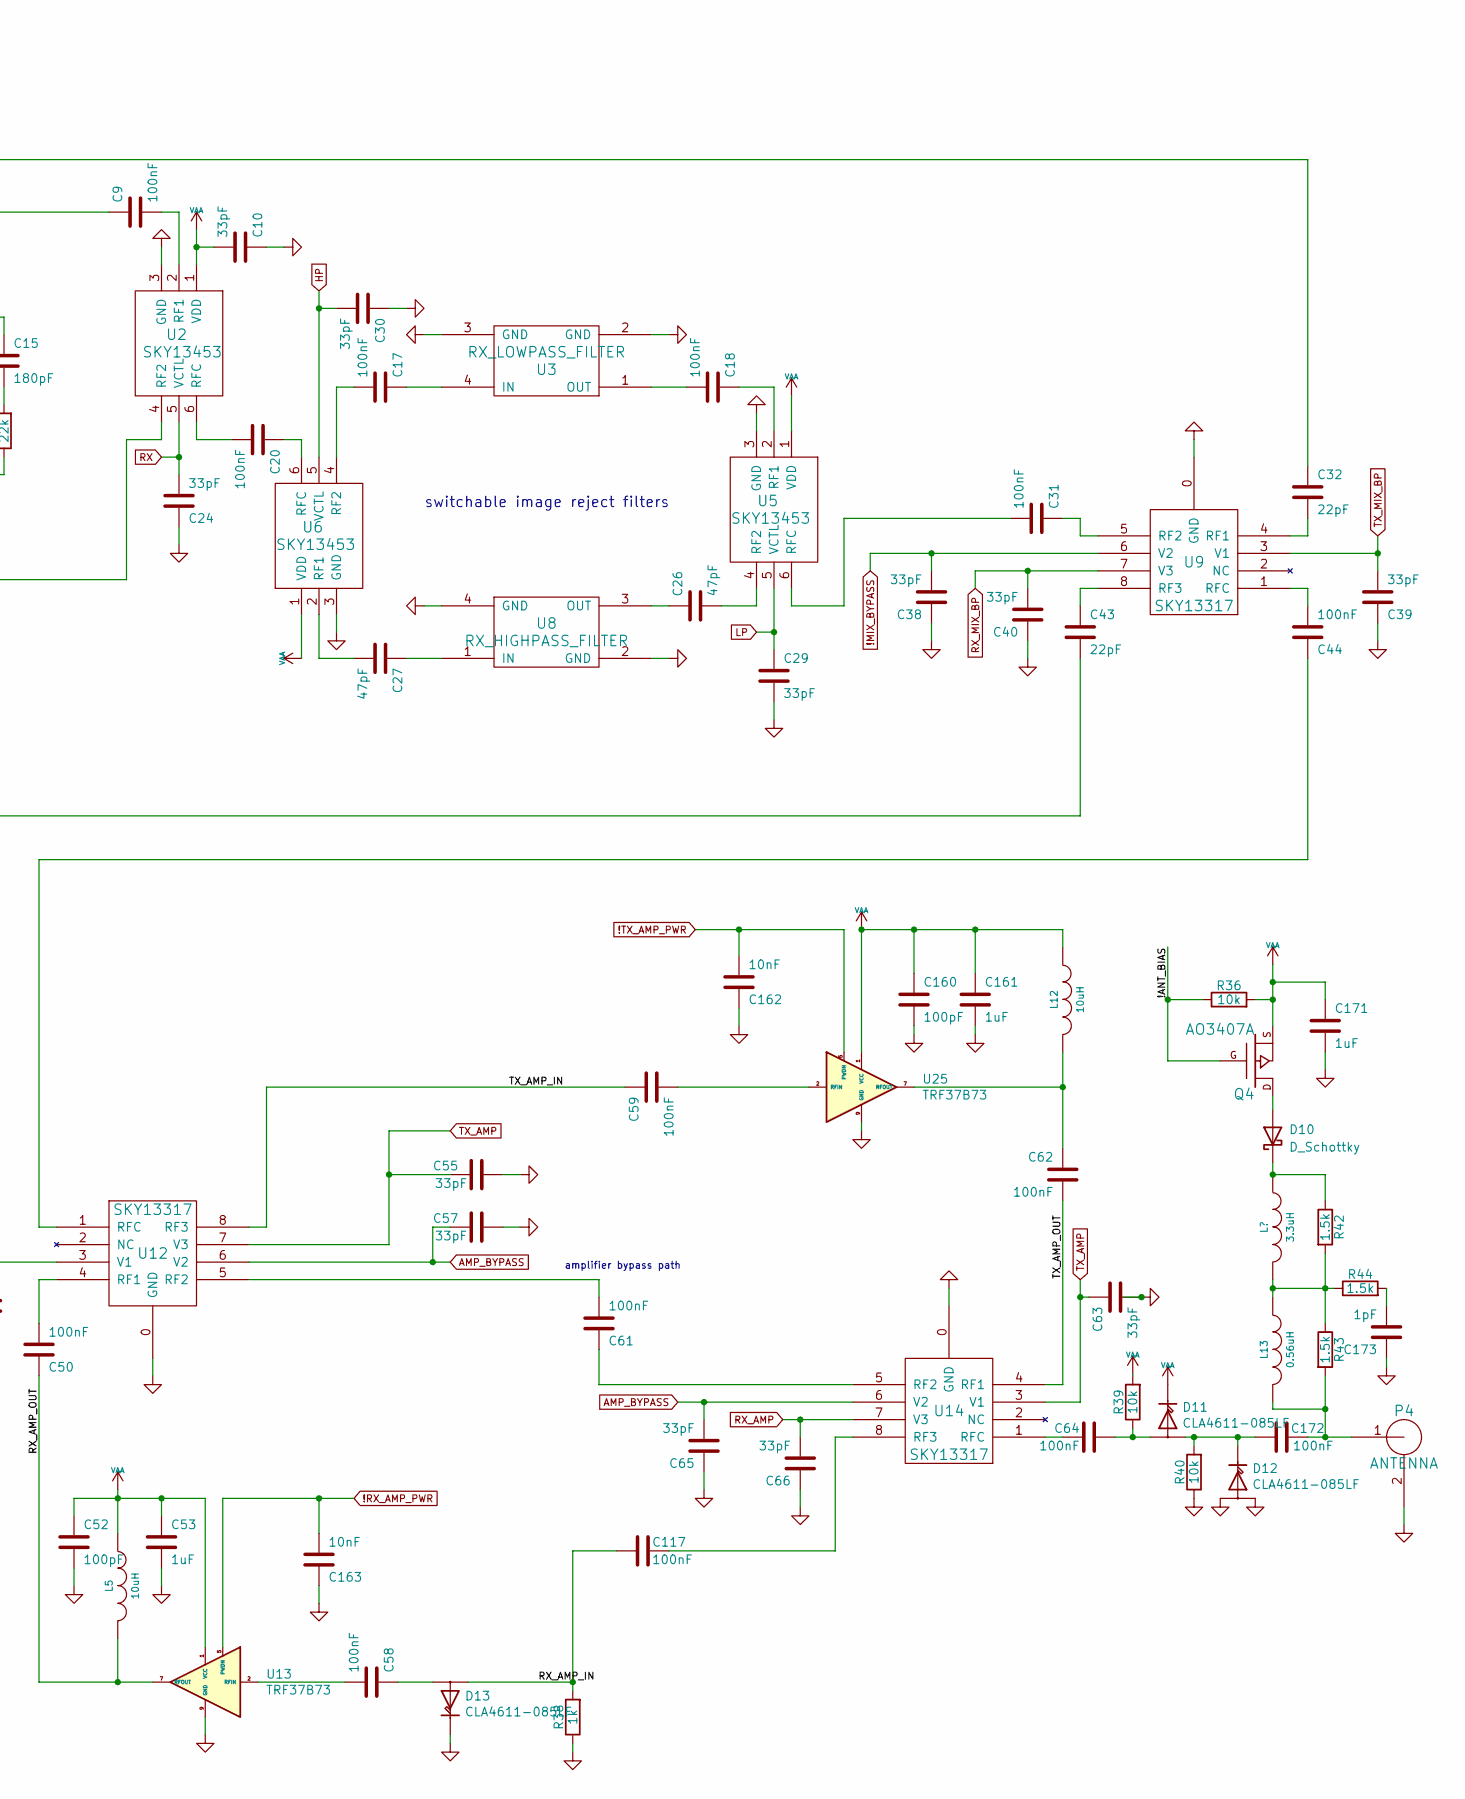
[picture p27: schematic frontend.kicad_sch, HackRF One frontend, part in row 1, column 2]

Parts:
C1, C3, C5, C7, C10, C16, C22, C24, C29, C30, C33, C34, C35, C36, C37, C38, C39, C40, C45, C47, C54, C55, C56, C57, C60, C63, C65, C66, C67: 33pF; GSG-0402; Part Number GRM1555C1H330JA01D
C2, C4, C6, C162, C163: 10nF; GSG-0402; Part Number GRM155R71C103KA01D
C8, C21, C32, C43, C48, C51: 22pF; GSG-0402; Part Number GRM1555C1H220JA01D
C9, C17, C18, C20, C23, C25, C28, C31, C44, C46, C49, C50, C58, C59, C61, C62, C64, C117, C166, C172: 100nF; GSG-0402; Part Number GRM155R61A104KA01D
C12, C13: 330pF; GSG-0402; Part Number GRM155R71H331KA01D
C14: 8p2; GSG-0402; Part Number UMK105CG8R2DV-F
C15: 180pF; GSG-0402; Part Number GRM1555C1H181JA01D
C26, C27: 47pF; GSG-0402; Part Number GRM1555C1H470JA01D
C41, C42, C52, C70, C160: 100pF; GSG-0402; Part Number GRM1555C1H101JA01D
C53, C161, C171: 1uF; GSG-0402; Part Number LMK105BJ105KV-F
C173: 1pF; GSG-0402; Part Number GJM1555C1H1R0JB01
D10: D_Schottky; DSN1006-2; Part Number PMEG4010ESBYL
D11, D12, D13: CLA4611-085LF; SkyworksLimiterDiode; Part Number CLA4611-085LF
J2: RF-SHIELD-FRAME; GSG-SHIELD-BMI-S-230; Part Number BMI-S-230-F-R
J3: RF-SHIELD-COVER; GSG-NULL-MODULE; Part Number BMI-S-230-C
J4, J5, J6, J7, J8, J9: MOUNTING_HOLE; GSG-HOLE126MIL-COPPER
J10: GND_CLIP; GSG-TEST-POINT-S1751-46R; Part Number S1751-46R
L1, L4: DNP; GSG-0402
L2, L3, L5, L12: 10uH; GSG-0603; Part Number BRL1608T100M
L13: 0.56uH; GSG-0603; Part Number SDWL1608CR56JSTF
L14: 3.3uH; GSG-0603; Part Number BRL1608T3R3M
P4: ANTENNA; SMA-73251-2120; Part Number 73251-2121
P6: GPO4; GSG-TESTPOINT-50MIL
P7: GPO2; GSG-TESTPOINT-50MIL
P13: GPO1; GSG-TESTPOINT-50MIL
P17: GPO6; GSG-TESTPOINT-50MIL
P19: GPO3; GSG-TESTPOINT-50MIL
P21: REF_IN; GSG-TESTPOINT-50MIL
P27: MIXER_SDATA; GSG-TESTPOINT-50MIL
P31: MIXER_SCLK; GSG-TESTPOINT-50MIL
P32: MIXER_ENX; GSG-TESTPOINT-50MIL
P33: MIXER_RESETX; GSG-TESTPOINT-50MIL
P34: MIX_BYPASS; GSG-TESTPOINT-50MIL
P35: !MIX_BYPASS; GSG-TESTPOINT-50MIL
P43: RX; GSG-TESTPOINT-50MIL
P44: HP; GSG-TESTPOINT-50MIL
P45: LP; GSG-TESTPOINT-50MIL
P46: TX_MIX_BP; GSG-TESTPOINT-50MIL
P47: RX_MIX_BP; GSG-TESTPOINT-50MIL
P48: TX_AMP; GSG-TESTPOINT-50MIL
P49: RX_AMP; GSG-TESTPOINT-50MIL
P50: AMP_BYPASS; GSG-TESTPOINT-50MIL
P51: !TX_AMP_PWR; GSG-TESTPOINT-50MIL
P52: !RX_AMP_PWR; GSG-TESTPOINT-50MIL
Q4: AO3407A; SOT23GDS; Part Number AO3407A
R1, R2: 470; GSG-0402; Part Number RMCF0402JT470R
R3: 22k; GSG-0402; Part Number ERJ-2GEJ223X
R4: 51k; GSG-0402; Part Number RMCF0402FT51K0
R5, R6, R36, R39, R40: 10k; GSG-0402; Part Number RMCF0402JT10K0
R38: 1k; GSG-0402; Part Number RMCF0402JT10K0
R42, R43, R44: 1.5k; GSG-0402; Part Number ERJ-2GEJ152X
T1: MIX_IN_BALUN; GSG-B0310J50100AHF; Part Number B0310J50100AHF
T2: MIX_OUT_BALUN; GSG-B0310J50100AHF; Part Number B0310J50100AHF
U1, U2, U5, U6, U7, U10, U11: SKY13453; SKY13453-385LF
U3: RX_LOWPASS_FILTER; GSG-LP0603; Part Number LP0603A1880ANTR
U4: RFFC5072; GSG-QFN32; Part Number RFFC5072TR7
U8: RX_HIGHPASS_FILTER; GSG-HP-DEA; Part Number DEA162400HT-8004B1
U9, U12, U14: SKY13317; GSG-SKY13317-373LF; Part Number SKY13317-373LF
U13, U25: TRF37B73; WSON-8-1EP_2x2mm_P0.5mm_EP0.9x1.6mm

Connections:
!MIX_BYPASS: C7.2, C38.2, P35.1, U1.5 (VCTL), U9.6 (V2); also elsewhere on the board
!RX_AMP_PWR: C163.2, P52.1, U13.5 (PWDN); also elsewhere on the board
!TX_AMP_PWR: C162.2, P51.1, U25.5 (PWDN); also elsewhere on the board
/frontend/!ANT_BIAS: P13.1, Q4.G, R36.1, U4.15 (GPO1/ADD1)
/frontend/REF_IN: C67.2, C70.1, P21.1, U4.10 (REF_IN)
/frontend/RX_AMP_IN: C117.2, D13.1 (A1), R38.2
/frontend/RX_AMP_OUT: C50.1, L5.2, U13.7 (RFOUT)
/frontend/TX_AMP_IN: C59.1, U12.8 (RF3)
/frontend/TX_AMP_OUT: C62.2, U14.4 (RF1)
AMP_BYPASS: C57.1, C65.2, P50.1, U12.6 (V2), U14.6 (V2); also elsewhere on the board
GND: C1.2, C2.2, C3.2, C4.2, C5.2, C6.2, C7.1, C10.1, C12.2, C13.2, C16.2, C22.1, C24.1, C25.2, C29.2, C30.1, C33.2, C34.2, C35.2, C36.2, C37.2, C38.1, C39.1, C40.1, C41.2, C42.2, C45.1, C47.1, C49.1, C52.2, C53.2, C54.2, C55.2, C56.2, C57.2, C60.1, C63.2, C65.1, C66.1, C70.2, C160.2, C161.2, C162.1, C163.1, C166.2, C171.2, C173.1, D12.1 (A1), D12.3 (A2), D13.2 (K), J2.0 (SHIELD), J4.1, J5.1, J6.1, J7.1, J8.1, J9.1, J10.1, P4.2 (GND), R4.1, R38.1, R40.1, U1.3 (GND), U2.3 (GND), U3.2 (GND), U3.3 (GND), U4.0 (EP), U4.12 (TM), U5.3 (GND), U6.3 (GND), U7.3 (GND), U8.2 (GND), U8.4 (GND), U9.0 (GND), U10.3 (GND), U11.3 (GND), U12.0 (GND), U13.9 (GND), U14.0 (GND), U25.9 (GND); also elsewhere on the board
HP: C30.2, P44.1, U6.5 (VCTL); also elsewhere on the board
LP: C29.1, P45.1, U5.5 (VCTL); also elsewhere on the board
MIXER_ENX: C35.1, P32.1, R6.2, U4.30 (ENX); also elsewhere on the board
MIXER_RESETX: C34.1, P33.1, R5.2, U4.29 (RESETX); also elsewhere on the board
MIXER_SCLK: C36.1, P31.1, U4.31 (SCLK); also elsewhere on the board
MIXER_SDATA: C37.1, P27.1, U4.32 (SDATA); also elsewhere on the board
MIX_BYPASS: C47.2, P34.1, U11.5 (VCTL); also elsewhere on the board
MIX_CLK: C67.1; also elsewhere on the board
unnamed: C13.1, R1.1, R2.2
unnamed: C15.2, R3.2
unnamed: C173.2, R44.2
unnamed: D10.2 (A), Q4.D
unnamed: D10.1 (K), L14.1, R42.1
unnamed: C64.2, D11.1 (A1), R39.1
unnamed: C172.1, D11.3 (A2), D12.2 (K), R40.2
unnamed: C58.1, D13.3 (A2)
unnamed: L13.1, L14.2, R42.2, R43.1, R44.1
unnamed: C172.2, L13.2, P4.1 (RF), R43.2
unnamed: L1.2, T1.3 (PR1), U4.24 (MIX_IPN)
unnamed: L1.1, T1.4 (PR2), U4.23 (MIX_IPP)
unnamed: C28.1, T1.1 (S1)
unnamed: C25.1, T1.2 (S2)
unnamed: L3.1, L4.1, T2.3 (PR1), U4.28 (MIX_OPP)
unnamed: L2.1, L4.2, T2.4 (PR2), U4.27 (MIX_OPN)
unnamed: C46.2, T2.1 (S1)
unnamed: C49.2, T2.2 (S2)
unnamed: C21.1, U1.2 (RF1)
unnamed: C32.1, U1.4 (RF2)
unnamed: C8.2, U1.6 (RFC)
unnamed: C9.2, U2.2 (RF1)
unnamed: C23.2, U2.4 (RF2)
unnamed: C20.2, U2.6 (RFC)
unnamed: C17.1, U3.4 (IN)
unnamed: C18.2, U3.1 (OUT)
unnamed: P7.1, U4.16 (GPO2/ADD2)
unnamed: P19.1, U4.25 (GPO3/FM)
unnamed: P6.1, U4.26 (GPO4/LD/DO)
unnamed: C14.2, R3.1, U4.6 (LFILT1)
unnamed: C12.1, R1.2, U4.8 (LFILT3)
unnamed: C14.1, C15.1, R2.1, U4.7 (LFITLT2)
unnamed: P17.1, U4.9 (MODE/GPO6)
unnamed: R4.2, U4.4 (REXT)
unnamed: C18.1, U5.2 (RF1)
unnamed: C26.2, U5.4 (RF2)
unnamed: C31.2, U5.6 (RFC)
unnamed: C27.2, U6.2 (RF1)
unnamed: C17.2, U6.4 (RF2)
unnamed: C20.1, U6.6 (RFC)
unnamed: C9.1, U7.2 (RF1)
unnamed: C21.2, U7.4 (RF2)
unnamed: C28.2, U7.6 (RFC)
unnamed: C27.1, U8.1 (IN)
unnamed: C26.1, U8.3 (OUT)
unnamed: C32.2, U9.4 (RF1)
unnamed: C31.1, U9.5 (RF2)
unnamed: C43.1, U9.8 (RF3)
unnamed: C44.2, U9.1 (RFC)
unnamed: C51.2, U10.2 (RF1)
unnamed: C23.1, U10.4 (RF2)
unnamed: C46.1, U10.6 (RFC)
unnamed: C43.2, U11.2 (RF1)
unnamed: C51.1, U11.4 (RF2)
unnamed: C48.1, U11.6 (RFC)
unnamed: C50.2, U12.4 (RF1)
unnamed: C61.2, U12.5 (RF2)
unnamed: C44.1, U12.1 (RFC)
unnamed: C58.2, U13.2 (RFIN)
unnamed: C61.1, U14.5 (RF2)
unnamed: C117.1, U14.8 (RF3)
unnamed: C64.1, U14.1 (RFC)
unnamed: C59.2, U25.2 (RFIN)
unnamed: C62.1, L12.2, U25.7 (RFOUT)
RX: C24.2, C33.1, C45.2, P43.1, U2.5 (VCTL), U7.5 (VCTL), U10.5 (VCTL); also elsewhere on the board
RX_AMP: C60.2, C66.2, P49.1, U12.3 (V1), U14.7 (V3); also elsewhere on the board
RX_IF: C48.2; also elsewhere on the board
RX_MIX_BP: C40.2, P47.1, U9.7 (V3); also elsewhere on the board
TX_AMP: C55.1, C63.1, P48.1, U12.7 (V3), U14.3 (V1); also elsewhere on the board
TX_IF: C8.1; also elsewhere on the board
TX_MIX_BP: C39.2, P46.1, U9.3 (V1); also elsewhere on the board
VAA: C3.1, C4.1, C5.1, C6.1, C10.2, C16.1, C22.2, C41.1, C42.1, C52.1, C53.1, C54.1, C56.1, C160.1, C161.1, C166.1, C171.1, D11.2 (K), L2.2, L3.2, L5.1, L12.1, Q4.S, R36.2, R39.2, U1.1 (VDD), U2.1 (VDD), U4.5 (ANA_VDD1), U4.22 (ANA_VDD2), U5.1 (VDD), U6.1 (VDD), U7.1 (VDD), U10.1 (VDD), U11.1 (VDD), U13.1 (VCC), U25.1 (VCC); also elsewhere on the board
VCC: C1.1, C2.1, R5.1, R6.1, U4.19 (DIG_VDD); also elsewhere on the board

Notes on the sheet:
amplifier bypass path
switchable image reject filters
loop filter
Expected MIX_CLK is 1.8 to 3.3 V peak-to-peak at 25 to 52 MHz. It is divided down to 0.5 to 1.5 V (REF_IN).
optional alligator clip test point
mounting holes are connected to GND

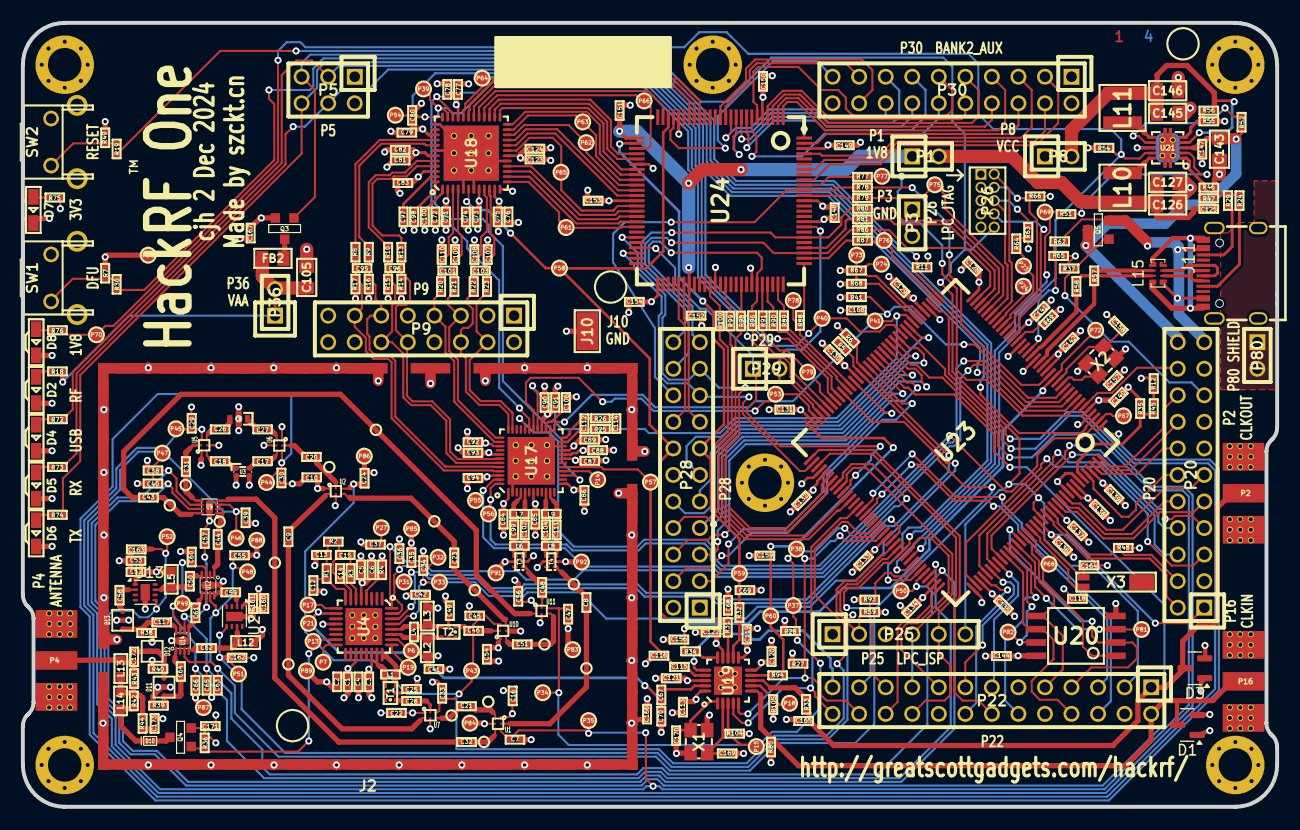
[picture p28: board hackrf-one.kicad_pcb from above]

Board: 4 copper layers, 120.0 x 75.0 mm, 437 parts (0 on the bottom side), 319 nets.

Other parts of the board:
MARK1MM, MARK1MM#2, MARK1MM#3: VAL**; GSG-MARK1MM
TESTPOINT-30MIL-MASKONLY, TESTPOINT-30MIL-MASKONLY#2, TESTPOINT-30MIL-MASKONLY#3, TESTPOINT-30MIL-MASKONLY#4, TESTPOINT-30MIL-MASKONLY#5, TESTPOINT-30MIL-MASKONLY#6, TESTPOINT-30MIL-MASKONLY#7, TESTPOINT-30MIL-MASKONLY#8, TESTPOINT-30MIL-MASKONLY#9, TESTPOINT-30MIL-MASKONLY#10, TESTPOINT-30MIL-MASKONLY#11, TESTPOINT-30MIL-MASKONLY#12, TESTPOINT-30MIL-MASKONLY#13, TESTPOINT-30MIL-MASKONLY#14, TESTPOINT-30MIL-MASKONLY#15: VAL**; GSG-TESTPOINT-30MIL-MASKONLY

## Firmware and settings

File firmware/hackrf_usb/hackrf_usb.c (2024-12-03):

/*
 * Copyright 2012-2022 Great Scott Gadgets <info@greatscottgadgets.com>
 * Copyright 2012 Jared Boone
 * Copyright 2013 Benjamin Vernoux
 *
 * This file is part of HackRF.
 *
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
 * You should have received a copy of the GNU General Public License
 * along with this program; see the file COPYING.  If not, write to
 * the Free Software Foundation, Inc., 51 Franklin Street,
 * Boston, MA 02110-1301, USA.
 */

#include <stddef.h>
#include <string.h>

#include <libopencm3/lpc43xx/ipc.h>
#include <libopencm3/lpc43xx/m4/nvic.h>
#include <libopencm3/lpc43xx/rgu.h>
#include <libopencm3/lpc43xx/timer.h>

#include <streaming.h>

#include "tuning.h"

#include "usb.h"
#include "usb_standard_request.h"

#include <rom_iap.h>
#include "usb_descriptor.h"

#include "usb_device.h"
#include "usb_endpoint.h"
#include "usb_api_board_info.h"
#include "usb_api_cpld.h"
#include "usb_api_register.h"
#include "usb_api_spiflash.h"
#include "usb_api_operacake.h"
#include "operacake.h"
#include "usb_api_sweep.h"
#include "usb_api_transceiver.h"
#include "usb_api_ui.h"
#include "usb_bulk_buffer.h"
#include "usb_api_m0_state.h"
#include "cpld_xc2c.h"
#include "portapack.h"
#include "hackrf_ui.h"
#include "platform_detect.h"
#include "clkin.h"

extern uint32_t __m0_start__;
extern uint32_t __m0_end__;
extern uint32_t __ram_m0_start__;
extern uint32_t _etext_ram, _text_ram, _etext_rom;

static usb_request_handler_fn vendor_request_handler[] = {
	NULL,
	usb_vendor_request_set_transceiver_mode,
	usb_vendor_request_write_max283x,
	usb_vendor_request_read_max283x,
	usb_vendor_request_write_si5351c,
	usb_vendor_request_read_si5351c,
	usb_vendor_request_set_sample_rate_frac,
	usb_vendor_request_set_baseband_filter_bandwidth,
#ifdef RAD1O
	NULL, // write_rffc5071 not used
	NULL, // read_rffc5071 not used
#else
	usb_vendor_request_write_rffc5071,
	usb_vendor_request_read_rffc5071,
#endif
	usb_vendor_request_erase_spiflash,
	usb_vendor_request_write_spiflash,
	usb_vendor_request_read_spiflash,
	NULL, // used to be write_cpld
	usb_vendor_request_read_board_id,
	usb_vendor_request_read_version_string,
	usb_vendor_request_set_freq,
	usb_vendor_request_set_amp_enable,
	usb_vendor_request_read_partid_serialno,
	usb_vendor_request_set_lna_gain,
	usb_vendor_request_set_vga_gain,
	usb_vendor_request_set_txvga_gain,
	NULL, // was set_if_freq
#ifdef HACKRF_ONE
	usb_vendor_request_set_antenna_enable,
#else
	NULL,
#endif
	usb_vendor_request_set_freq_explicit,
	usb_vendor_request_read_wcid, // USB_WCID_VENDOR_REQ
	usb_vendor_request_init_sweep,
	usb_vendor_request_operacake_get_boards,
	usb_vendor_request_operacake_set_ports,
	usb_vendor_request_set_hw_sync_mode,
	usb_vendor_request_reset,
	usb_vendor_request_operacake_set_ranges,
	usb_vendor_request_set_clkout_enable,
	usb_vendor_request_spiflash_status,
	usb_vendor_request_spiflash_clear_status,
	usb_vendor_request_operacake_gpio_test,
#ifdef HACKRF_ONE
	usb_vendor_request_cpld_checksum,
#else
	NULL,
#endif
	usb_vendor_request_set_ui_enable,
	usb_vendor_request_operacake_set_mode,
	usb_vendor_request_operacake_get_mode,
	usb_vendor_request_operacake_set_dwell_times,
	usb_vendor_request_get_m0_state,
	usb_vendor_request_set_tx_underrun_limit,
	usb_vendor_request_set_rx_overrun_limit,
	usb_vendor_request_get_clkin_status,
	usb_vendor_request_read_board_rev,
	usb_vendor_request_read_supported_platform,
	usb_vendor_request_set_leds,
	usb_vendor_request_user_config_set_bias_t_opts,
};

static const uint32_t vendor_request_handler_count =
	sizeof(vendor_request_handler) / sizeof(vendor_request_handler[0]);

usb_request_status_t usb_vendor_request(
	usb_endpoint_t* const endpoint,
	const usb_transfer_stage_t stage)
{
	usb_request_status_t status = USB_REQUEST_STATUS_STALL;

	if (endpoint->setup.request < vendor_request_handler_count) {
		usb_request_handler_fn handler =
			vendor_request_handler[endpoint->setup.request];
		if (handler) {
			status = handler(endpoint, stage);
		}
	}

	return status;
}

const usb_request_handlers_t usb_request_handlers = {
	.standard = usb_standard_request,
	.class = 0,
	.vendor = usb_vendor_request,
	.reserved = 0,
};

void usb_configuration_changed(usb_device_t* const device)
{
	/* Reset transceiver to idle state until other commands are received */
	request_transceiver_mode(TRANSCEIVER_MODE_OFF);
	if (device->configuration->number == 1) {
		// transceiver configuration
		led_on(LED1);
	} else {
		/* Configuration number equal 0 means usb bus reset. */
		led_off(LED1);
	}
	usb_endpoint_init(&usb_endpoint_bulk_in);
	usb_endpoint_init(&usb_endpoint_bulk_out);
}

void usb_set_descriptor_by_serial_number(void)
{
	iap_cmd_res_t iap_cmd_res;

	/* Read IAP Serial Number Identification */
	iap_cmd_res.cmd_param.command_code = IAP_CMD_READ_SERIAL_NO;
	iap_cmd_call(&iap_cmd_res);

	if (iap_cmd_res.status_res.status_ret == CMD_SUCCESS) {
		usb_descriptor_string_serial_number[0] =
			USB_DESCRIPTOR_STRING_SERIAL_BUF_LEN;
		usb_descriptor_string_serial_number[1] = USB_DESCRIPTOR_TYPE_STRING;

		/* 32 characters of serial number, convert to UTF-16LE */
		for (size_t i = 0; i < USB_DESCRIPTOR_STRING_SERIAL_LEN; i++) {
			const uint_fast8_t nibble =
				(iap_cmd_res.status_res.iap_result[i >> 3] >>
				 (28 - (i & 7) * 4)) &
				0xf;
			const char c =
				(nibble > 9) ? ('a' + nibble - 10) : ('0' + nibble);
			usb_descriptor_string_serial_number[2 + i * 2] = c;
			usb_descriptor_string_serial_number[3 + i * 2] = 0x00;
		}
	} else {
		usb_descriptor_string_serial_number[0] = 2;
		usb_descriptor_string_serial_number[1] = USB_DESCRIPTOR_TYPE_STRING;
	}
}

static bool cpld_jtag_sram_load(jtag_t* const jtag)
{
	cpld_jtag_take(jtag);
	cpld_xc2c64a_jtag_sram_write(jtag, &cpld_hackrf_program_sram);
	const bool success = cpld_xc2c64a_jtag_sram_verify(
		jtag,
		&cpld_hackrf_program_sram,
		&cpld_hackrf_verify);
	cpld_jtag_release(jtag);
	return success;
}

static void m0_rom_to_ram()
{
	uint32_t* dest = &__ram_m0_start__;

	// Calculate the base address of ROM
	uint32_t base = (uint32_t) (&_etext_rom - (&_etext_ram - &_text_ram));

	// M0 image location, relative to the start of ROM
	uint32_t src = (uint32_t) &__m0_start__;

	uint32_t len = (uint32_t) &__m0_end__ - (uint32_t) src;
	memcpy(dest, (uint32_t*) (base + src), len);
}

int main(void)
{
	// Copy M0 image from ROM before SPIFI is disabled
	m0_rom_to_ram();

	detect_hardware_platform();
	pin_setup();
	enable_1v8_power();
#ifdef HACKRF_ONE
	// Set up mixer before enabling RF power, because its
	// GPO is used to control the antenna bias tee.
	mixer_setup(&mixer);
#endif
#if (defined HACKRF_ONE || defined RAD1O)
	enable_rf_power();
#endif
	cpu_clock_init();

	/* Wake the M0 */
	ipc_halt_m0();
	ipc_start_m0((uint32_t) &__ram_m0_start__);

	if (!cpld_jtag_sram_load(&jtag_cpld)) {
		halt_and_flash(6000000);
	}

#ifdef HACKRF_ONE
	portapack_init();
#endif

#ifndef DFU_MODE
	usb_set_descriptor_by_serial_number();
#endif

	usb_set_configuration_changed_cb(usb_configuration_changed);
	usb_peripheral_reset();

	usb_device_init(0, &usb_device);

	usb_queue_init(&usb_endpoint_control_out_queue);
	usb_queue_init(&usb_endpoint_control_in_queue);
	usb_queue_init(&usb_endpoint_bulk_out_queue);
	usb_queue_init(&usb_endpoint_bulk_in_queue);

	usb_endpoint_init(&usb_endpoint_control_out);
	usb_endpoint_init(&usb_endpoint_control_in);

	nvic_set_priority(NVIC_USB0_IRQ, 255);

	hackrf_ui()->init();

	usb_run(&usb_device);

	rf_path_init(&rf_path);

	bool operacake_allow_gpio;
	if (hackrf_ui()->operacake_gpio_compatible()) {
		operacake_allow_gpio = true;
	} else {
		operacake_allow_gpio = false;
	}
	operacake_init(operacake_allow_gpio);

	// FIXME: clock detection on r9 only works when calling init twice
	if (detected_platform() == BOARD_ID_HACKRF1_R9) {
		clkin_detect_init();
		clkin_detect_init();
	}

	while (true) {
		transceiver_request_t request;

		// Briefly disable USB interrupt so that we can
		// atomically retrieve both the transceiver mode
		// and the mode change sequence number. They are
		// changed together by request_transceiver_mode()
		// called from the USB ISR.

		nvic_disable_irq(NVIC_USB0_IRQ);
		request = transceiver_request;
		nvic_enable_irq(NVIC_USB0_IRQ);

		switch (request.mode) {
		case TRANSCEIVER_MODE_OFF:
			off_mode(request.seq);
			break;
		case TRANSCEIVER_MODE_RX:
			rx_mode(request.seq);
			break;
		case TRANSCEIVER_MODE_TX:
			tx_mode(request.seq);
			break;
		case TRANSCEIVER_MODE_RX_SWEEP:
			sweep_mode(request.seq);
			break;
		case TRANSCEIVER_MODE_CPLD_UPDATE:
			cpld_update();
			break;
		default:
			break;
		}
	}

	return 0;
}

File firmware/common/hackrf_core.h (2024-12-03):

/*
 * Copyright 2012-2022 Great Scott Gadgets <info@greatscottgadgets.com>
 * Copyright 2012 Benjamin Vernoux <titanmkd@gmail.com>
 * Copyright 2012 Jared Boone <jared@sharebrained.com>
 *
 * This file is part of HackRF.
 *
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
 * You should have received a copy of the GNU General Public License
 * along with this program; see the file COPYING.  If not, write to
 * the Free Software Foundation, Inc., 51 Franklin Street,
 * Boston, MA 02110-1301, USA.
 */

#ifndef __HACKRF_CORE_H
#define __HACKRF_CORE_H

#ifdef __cplusplus
extern "C" {
#endif

#include <stdint.h>
#include <stdbool.h>

#include "si5351c.h"
#include "spi_ssp.h"

#include "max283x.h"
#include "max5864.h"
#include "mixer.h"
#include "w25q80bv.h"
#include "sgpio.h"
#include "rf_path.h"
#include "cpld_jtag.h"

/*
 * SCU PinMux
 */

/* GPIO Output PinMux */
#define SCU_PINMUX_LED1 (P4_1)  /* GPIO2[1] on P4_1 */
#define SCU_PINMUX_LED2 (P4_2)  /* GPIO2[2] on P4_2 */
#define SCU_PINMUX_LED3 (P6_12) /* GPIO2[8] on P6_12 */
#ifdef RAD1O
	#define SCU_PINMUX_LED4 (PB_6) /* GPIO5[26] on PB_6 */
#endif

#define SCU_PINMUX_EN1V8 (P6_10) /* GPIO3[6] on P6_10 */

/* GPIO Input PinMux */
#define SCU_PINMUX_BOOT0 (P1_1) /* GPIO0[8] on P1_1 */
#define SCU_PINMUX_BOOT1 (P1_2) /* GPIO0[9] on P1_2 */
#ifndef HACKRF_ONE
	#define SCU_PINMUX_BOOT2 (P2_8) /* GPIO5[7] on P2_8 */
	#define SCU_PINMUX_BOOT3 (P2_9) /* GPIO1[10] on P2_9 */
#endif
#define SCU_PINMUX_PP_LCD_TE  (P2_3)  /* GPIO5[3] on P2_3 */
#define SCU_PINMUX_PP_LCD_RDX (P2_4)  /* GPIO5[4] on P2_4 */
#define SCU_PINMUX_PP_UNUSED  (P2_8)  /* GPIO5[7] on P2_8 */
#define SCU_PINMUX_PP_LCD_WRX (P2_9)  /* GPIO1[10] on P2_9 */
#define SCU_PINMUX_PP_DIR     (P2_13) /* GPIO1[13] on P2_13 */

/* USB peripheral */
#ifdef JAWBREAKER
	#define SCU_PINMUX_USB_LED0 (P6_8)
	#define SCU_PINMUX_USB_LED1 (P6_7)
#endif

/* SSP1 Peripheral PinMux */
#define SCU_SSP1_CIPO (P1_3)  /* P1_3 */
#define SCU_SSP1_COPI (P1_4)  /* P1_4 */
#define SCU_SSP1_SCK  (P1_19) /* P1_19 */
#define SCU_SSP1_CS   (P1_20) /* P1_20 */

/* CPLD JTAG interface */
#define SCU_PINMUX_CPLD_TDO (P9_5) /* GPIO5[18] */
#define SCU_PINMUX_CPLD_TCK (P6_1) /* GPIO3[ 0] */
#if (defined HACKRF_ONE || defined RAD1O)
	#define SCU_PINMUX_CPLD_TMS (P6_5) /* GPIO3[ 4] */
	#define SCU_PINMUX_CPLD_TDI (P6_2) /* GPIO3[ 1] */
#else
	#define SCU_PINMUX_CPLD_TMS (P6_2) /* GPIO3[ 1] */
	#define SCU_PINMUX_CPLD_TDI (P6_5) /* GPIO3[ 4] */
#endif

/* CPLD SGPIO interface */
#define SCU_PINMUX_SGPIO0 (P0_0)
#define SCU_PINMUX_SGPIO1 (P0_1)
#define SCU_PINMUX_SGPIO2 (P1_15)
#define SCU_PINMUX_SGPIO3 (P1_16)
#define SCU_PINMUX_SGPIO4 (P6_3)
#define SCU_PINMUX_SGPIO5 (P6_6)
#define SCU_PINMUX_SGPIO6 (P2_2)
#define SCU_PINMUX_SGPIO7 (P1_0)
#if (defined JAWBREAKER || defined HACKRF_ONE || defined RAD1O)
	#define SCU_PINMUX_SGPIO8 (P9_6)
#endif
#define SCU_PINMUX_SGPIO9  (P4_3)
#define SCU_PINMUX_SGPIO10 (P1_14)
#define SCU_PINMUX_SGPIO11 (P1_17)
#define SCU_PINMUX_SGPIO12 (P1_18)
#define SCU_PINMUX_SGPIO14 (P4_9)
#define SCU_PINMUX_SGPIO15 (P4_10)
#define SCU_HW_SYNC_EN     (P4_8) /* GPIO5[12] on P4_8 */

/* MAX2837 GPIO (XCVR_CTL) PinMux */
#ifdef RAD1O
	#define SCU_XCVR_RXHP (P8_1) /* GPIO[] on P8_1 */
	#define SCU_XCVR_B6   (P8_2) /* GPIO[] on P8_2 */
	#define SCU_XCVR_B7   (P9_3) /* GPIO[] on P8_3 */
#endif

#define SCU_XCVR_ENABLE   (P4_6)  /* GPIO2[6] on P4_6 */
#define SCU_XCVR_RXENABLE (P4_5)  /* GPIO2[5] on P4_5 */
#define SCU_XCVR_TXENABLE (P4_4)  /* GPIO2[4] on P4_4 */
#define SCU_XCVR_CS       (P1_20) /* GPIO0[15] on P1_20 */

/* MAX5864 SPI chip select (AD_CS) GPIO PinMux */
#define SCU_AD_CS (P5_7) /* GPIO2[7] on P5_7 */

/* RFFC5071 GPIO serial interface PinMux */
#if (defined JAWBREAKER || defined HACKRF_ONE)
	#define SCU_MIXER_ENX    (P5_4) /* GPIO2[13] on P5_4 */
	#define SCU_MIXER_SCLK   (P2_6) /* GPIO5[6] on P2_6 */
	#define SCU_MIXER_SDATA  (P6_4) /* GPIO3[3] on P6_4 */
	#define SCU_MIXER_RESETX (P5_5) /* GPIO2[14] on P5_5 */
#endif
#ifdef RAD1O
	#define SCU_VCO_CE        (P5_4) /* GPIO2[13] on P5_4 */
	#define SCU_VCO_SCLK      (P2_6) /* GPIO5[6] on P2_6 */
	#define SCU_VCO_SDATA     (P6_4) /* GPIO3[3] on P6_4 */
	#define SCU_VCO_LE        (P5_5) /* GPIO2[14] on P5_5 */
	#define SCU_VCO_MUX       (PB_5) /* GPIO5[25] on PB_5 */
	#define SCU_MIXER_EN      (P6_8) /* GPIO5[16] on P6_8 */
	#define SCU_SYNT_RFOUT_EN (P6_9) /* GPIO3[5] on P6_9 */
#endif

/* RF LDO control */
#ifdef JAWBREAKER
	#define SCU_RF_LDO_ENABLE (P5_0) /* GPIO2[9] on P5_0 */
#endif

/* RF supply (VAA) control */
#ifdef HACKRF_ONE
	#define SCU_NO_VAA_ENABLE (P5_0) /* GPIO2[9] on P5_0 */
#endif
#ifdef RAD1O
	#define SCU_VAA_ENABLE (P5_0) /* GPIO2[9] on P5_0 */
#endif

/* SPI flash */
#define SCU_SSP0_CIPO  (P3_6)
#define SCU_SSP0_COPI  (P3_7)
#define SCU_SSP0_SCK   (P3_3)
#define SCU_SSP0_CS    (P3_8) /* GPIO5[11] on P3_8 */
#define SCU_FLASH_HOLD (P3_4) /* GPIO1[14] on P3_4 */
#define SCU_FLASH_WP   (P3_5) /* GPIO1[15] on P3_5 */

/* RF switch control */
#ifdef HACKRF_ONE
	#define SCU_HP            (P4_0)  /* GPIO2[0] on P4_0 */
	#define SCU_LP            (P5_1)  /* GPIO2[10] on P5_1 */
	#define SCU_TX_MIX_BP     (P5_2)  /* GPIO2[11] on P5_2 */
	#define SCU_NO_MIX_BYPASS (P1_7)  /* GPIO1[0] on P1_7 */
	#define SCU_RX_MIX_BP     (P5_3)  /* GPIO2[12] on P5_3 */
	#define SCU_TX_AMP        (P5_6)  /* GPIO2[15] on P5_6 */
	#define SCU_TX            (P6_7)  /* GPIO5[15] on P6_7 */
	#define SCU_MIX_BYPASS    (P6_8)  /* GPIO5[16] on P6_8 */
	#define SCU_RX            (P2_5)  /* GPIO5[5] on P2_5 */
	#define SCU_NO_TX_AMP_PWR (P6_9)  /* GPIO3[5] on P6_9 */
	#define SCU_AMP_BYPASS    (P2_10) /* GPIO0[14] on P2_10 */
	#define SCU_RX_AMP        (P2_11) /* GPIO1[11] on P2_11 */
	#define SCU_NO_RX_AMP_PWR (P2_12) /* GPIO1[12] on P2_12 */
#endif
#ifdef RAD1O
	#define SCU_BY_AMP          (P1_7)  /* GPIO1[0] on P1_7 */
	#define SCU_BY_AMP_N        (P2_5)  /* GPIO5[5] on P2_5 */
	#define SCU_TX_RX           (P2_10) /* GPIO0[14] on P2_10 */
	#define SCU_TX_RX_N         (P2_11) /* GPIO1[11] on P2_11 */
	#define SCU_BY_MIX          (P2_12) /* GPIO1[12] on P2_12 */
	#define SCU_BY_MIX_N        (P5_1)  /* GPIO2[10] on P5_1 */
	#define SCU_LOW_HIGH_FILT   (P5_2)  /* GPIO2[11] on P5_2 */
	#define SCU_LOW_HIGH_FILT_N (P5_3)  /* GPIO2[12] on P5_3 */
	#define SCU_TX_AMP          (P5_6)  /* GPIO2[15] on P5_6 */
	#define SCU_RX_LNA          (P6_7)  /* GPIO5[15] on P6_7 */
#endif
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

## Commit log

2024-09-25 After DRC fixes. Lots of ERC problems still
    [baseband.kicad_sch, baseband.sch, frontend.kicad_sch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]
2024-09-26 Attempts to resolve wierd legacy ERC errors
    [baseband.kicad_sch, frontend.kicad_sch, hackrf-one.kicad_sch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]
2024-09-26 kicad_sch: fix annotations
    For some reason, this was largely missing annotations. KiCad will
    happily reannotate the schematics, but it renumbered everything.
    Fix annotations while keeping the same annotations.
    [baseband.kicad_sch, frontend.kicad_sch, mcu.kicad_sch]
2024-09-26 mcu: add power flags
    Add flags to the power nets to mark them as such.
    [mcu.kicad_sch]
2024-09-26 Updated PWR_FLAG symbols
    [mcu.kicad_sch]
2024-09-26 After update to Kicad V8
    [hackrf-one.kicad_pcb]
2024-09-26 Fixed minor DRCs
    [baseband.kicad_sch, frontend.kicad_sch, mcu.kicad_sch]
2024-09-26 Changed to USB-C connector
    [hackrf-one.kicad_pcb, mcu.kicad_sch]
2024-09-26 Leave ID pin open, to signal it's a USB device
    [hackrf-one.kicad_pcb, mcu.kicad_sch]
2024-09-26 Changed from SMP1330 to CLA4611 to improve performance to 6GHz
    [frontend.kicad_sch, hackrf-one.kicad_pcb]
2024-09-26 Changed limiter to CLA4611. Added Schottky bias tee diode
    [frontend.kicad_sch, hackrf-one.kicad_pcb]
2024-10-10 Made USB-C connector poke out 0.7mm
    [hackrf-one.kicad_pcb]
2024-10-10 Change USB protection to ECMF02-4CMX8
    [hackrf-one.kicad_pcb, mcu.kicad_sch]
2024-10-12 Made draft production files for 2025 R10+
    [baseband.kicad_sch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]
2024-10-24 Updated to move USB-C connector to save location as OpenSourceSDRLab's R10C
    [baseband.kicad_sch, frontend.kicad_sch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]
2024-11-02 Added updated schematic PDF
2024-12-01 Made design changes to indicate version 15. Correct Q3/4/5 part-no and LPF rotation
    [baseband.kicad_sch, frontend.kicad_sch, hackrf-one.kicad_pcb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]
2024-12-03 Updated to latest GSG firmware, host, tools, docs files
    [LPC4330_SGPIO_SignalGenerator_Measurements.ods]
2024-12-03 When the ADC board_revision value doesn't match an expected value, return all six bits in a special subrange for diagnostics
    [platform_detect.c]
2024-12-03 Added U15 version detection resistors, corrected FETs and U3 rotation
    [frontend.kicad_sch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]
2025-08-09 Fixed clang-format warning (third time lucky?)
    [platform_detect.c]
2025-08-09 Revert "Fixed clang-format warning (third time lucky?)"
    This reverts commit e39d3b243e53b276f1cc0b95172384f651f64155.
    [platform_detect.c]
2025-08-09 Fixed clang-format warning (yet again)
    [platform_detect.c]

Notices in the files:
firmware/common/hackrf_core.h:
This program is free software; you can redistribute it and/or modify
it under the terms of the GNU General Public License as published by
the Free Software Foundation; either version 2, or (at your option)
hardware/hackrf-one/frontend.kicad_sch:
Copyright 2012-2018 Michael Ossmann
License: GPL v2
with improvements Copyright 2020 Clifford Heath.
